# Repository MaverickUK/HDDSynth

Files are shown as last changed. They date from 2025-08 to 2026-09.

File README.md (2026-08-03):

# HDD Synth
<div style="background: white; display: inline-block; padding: 8px;">
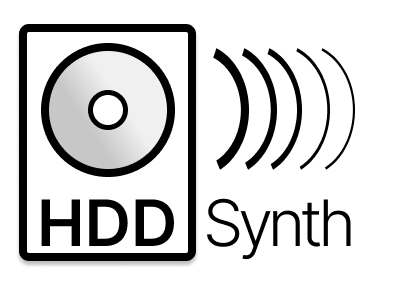
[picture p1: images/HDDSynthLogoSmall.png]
  
</div>

### Recreates the sound of mechanical spinning HDDs on retro PCs that use a solid state drive.

Inspired by seeing the HDD Clicker project and wanting to more faithfully recreate the sound of old mechanical hard drives spinning up and accessing data. Because the hard drive sounds come from samples, it's possible to replace them with any hard drive recording you'd like or something completely different!

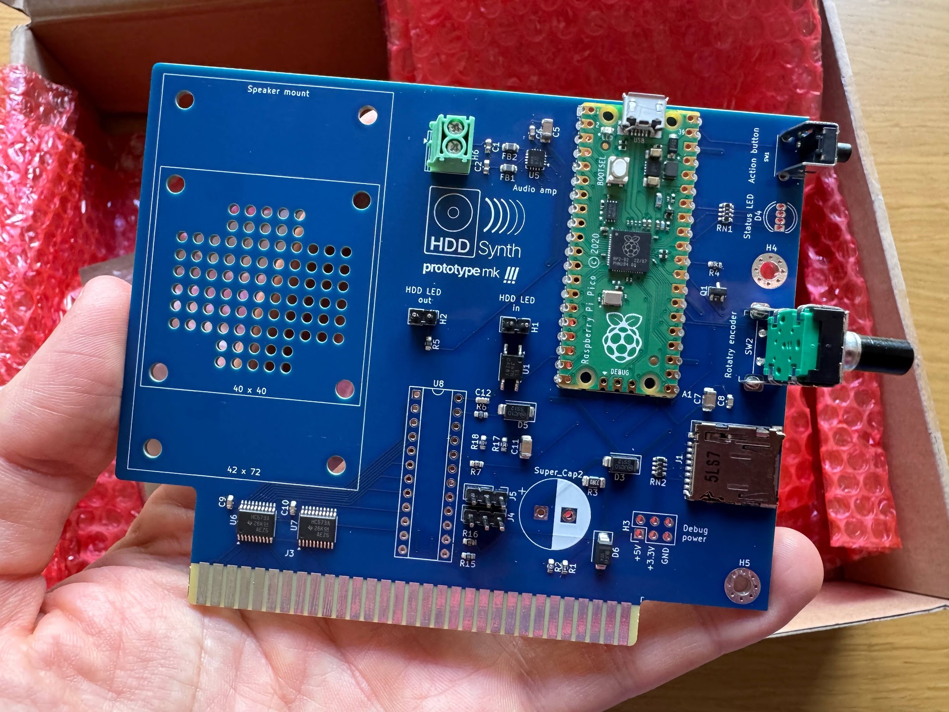
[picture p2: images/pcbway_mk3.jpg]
Photo of the HDD Synth MKIII prototype PCB
  

## Features

- **Sample based recreation** of mechanical hard disk drives operating sounds
 - **Spin up** when PC is turned on
 - **Idle hum** whilst standing by
 - **Access** clicks and crackcles
 - **Spin down** when PC is turned off
- **SD card** to hold multiple HDD sample packs, to recreate the sound of different mechanical hard disk drives
- **Volume control** to make it very loud or silent
- **Balance** to alter the amount of idle to access sounds
- **CompactFlash adapte**r to act as full HDD replacement
- **HDD detection** via HDD LED

## Progress
### ✅ [Phase 1: Breadboard prototype](1_breadboard/README.md) 
### 🔄 Phase 2: PCB prototypes
#### [MKI prototype](2_prototype_mk1/)
Initial ISA PCB test

#### [MKII prototype](2_prototype_mk2/) 
Adds volume control, ability to change sample pack, spin down

#### [MKIII prototype](2_prototype_mk3/) 
Adds ISA based HDD detection, metal back bracket, external status LED, 3.5" drive bay adapter kit, balance (between access and idle sound)

#### [MKIV prototype](2_prototype_mk4/) 
Smaller and more cost effective than the MKIII. Adds a CompactFlash adapter so can act as full HDD replacement. Headless by default, optional controls and OLED screen can be added

### 🌱 Phase 3: PCB final 
*Awaiting completion of prototyping stages*

## Media
[View gallery](media.md)

<!--
## Usage

## License
-->

## Contact
Peter Bridger at [maverickuk@gmail.com](maverickuk@gmail.com)

Project website at [www.strifestreams.com/hddsynth](https://www.strifestreams.com/hddsynth)

## Resources
- [ISA System Architecture by Tom Shanley](https://archive.org/details/ISA_System_Architecture)
- [Intel ISA Bus Specification](https://archive.org/details/bitsavers_intelbusSpep89_3342148)
- [ISA bus technical summary](http://wearcam.org/ece385/lecture6/isa.htm)

## Acknowledgments
- Inspired by the [HDD Clicker project](https://www.serdashop.com/HDDClicker)
- A big thanks to [Ian Scott of PicoGUS fame](https://picog.us/) for sharing his resource sources and knowledge of using the Pi Pico with the ISA bus which gave me the confidence to take this project to the next level
- [Marten Electric](https://www.martenelectric.cz/) for the excellent ISA prototyping boards which made it very easy to wire up the Pico to my computer

### PCBWay
Thanks to [PCBWay](https://www.pcbway.com) for their PCB manufacturing and assembly services. This is my first PCB based project and they've been a great way to get quality PCB prototypes created along with component assembly at competitive prices. Recommended if you're thinking about creating a simular project yourself.

## License
This project is dual-licensed:

- **Software/firmware** is licensed under the [GNU GPL v3.0](LICENSE-CODE).
- **Hardware designs** (schematics, PCB files, BOM) are licensed under
  [CC BY-NC-SA 4.0](LICENSE-HARDWARE) — free for personal, non-commercial
  use and modification, but commercial use requires my permission.

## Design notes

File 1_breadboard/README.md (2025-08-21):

## HDD Synth
### Phase 1: Breadboard based prototypes

Initial work to prove the concept is possible using breadboards and other prototyping hardware along with a series of software based PoCs.

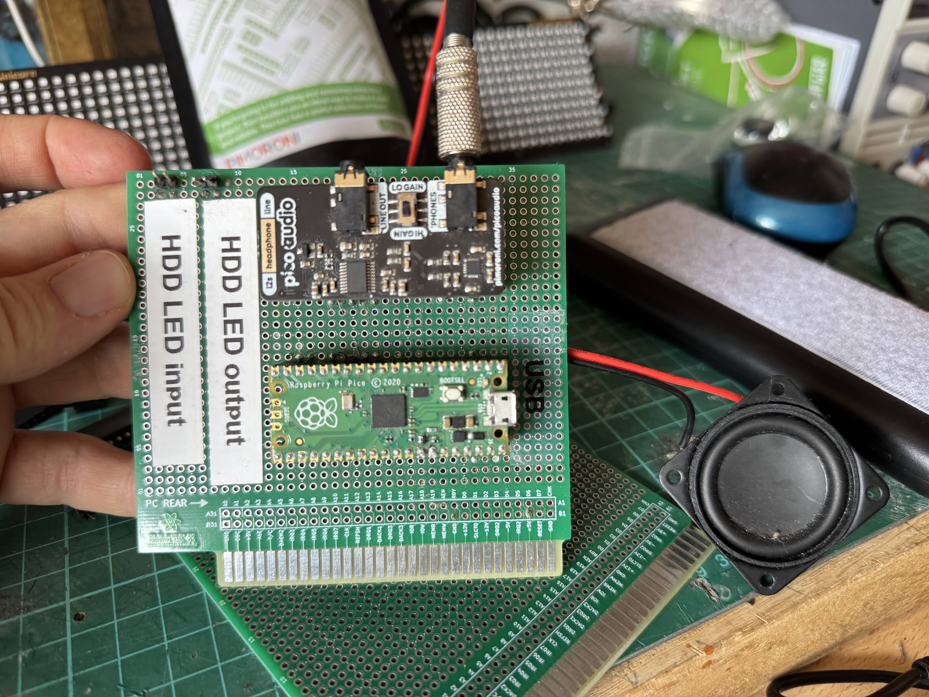
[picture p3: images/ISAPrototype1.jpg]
Prototype ISA board


## Hardware Requirements

### Core Components
- **Raspberry Pi Pico** (RP2040)
- **Pico Audio Pack** for audio output
- **SD Card Module** (SPI interface)
- **ISA Prototyping Board** (e.g., Marten Electric ISA prototyping board)

### Pin Connections

#### ISA Bus Monitoring
| Signal | Pico GPIO | Description |
|---|---|---|
| A0 | GPIO 0 | ISA Address Bus A0 |
| A1 | GPIO 1 | ISA Address Bus A1 |
| A2 | GPIO 2 | ISA Address Bus A2 |
| A3 | GPIO 3 | ISA Address Bus A3 |
| A4 | GPIO 4 | ISA Address Bus A4 |
| A5 | GPIO 5 | ISA Address Bus A5 |
| A6 | GPIO 6 | ISA Address Bus A6 |
| A7 | GPIO 7 | ISA Address Bus A7 |
| A8 | GPIO 8 | ISA Address Bus A8 |
| A9 | GPIO 9 | ISA Address Bus A9 |
| IOR | GPIO 10 | ISA I/O Read signal |
| IOW | GPIO 11 | ISA I/O Write signal |

#### SD Card (SPI)
| Signal | Pico GPIO | Description |
|---|---|---|
| SCK | GPIO 14 | SPI Clock |
| MOSI | GPIO 15 | SPI MOSI |
| MISO | GPIO 12 | SPI MISO |
| CS | GPIO 13 | SPI Chip Select |

#### Audio Output (Pico Audio Pack)
| Signal | Pico GPIO | Description |
|---|---|---|
| BCK | GPIO 26 | Bit Clock (SCK) |
| WS | GPIO 27 | Word Select (WS) |
| SD | GPIO 28 | Serial Data (SD) |
| MUTE | GPIO 22 | Mute control (active low) |

## Audio Sample Files

The following WAV files must be placed on the SD card:

| Filename | Description | Usage |
|---|---|---|
| `hdd_spinup.wav` | HDD spinup sound | Played once when system starts |
| `hdd_idle.wav` | HDD idle sound | Looped continuously when no HDD activity |
| `hdd_access.wav` | HDD access sound | Played during HDD read/write operations |

**Audio Format Requirements:**
- **Sample Rate**: 16 kHz
- **Bit Depth**: 16-bit
- **Channels**: Stereo (2 channels)
- **Format**: WAV (PCM)

## Installation & Setup

### 1. Firmware
- Install MicroPython firmware on your Raspberry Pi Pico
- Download from: https://micropython.org/download/rp2-pico/

### 2. Dependencies
- Copy `sdcard.py` to your Pico's `lib/` directory
- Download from: https://github.com/micropython/micropython/tree/master/drivers/sdcard

### 3. Audio Files
- Format an SD card as FAT32
- Copy the required WAV files to the root directory
- Insert the SD card into the SD card module

### 4. Hardware Assembly
- Connect the Pico to the ISA prototyping board according to the pin mapping above
- Connect the Pico Audio Pack to the Pico
- Connect the SD card module to the Pico
- Mount the ISA board in your PC's ISA slot

### 5. Software
- Copy `main.py` and `config.py` to your Pico
- The system will auto-execute `main.py` on boot

## Configuration

Edit `config.py` to customize:
- Pin assignments for different hardware setups
- Audio settings (sample rate, bit depth, channels)
- HDD activity detection parameters
- Audio file names

## Usage

1. **Power On**: The system will automatically start monitoring the ISA bus
2. **Spinup**: HDD spinup sound plays once during initialization
3. **Idle**: HDD idle sound loops continuously when no activity is detected
4. **Access**: HDD access sound plays during read/write operations
5. **Real-time Response**: Audio changes immediately based on detected HDD activity

## How It Works

### ISA Bus Monitoring
The system uses PIO (Programmable I/O) state machines to monitor the ISA bus at high speed:
- **State Machine 0**: Monitors IOR (I/O Read) signals
- **State Machine 1**: Monitors IOW (I/O Write) signals
- **Address Capture**: Captures A0-A9 address lines when control signals are active
- **HDD Detection**: Identifies HDD activity by monitoring ports 0x1F0 (data) and 0x1F7 (status)

### Audio Management
- **Spinup**: Played once at startup to simulate HDD initialization
- **Idle**: Looped continuously when no HDD activity is detected
- **Access**: Interrupts idle sound and plays during HDD operations
- **Seamless Transitions**: Audio switches instantly between states

### SD Card Integration
- **File Loading**: Audio files loaded directly from SD card
- **Real-time Playback**: No buffering delays for immediate response
- **Easy Customization**: Replace WAV files to change sounds

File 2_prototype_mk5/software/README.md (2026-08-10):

# HDD Synth: Prototype MKIII
Written in CircuitPython for Pi Pico

## Startup Behavior

The SDCARD_REQUIRED setting (configured in settings.py, default False) controls startup behavior:

- **SDCARD_REQUIRED = True (strict mode):** Device requires SD card to start. If no SD card is detected, it will play a NO_SD_CARD beep and not run.
- **SDCARD_REQUIRED = False (relaxed mode):** Device can start without SD card if a sample pack is already installed internally. If no sample pack is installed, it will play a PACK_NOT_FOUND beep. When running without an SD card, the action button is disabled (sample pack switching and factory reset are unavailable).

## settings.json
If this file exists on the SD card install in the HDD Synth it will be read at startup and will override the default HDD Synth settings.

This can be used to configure the HDD Synth to operate in headless mode without any physical controls.

### Settings
- **SIMULATION_MODE:** Boolean. True will simulate HDD activity for testing without actual HDD, False will use real HDD activity signal. Default False
- **PLAY_SPINUP:** Boolean. True will play spinup sound at power on, False will not. Default True
- **PLAY_SPINDOWN:** Boolean. True will play spindown sound at power off, False will not. Default True
- **PLAY_IDLE:** Boolean. True will play idle sound continously, False will not. Default True
- **ACCESS_HOLD_TIME_MS:** Integer. How long to play the access sound for after detect activity stops in milliseconds. Default 500
- **VOLUME_DEFAULT:** Number between 0 and 1. 0 is silence, 1 is full volume. Default 0.5
- **BALANCE_DEFAULT:** Number between 0 and 1. 0 = idle only, 1 = access only, 0.5 balanced idle and access. Default 0.5
- **SAMPLE_PACK:** Name of the sample pack directory on the SD card to use. E.g. If /samples/ibm is desired, this should be set to ibm
- **SDCARD_CACHE_SAMPLES:** Boolean. True will copy the sample pack from the SD card to the Pico's internal flash before playback — the SD card can then be removed after boot. False will stream samples directly from the SD card, which is faster to start but requires the SD card to remain inserted. Default False
- **ACTIVITY_LED_ENABLED:** Boolean. True lights the RGB status LED while the HDD is being accessed, False disables the activity indication entirely. Default True
- **ACTIVITY_LED_COLOUR:** The colour shown on the RGB status LED during HDD activity. Either a hex string such as `"#00FF00"` or an array of three 0-255 values such as `[0, 255, 0]`. Default green
- **RGB_LED_BRIGHTNESS:** Number between 0 and 1. Master brightness applied to every colour the RGB status LED shows — activity, error and operation flashes, and the busy indicator. 0 turns the LED off entirely, 1 is full brightness. Default 0.5

### Example settings.json
```
{
    "SIMULATION_MODE": false,
    "PLAY_SPINUP": false,
    "PLAY_SPINDOWN": true,
    "PLAY_IDLE": true,
    "ACCESS_HOLD_TIME_MS": 150,
    "VOLUME_DEFAULT": 0.7,
    "BALANCE_DEFAULT": 0.5,
    "SAMPLE_PACK": "my_pack_name",
    "SDCARD_CACHE_SAMPLES": false,
    "ACTIVITY_LED_ENABLED": true,
    "ACTIVITY_LED_COLOUR": "#00FF00",
    "RGB_LED_BRIGHTNESS": 0.5
}
```

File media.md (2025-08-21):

# HDD Synth media

## Phase 2: PCB prototype

KiCad 3D render of MK1 prototype board

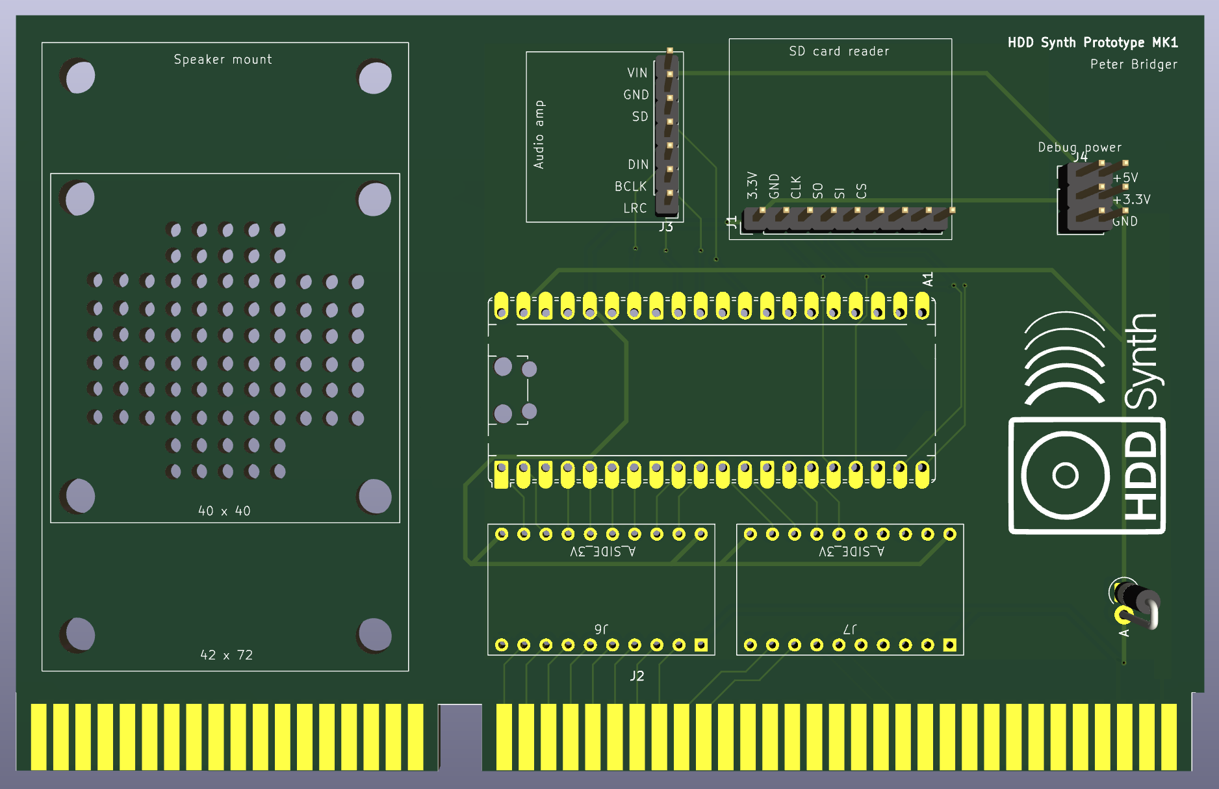
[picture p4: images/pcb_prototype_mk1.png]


KiCad PCB layout of MK1 prototype board

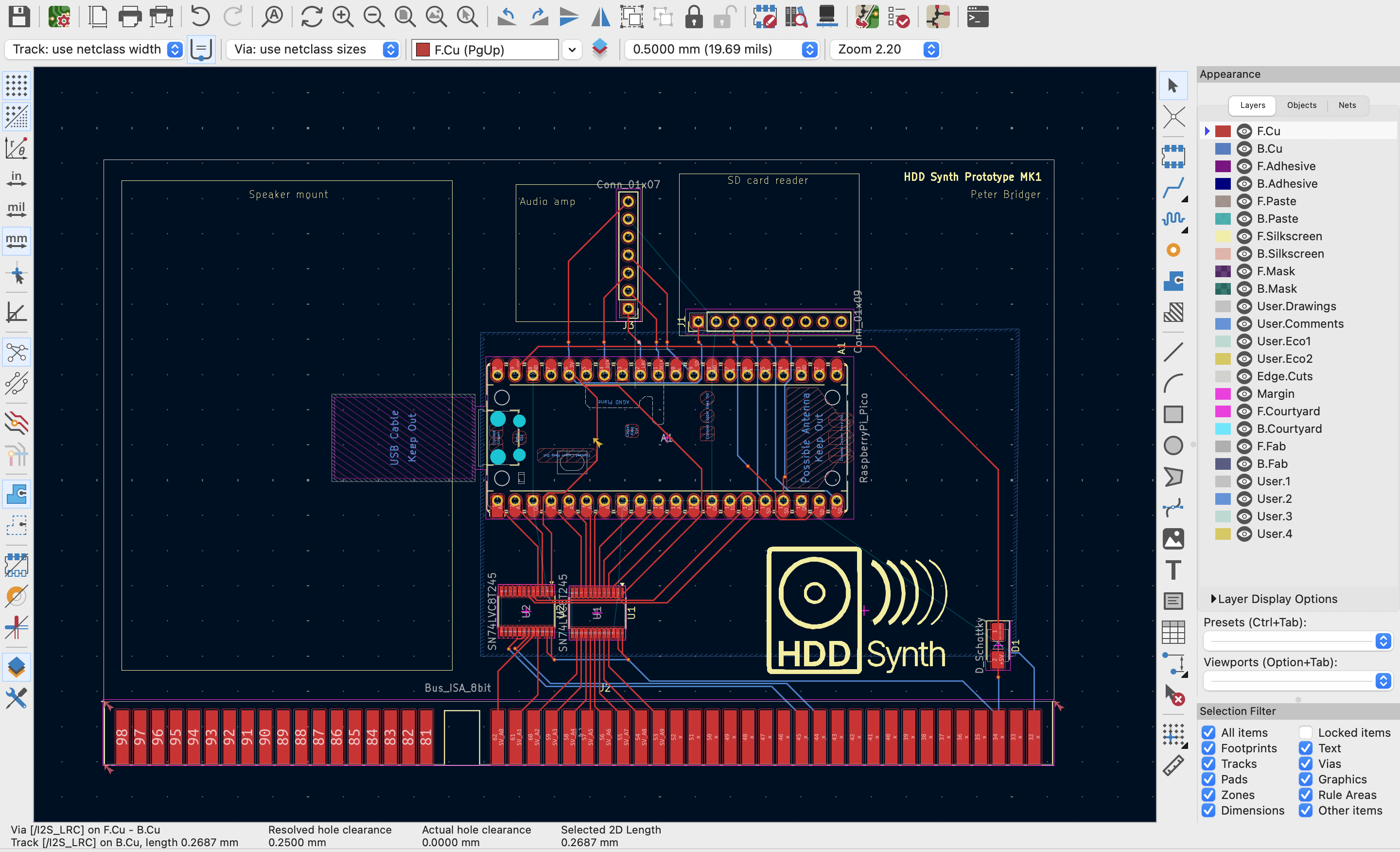
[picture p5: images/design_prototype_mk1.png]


## Phase 1: Breadboard prototype

### Powered ISA board
Initial prototype of an ISA board that can be mounted within the PC to draw power from the ISA +5v rail

Prototype ISA board

### HDD LED detection prototype board
Using detection of the PC HDD controller activity LED voltage to detect activity and drive the HDD Synth

Proof of concept video (https://youtu.be/yZhKAbbrKRM)

### Audio samples proof of concept
Not connected to a PC, but purely to validate if the Pi Pico could produce a convincing sounding HDD subsitution. I'd say it does!

Proof of concept video (https://youtu.be/V0S9wBl7J3U)

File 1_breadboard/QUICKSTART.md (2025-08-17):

# HDD Synth - Quick Start Guide

## What You Need

### Hardware
- [ ] Raspberry Pi Pico
- [ ] Pico Audio Pack
- [ ] SD Card Module (SPI)
- [ ] ISA Prototyping Board
- [ ] MicroSD Card (FAT32 formatted)
- [ ] Audio samples (WAV files)
- [ ] 2 x TXS0108E level shifter (Convert 5v ISA signals to 3.3v Pico)
- [ ] Prototyping ISA board

### Software
- [ ] MicroPython firmware on Pico
- [ ] `sdcard.py` library
- [ ] HDD Synth files

## Setup

### Step 0: Aquire prototype ISA PCB
Contains the TXS level shifters connected to the ISA address bus, IOR and IOW lines

### Step 1: Prepare Your Pico
1. Download MicroPython firmware: https://micropython.org/download/rp2-pico/
2. Hold BOOTSEL button and plug in Pico
3. Copy firmware to Pico (it will appear as USB drive)
4. Pico will restart with MicroPython

### Step 2: Install Dependencies
1. Download `sdcard.py` from: https://github.com/micropython/micropython/tree/master/drivers/sdcard
2. Copy to Pico's `lib/` folder (create if it doesn't exist)

### Step 3: Prepare Audio Files
1. Format SD card as FAT32
2. Copy these WAV files to root directory:
   - `hdd_spinup.wav`
   - `hdd_idle.wav`
   - `hdd_access.wav`
3. Insert SD card into module

### Step 4: Wire Up Hardware
Connect according to this pin map:

| Component | Pico GPIO | Signal |
|---|---|---|
| ISA A0-A9 | GPIO 0-9  | Address bus |
| ISA IOR | GPIO 10 | I/O Read |
| ISA IOW | GPIO 11 | I/O Write |
| SD SCK | GPIO 14 | SPI Clock |
| SD MOSI | GPIO 15 | SPI MOSI |
| SD MISO | GPIO 12 | SPI MISO |
| SD CS | GPIO 13 | SPI CS |
| Audio BCK | GPIO 26 | Bit Clock |
| Audio WS  | GPIO 27 | Word Select |
| Audio SD  | GPIO 28 | Serial Data |
| Audio MUTE| GPIO 22 | Mute control |

### Step 5: Upload Code
1. Copy `main.py` to Pico
2. Copy `config.py` to Pico
3. The system will auto-start with `main.py`

### Step 6: Test
1. Power on your Pico
2. You should hear the HDD spinup sound
3. Then idle sound will loop continuously
4. When you access files on your PC, you should hear access sounds

## Troubleshooting

### No Audio Output
- Check Pico Audio Pack connections
- Verify MUTE pin is connected to GPIO 22
- Ensure audio files are 16kHz, 16-bit, stereo WAV

### SD Card Not Found
- Check SPI connections (SCK, MOSI, MISO, CS)
- Verify SD card is FAT32 formatted
- Ensure audio files are in root directory

### ISA Bus Not Detected
- Verify all address pins (A0-A9) are connected
- Check IOR and IOW connections
- Ensure ISA board is properly seated

### Audio Cuts Out
- Check power supply (Pico needs stable 5V)
- Verify SD card is high-speed (Class 10+)
- Reduce audio buffer size in config if needed

## Customization

### Change Audio Files
1. Replace WAV files on SD card
2. Update filenames in `config.py`
3. Ensure new files match format requirements

### Adjust Pin Assignments
1. Edit `config.py`
2. Modify pin numbers as needed
3. Restart Pico

### Tune Detection Sensitivity
1. Adjust `ACTIVITY_THRESHOLD` in config
2. Modify `ACTIVITY_TIMEOUT_MS` for response speed
3. Test with your specific hardware

## Need Help?

- Check the main README.md for detailed information
- Review pin connections carefully
- Test with `test.py` first
- Ensure all hardware is properly connected

## Success!

Once working, your HDD Synth will:
- ✅ Play spinup sound on power-up
- ✅ Loop idle sound when no activity
- ✅ Play access sounds during HDD operations
- ✅ Respond in real-time to ISA bus activity
- ✅ Work as a plug-and-play ISA card

Enjoy your authentic mechanical HDD sounds! 🎵

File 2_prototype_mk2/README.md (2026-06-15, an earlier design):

## HDD Synth
### Prototype MKII

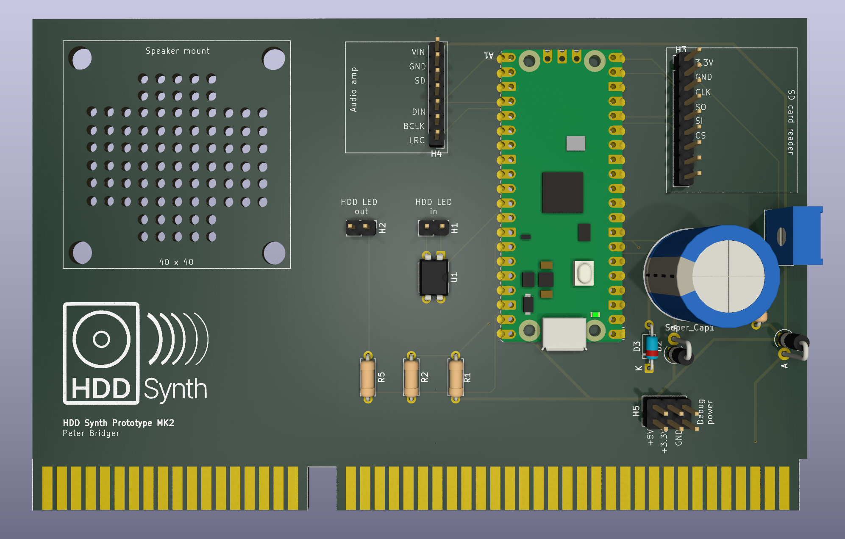
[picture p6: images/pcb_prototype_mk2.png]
KiCad PCB 3D render


#### Hardware
Designed in KiCad and manufacufered by PCBWay

Uses through hole components and breakout boards for the SD card reader and audio amp

#### Software
Runs CircuitPython for ease of development

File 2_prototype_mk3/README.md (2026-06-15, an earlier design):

## HDD Synth
### Prototype MKIII

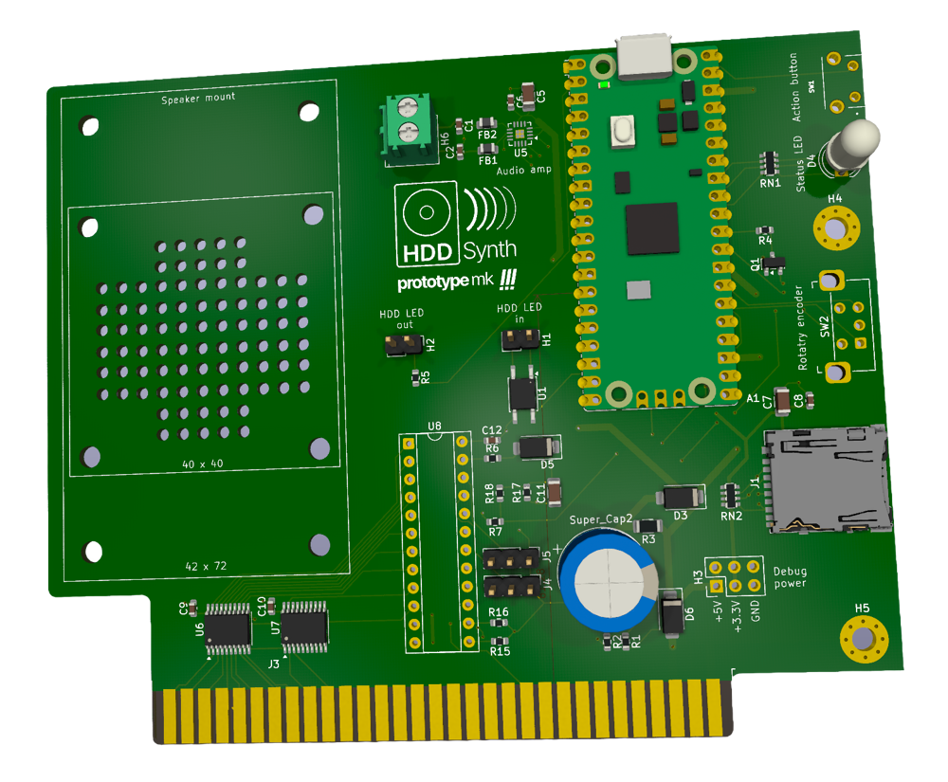
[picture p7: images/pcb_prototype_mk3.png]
KiCad PCB 3D render


#### Hardware
Designed in KiCad and manufacufered by PCBWay with factory assembly of components

Uses mostly surface mounted components for ease of automated assembly and reduction in size and cost

#### Software
Runs CircuitPython for ease of development

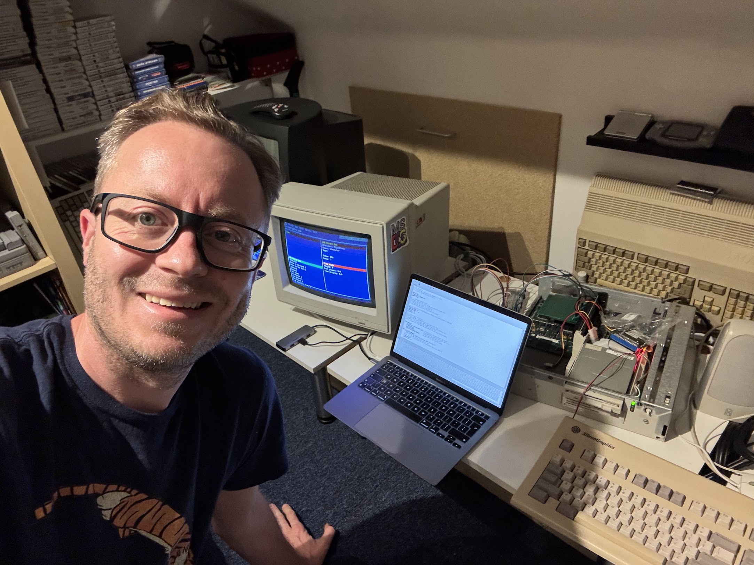
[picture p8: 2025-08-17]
images/HDDSynth first.jpg

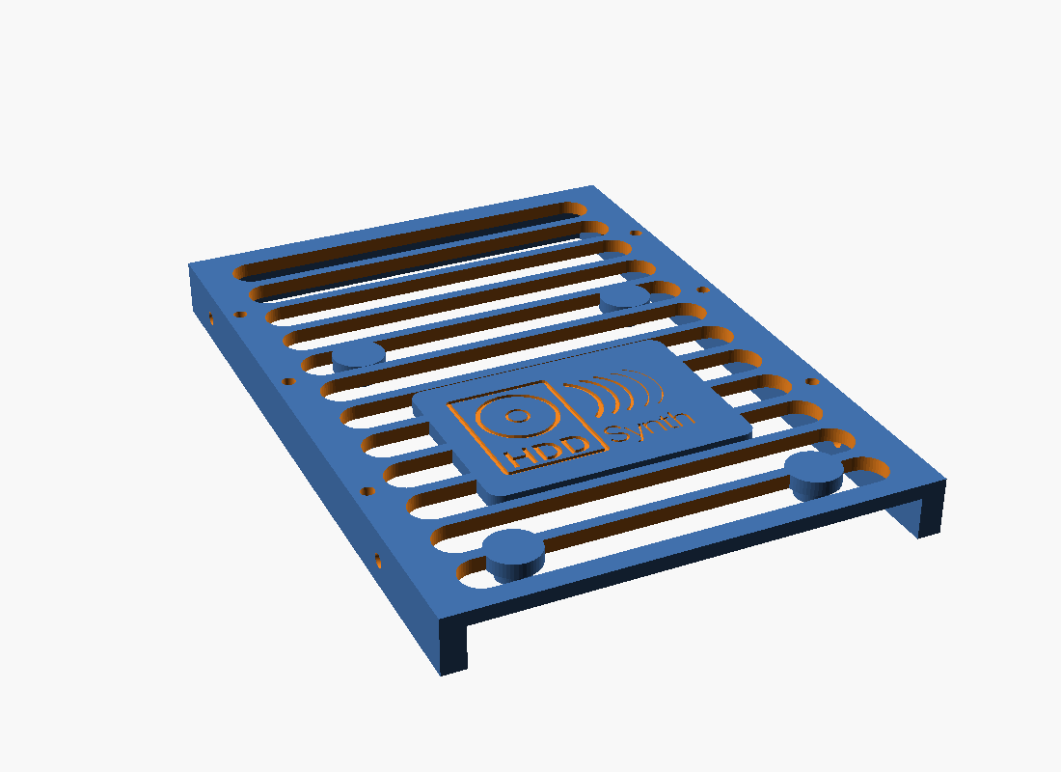
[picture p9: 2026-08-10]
2_prototype_mk5/3d_models/drive_bay/tray_iso.png

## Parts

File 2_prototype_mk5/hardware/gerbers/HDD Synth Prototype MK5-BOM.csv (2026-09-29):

Reference | Qty | Value | DNP | Exclude from BOM | Exclude from Board | LCSC Part Number | Footprint | Datasheet | Description
C1,C6,C26 | 3 | 0.1uF |  |  |  | C14663 | Capacitor_SMD:C_0603_1608Metric |  | Unpolarized capacitor
C2,C5 | 2 | 10uF |  |  |  | C13585 | Capacitor_SMD:C_1206_3216Metric |  | Unpolarized capacitor
C3,C4 | 2 | 1nF |  |  |  | C1588 | Capacitor_SMD:C_0603_1608Metric |  | Unpolarized capacitor, small symbol
C7,C8 | 2 | 15p |  |  |  | C1548 | Capacitor_SMD:C_0402_1005Metric
C10,C14,C17,C18,C19,C20,C21,C22,C23,C24,C27,C33 | 12 | 100nF |  |  |  | C1525 | Capacitor_SMD:C_0402_1005Metric
C12,C13 | 2 | 4.7uF |  |  |  | C23733 | RP2350:C_0402_1005Metric_small_pads
C15,C16 | 2 | 4.7uF |  |  |  | C23733 | Capacitor_SMD:C_0402_1005Metric
C25,C28,C30,C36,C37 | 5 | 10uF |  |  |  | C15850 | Capacitor_SMD:C_0805_2012Metric
C29,C31,C32,C39 | 4 | 22uF |  |  |  | C45783 | Capacitor_SMD:C_0805_2012Metric
C34 | 1 | 4.7nF |  |  |  |  | Capacitor_SMD:C_0402_1005Metric
C35 | 1 | 1uF |  |  |  |  | Capacitor_SMD:C_0402_1005Metric
C38 | 1 | 100uF |  |  |  | C134801 | Capacitor_SMD:CP_Elec_6.3x7.7 |  | Polarized capacitor
Card1 | 1 | TF-015 |  |  |  | C113206 | easyeda2kicad:TF-SMD_TF-015 | https://lcsc.com/product-detail/Card-Sockets_TF-015_C113206.html
D1 | 1 | SMAJ5.0A |  |  |  |  | Diode_SMD:D_SMA |  | Zener diode
D3 | 1 | 1N4148W |  |  |  | C81598 | Diode_SMD:D_SOD-123 | https://www.vishay.com/docs/85748/1n4148w.pdf | 75V 0.15A Fast Switching Diode, SOD-123
FB1,FB2 | 2 | FerriteBead_Small |  |  |  | C85840 | Inductor_SMD:L_0805_2012Metric |  | Ferrite bead, small symbol
H1,H2,H3,H13,H14 | 5 | Conn_01x02 |  |  |  | C124375 | Connector_PinHeader_2.54mm:PinHeader_1x02_P2.54mm_Vertical |  | Generic connector, single row, 01x02, script generated (kicad-library-utils/schlib/autogen/connector/)
J2 | 1 | Conn_01x03 |  |  |  | C49257 | Connector_PinHeader_2.54mm:PinHeader_1x03_P2.54mm_Vertical |  | Generic connector, single row, 01x03, script generated (kicad-library-utils/schlib/autogen/connector/)
J4 | 1 | USB_C_Receptacle_USB2.0_16P |  |  |  | C165948 | Connector_USB:USB_C_Receptacle_HRO_TYPE-C-31-M-12 |  | USB 2.0-only 16P Type-C Receptacle connector
J6 | 1 | Conn_01x04_Pin |  |  |  | C124378 | Connector_PinHeader_2.54mm:PinHeader_1x04_P2.54mm_Vertical |  | Generic connector, single row, 01x04, script generated
J7 | 1 | Conn_01x05 |  |  |  | C124379 | Connector_PinHeader_2.54mm:PinHeader_1x05_P2.54mm_Vertical |  | Generic connector, single row, 01x05, script generated (kicad-library-utils/schlib/autogen/connector/)
L1 | 1 | 3.3u |  |  |  | C42411119 | RP2350:L_pol_2016
L2 | 1 | 2.2 µH |  |  |  | C167804 | easyeda2kicad:IND-SMD_L4.0-W4.0_FNR40XXS |  | Inductor
L3 | 1 | FNR4018S1R5MT |  |  |  | C167802 | easyeda2kicad:IND-SMD_L4.0-W4.0_FNR40XXS | https://lcsc.com/product-detail/Power-Inductors_1-5uH-20_C167802.html
LED1 | 1 | XL-3528RGBW-HM |  |  |  | C2843813 | Custom:LED-SMD_4P-L3.2-W2.8-LS3.5-XL-3528RGBW-HM5 | https://www.lcsc.com/datasheet/C2843813.pdf
Q1 | 1 | 2N7002 |  |  |  | C8545 | Package_TO_SOT_SMD:SOT-23 | https://www.onsemi.com/pub/Collateral/NDS7002A-D.PDF | 0.115A Id, 60V Vds, N-Channel MOSFET, SOT-23
R1,R2 | 2 | 330R |  |  |  | C23138 | Resistor_SMD:R_0603_1608Metric |  | Resistor
R7 | 1 | 0 |  |  |  | C17168 | Resistor_SMD:R_0402_1005Metric
R8,R11 | 2 | 5.1K |  |  |  | C25905 | Resistor_SMD:R_0402_1005Metric |  | Resistor
R10,R12,R14,R26 | 4 | 1K |  |  |  | C11702 | Resistor_SMD:R_0402_1005Metric |  | Resistor
R13,R18,R20 | 3 | 33R |  |  |  | C25105 | Resistor_SMD:R_0402_1005Metric |  | Resistor
R15,R16 | 2 | 27R |  |  |  | C25100 | Resistor_SMD:R_0402_1005Metric
R17,R30,R40,R41 | 4 | 100K |  |  |  | C25741 | Resistor_SMD:R_0402_1005Metric |  | Resistor
R19 | 1 | 200R |  |  |  | C25087 | Resistor_SMD:R_0402_1005Metric |  | Resistor
R22 | 1 | 22K |  |  |  | C25768 | Resistor_SMD:R_0402_1005Metric |  | Resistor
R23,R35 | 2 | 10K |  |  |  | C25744 | Resistor_SMD:R_0402_1005Metric |  | Resistor
R24,R25 | 2 | 22K |  |  |  | C31850 | Resistor_SMD:R_0603_1608Metric |  | Resistor
R27,R28,R29,R33 | 4 | 47K |  |  |  | C25792 | Resistor_SMD:R_0402_1005Metric |  | Resistor
R31 | 1 | 24K |  |  |  | C25769 | Resistor_SMD:R_0402_1005Metric |  | Resistor
R32 | 1 | 330K |  |  |  | C25778 | Resistor_SMD:R_0402_1005Metric |  | Resistor
R34 | 1 | 120K |  |  |  | C25750 | Resistor_SMD:R_0402_1005Metric |  | Resistor
R36 | 1 | 110K |  |  |  | C2909311 | Resistor_SMD:R_0402_1005Metric |  | Resistor
R37,R38,R39 | 3 | 75K |  |  |  | C25798 | Resistor_SMD:R_0402_1005Metric |  | Resistor
S1,S2 | 2 | TS-1187A-B-A-B |  |  |  | C318884 | Custom:SW_TS-1187A-B-A-B |  | Tactile Switch SPST 160gf 1.5mm 5.1mm x 5.1mm Surface Mount
U1 | 1 | Optocoupler_DC_PhotoNPN_AKEC |  |  |  | C42381015 | Package_SO:SO-4_4.4x3.6mm_P2.54mm |  | Generic DC optocoupler with NPN phototransistor output, pins order: anode/cathode/emitter/collector
U2 | 1 | MAX98357A |  |  |  | C910544 | Package_DFN_QFN:TQFN-16-1EP_3x3mm_P0.5mm_EP1.23x1.23mm | https://www.analog.com/media/en/technical-documentation/data-sheets/MAX98357A-MAX98357B.pdf | Mono DAC with amplifier, I2S, PCM, TDM, 32-bit, 96khz, 3.2W, TQFP-16
U5 | 1 | RP2350_60QFN |  |  |  | C41378174 | RP2350:RP2350-QFN-60-1EP_7x7_P0.4mm_EP3.4x3.4mm_ThermalVias
U6 | 1 | TPS63020DSJR |  |  |  | C15483 | easyeda2kicad:VSON-14_L4.0-W3.0-P0.50-BL-EP_TI_DSJ | https://lcsc.com/product-detail/DC-DC-Converters_TI_TPS63020DSJR_TPS63020DSJR_C15483.html
U7 | 1 | KF350-3.5-2P |  |  |  | C474892 | easyeda2kicad:CONN-TH_P3.50_KF350-3.5-2P | https://lcsc.com/product-detail/New-Quadratic-Unclassified-Data_Cixi-Kefa-Elec-KF350-3-5-2P_C474892.html
U8 | 1 | TPS25921ADR |  |  |  | C189199 | easyeda2kicad:SOIC-8_L5.0-W4.0-P1.27-LS6.0-BL | https://lcsc.com/product-detail/PMIC-Supervisors_TI_TPS25921ADR_TPS25921ADR_C189199.html
U9 | 1 | TPS61094DSSR |  |  |  | C3034939 | easyeda2kicad:WSON-12_L3.0-W2.0-P0.5-BL-EP | https://www.lcsc.com/datasheet/C3034939.pdf
Y1 | 1 | ABM8-272-T3 |  |  |  | C20617575 | Crystal:Crystal_SMD_3225-4Pin_3.2x2.5mm

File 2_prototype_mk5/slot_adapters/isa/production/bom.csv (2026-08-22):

Designator | Footprint | Quantity | Value | LCSC Part #
J1, J4 | PinSocket_1x02_P2.54mm_Vertical | 2 | Conn_01x02_Socket
J2 | PinSocket_1x05_P2.54mm_Vertical | 1 | Conn_01x05_Socket
SW1 | PTS645VL582LFS | 1 | SW_Push
SW2 | RotaryEncoder_Bourns_Horizontal_PEC12R-2x17F-Sxxxx | 1 | PEC12R-2120F-S0012

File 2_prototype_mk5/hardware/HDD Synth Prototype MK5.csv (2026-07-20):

Reference | Qty | Value | DNP | Exclude from BOM | Exclude from Board | LCSC | Footprint | Datasheet | Description
C1,C6,C26,C27 | 4 | 0.1uF |  |  |  | C14663 | Capacitor_SMD:C_0603_1608Metric |  | Unpolarized capacitor
C2,C5 | 2 | 10uF |  |  |  | C13585 | Capacitor_SMD:C_1206_3216Metric |  | Unpolarized capacitor
C3,C4 | 2 | 1nF |  |  |  | C1588 | Capacitor_SMD:C_0603_1608Metric |  | Unpolarized capacitor, small symbol
C7,C8 | 2 | 15p |  |  |  | C1548 | Capacitor_SMD:C_0402_1005Metric
C9,C11,C25 | 3 | 10uF |  |  |  | C15850 | Capacitor_SMD:C_0805_2012Metric
C10,C14,C17,C18,C19,C20,C21,C22,C23,C24 | 10 | 100nF |  |  |  | C1525 | Capacitor_SMD:C_0402_1005Metric
C12,C13 | 2 | 4.7uF |  |  |  | C23733 | RP2350:C_0402_1005Metric_small_pads
C15,C16 | 2 | 4.7uF |  |  |  | C23733 | Capacitor_SMD:C_0402_1005Metric
D1 | 1 | SS14 |  |  |  | C2480 | Diode_SMD:D_SMA |  | 1A, 40V Schottky diode
D2 | 1 | SS12 |  |  |  | C2479 | Diode_SMD:D_SMA |  | Schottky diode
D3 | 1 | 1N4148W |  |  |  | C81598 | Diode_SMD:D_SOD-123 | https://www.vishay.com/docs/85748/1n4148w.pdf | 75V 0.15A Fast Switching Diode, SOD-123
D4 | 1 | WS2812B |  |  |  | C2761795 | LED_SMD:LED_WS2812B_PLCC4_5.0x5.0mm_P3.2mm | https://cdn-shop.adafruit.com/datasheets/WS2812B.pdf | RGB LED with integrated controller
FB1,FB2 | 2 | FerriteBead_Small |  |  |  | C85840 | Inductor_SMD:L_0805_2012Metric |  | Ferrite bead, small symbol
H1,H2,H3,H13 | 4 | Conn_01x02 |  |  |  | C124375 | Connector_PinHeader_2.54mm:PinHeader_1x02_P2.54mm_Vertical |  | Generic connector, single row, 01x02, script generated (kicad-library-utils/schlib/autogen/connector/)
H12 | 1 | Conn_01x02 |  |  |  | C3819527 | TerminalBlock_Phoenix:TerminalBlock_Phoenix_PT-1,5-2-3.5-H_1x02_P3.50mm_Horizontal |  | Generic connector, single row, 01x02, script generated (kicad-library-utils/schlib/autogen/connector/)
J1 | 1 | Micro_SD_Card |  |  |  | C719027 | Connector_Card:microSD_HC_Hirose_DM3D-SF |  | Micro SD Card Socket - Hirose DM3D-SF
J2 | 1 | Conn_01x03 |  |  |  | C49257 | Connector_PinHeader_2.54mm:PinHeader_1x03_P2.54mm_Vertical |  | Generic connector, single row, 01x03, script generated (kicad-library-utils/schlib/autogen/connector/)
J4 | 1 | USB_C_Receptacle_USB2.0_16P |  |  |  | C165948 | Connector_USB:USB_C_Receptacle_HRO_TYPE-C-31-M-12 |  | USB 2.0-only 16P Type-C Receptacle connector
J6 | 1 | Conn_01x04_Pin |  |  |  | C124378 | Connector_PinHeader_2.54mm:PinHeader_1x04_P2.54mm_Vertical |  | Generic connector, single row, 01x04, script generated
J7 | 1 | Conn_01x05 |  |  |  | C124379 | Connector_PinHeader_2.54mm:PinHeader_1x05_P2.54mm_Vertical |  | Generic connector, single row, 01x05, script generated (kicad-library-utils/schlib/autogen/connector/)
L1 | 1 | 3.3u |  |  |  | C42411119 | RP2350:L_pol_2016
Q1 | 1 | 2N7002 |  |  |  | C332103 | Package_TO_SOT_SMD:SOT-23 | https://www.onsemi.com/pub/Collateral/NDS7002A-D.PDF | 0.115A Id, 60V Vds, N-Channel MOSFET, SOT-23
R1,R2 | 2 | 330R |  |  |  | C23138 | Resistor_SMD:R_0603_1608Metric |  | Resistor
R3 | 1 | 1K |  |  |  | C21190 | Resistor_SMD:R_0603_1608Metric |  | Resistor
R4 | 1 | 2K |  |  |  | C4184 | Resistor_SMD:R_0603_1608Metric |  | Resistor
R5 | 1 | 47R |  |  |  | C3013388 | Resistor_SMD:R_2512_6332Metric |  | Yageo, 47Ω, ±1%, 2W, anti-surge, 2512
R6,R9 | 2 | DNF |  |  |  | C25105 | Resistor_SMD:R_0402_1005Metric
R7 | 1 | 0 |  |  |  | C17168 | Resistor_SMD:R_0402_1005Metric
R8,R11 | 2 | 5.1K |  |  |  | C25905 | Resistor_SMD:R_0402_1005Metric |  | Resistor
R10,R12,R14 | 3 | 1k |  |  |  | C11702 | Resistor_SMD:R_0402_1005Metric
R13 | 1 | 33R |  |  |  | C25105 | Resistor_SMD:R_0402_1005Metric
R15,R16 | 2 | 27R |  |  |  | C138021 | Resistor_SMD:R_0402_1005Metric
R17 | 1 | 100K |  |  |  | C60491 | Resistor_SMD:R_0402_1005Metric |  | Resistor
RN1 | 1 | 47K |  |  |  | C779384 | Resistor_SMD:R_Array_Convex_4x0603 |  | 4 resistor network, parallel topology
S1,S2 | 2 | TS-1187A-B-A-B |  |  |  | C318884 | Custom:SW_TS-1187A-B-A-B |  | Tactile Switch SPST 160gf 1.5mm 5.1mm x 5.1mm Surface Mount
Super_Cap1 | 1 | 1F |  |  |  |  | Capacitor_THT:CP_Radial_D14.0mm_P5.00mm | https://resources.kitronik.co.uk/pdf/super_capacitor.pdf | polarized radial super capacitor, 1F 5.5V
U1 | 1 | Optocoupler_DC_PhotoNPN_AKEC |  |  |  | C2916312 | Package_SO:SO-4_4.4x3.6mm_P2.54mm |  | Generic DC optocoupler with NPN phototransistor output, pins order: anode/cathode/emitter/collector
U2 | 1 | MAX98357A |  |  |  | C910544 | Package_DFN_QFN:TQFN-16-1EP_3x3mm_P0.5mm_EP1.23x1.23mm | https://www.analog.com/media/en/technical-documentation/data-sheets/MAX98357A-MAX98357B.pdf | Mono DAC with amplifier, I2S, PCM, TDM, 32-bit, 96khz, 3.2W, TQFP-16
U3 | 1 | W25Q128JVS |  |  |  | C83140 | RP2350:SOIC-8_5.23x5.23mm_P1.27mm | http://www.winbond.com/resource-files/w25q128jv_dtr%20revc%2003272018%20plus.pdf
U4 | 1 | NCP1117-3.3_SOT223 |  |  |  | C26537 | Package_TO_SOT_SMD:SOT-223-3_TabPin2 | http://www.onsemi.com/pub_link/Collateral/NCP1117-D.PDF
U5 | 1 | RP2350_60QFN |  |  |  | C42411118 | RP2350:RP2350-QFN-60-1EP_7x7_P0.4mm_EP3.4x3.4mm_ThermalVias
Y1 | 1 | ABM8-272-T3 |  |  |  | C20625731 | Crystal:Crystal_SMD_3225-4Pin_3.2x2.5mm

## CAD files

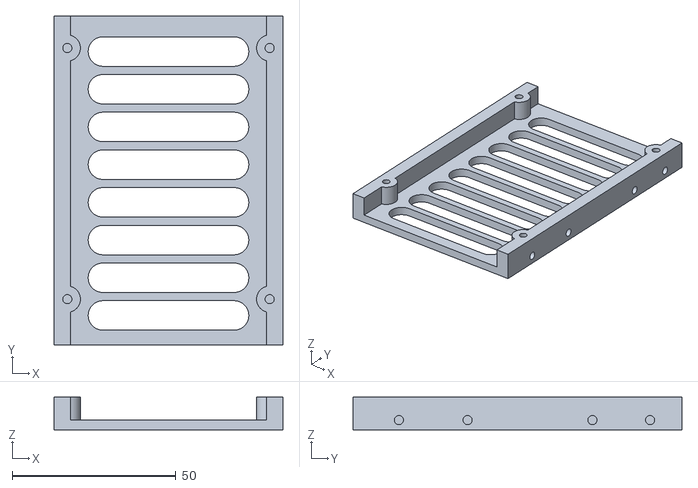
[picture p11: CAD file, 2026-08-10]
2_prototype_mk5/3d_models/drive_bay/hddsynth_25_sidemount.stl
69.8 x 100.3 x 10.0

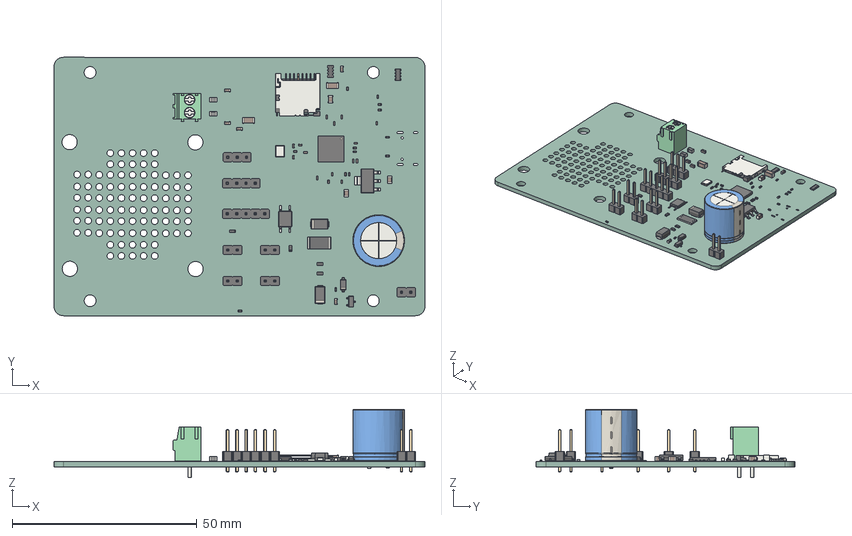
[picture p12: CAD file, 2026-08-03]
2_prototype_mk5/hardware/MKV.step
100.3 x 69.9 x 18.5 mm
R_0402_1005Metric x 12
microSD_HC_Hirose_DM3D-SF
R_Array_Convex_4x0603 x 2
SOT-23
C_0402_1005Metric x 16
D_SMA x 2
C_0603_1608Metric x 5
PinHeader_1x05_P254mm_Vertical
C_1206_3216Metric x 2
C_0805_2012Metric x 3
D_SOD-123
R_2512_6332Metric
R_0603_1608Metric x 4
PinHeader_1x02_P254mm_Vertical x 5
QFN-56-1EP_7x7mm_Pitch0.4mm
L_0805_2012Metric x 2
Crystal_SMD_3225-4Pin_3.2x2.5mm
TerminalBlock_Phoenix_PT-1,5-2-3.5-H_1x02_P3.50mm_Horizontal
SO-4_4.4x3.6mm_P2.54mm
CP_Radial_D140mm_P500mm
SOT-223
PinHeader_1x04_P254mm_Vertical
PinHeader_1x03_P254mm_Vertical
HDD Synth Prototype MK5_PCB

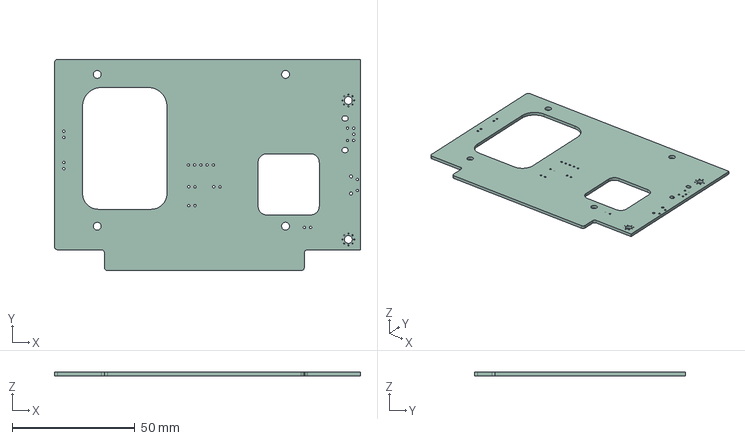
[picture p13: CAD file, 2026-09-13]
2_prototype_mk5/slot_adapters/isa/ISA_adapter.step
124.5 x 85.9 x 1.51 mm

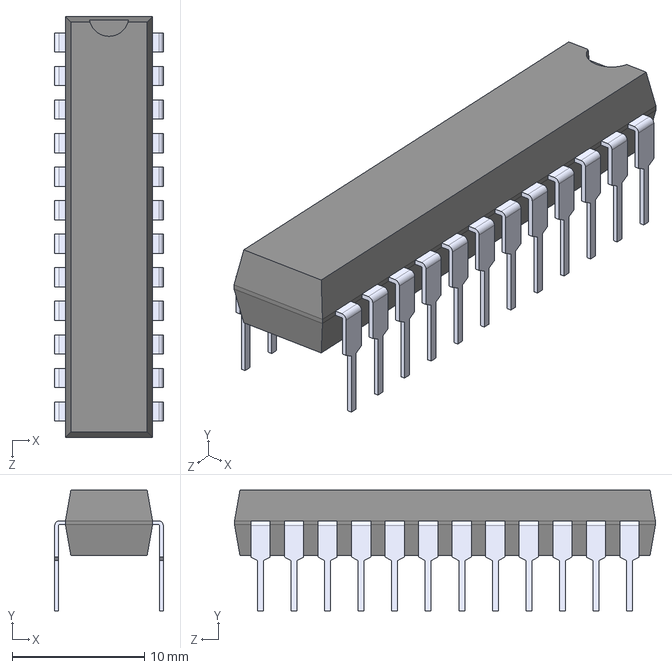
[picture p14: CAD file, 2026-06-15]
2_prototype_mk5/slot_adapters/isa/symbols/ATF22V10C-10PU.step
8.22 x 9.14 x 31.9 mm

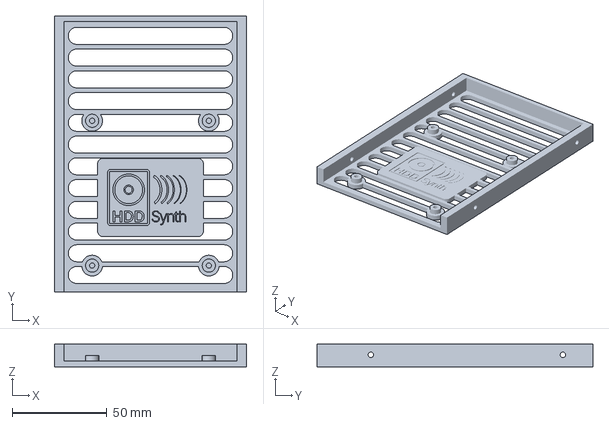
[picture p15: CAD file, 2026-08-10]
2_prototype_mk5/3d_models/drive_bay/hddsynth_35_tray.3mf
101.6 x 146.0 x 12.0 mm

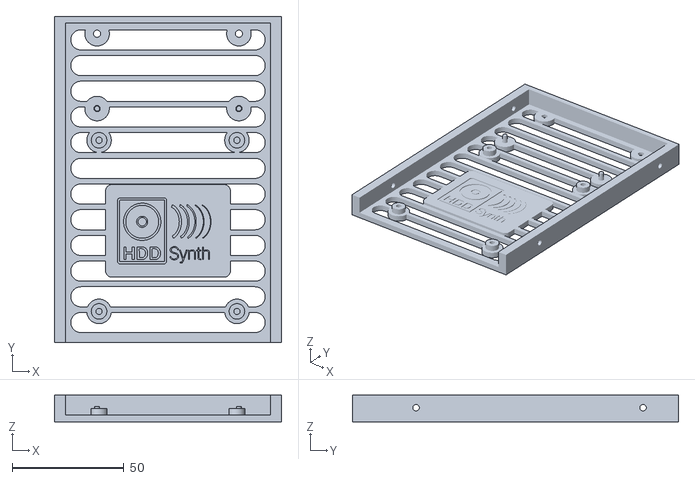
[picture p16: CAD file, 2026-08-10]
2_prototype_mk5/3d_models/drive_bay/hddsynth_35_tray_speaker.stl
101.6 x 146.0 x 12.0

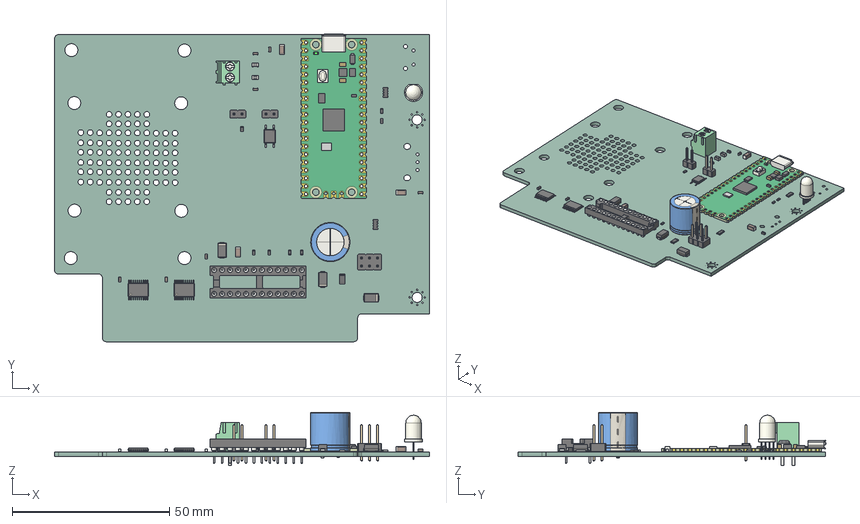
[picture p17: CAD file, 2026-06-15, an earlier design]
2_prototype_mk3/hardware/HDD Synth prototype MK3.step
119.4 x 97.9 x 17.0 mm
C_0603_1608Metric x 7
D_SMA x 3
L_0805_2012Metric x 2
C_1206_3216Metric x 3
LED_D5.0mm-4_RGB
R_0603_1608Metric x 7
TSSOP-20_4.4x6.5mm_P0.65mm x 2
DIP-24_W7.62mm_Socket
PinHeader_1x02_P2.54mm_Vertical x 2
R_1206_3216Metric
TerminalBlock_Phoenix_PT-1,5-2-3.5-H_1x02_P3.50mm_Horizontal
SO-4_4.4x3.6mm_P2.54mm
R_Array_Convex_4x0603 x 2
CP_Radial_D12.5mm_P5.00mm
PinHeader_2x03_P2.54mm_Vertical
RaspberryPi_Pico_Module_KiCad
HDD Synth prototype MK3_PCB

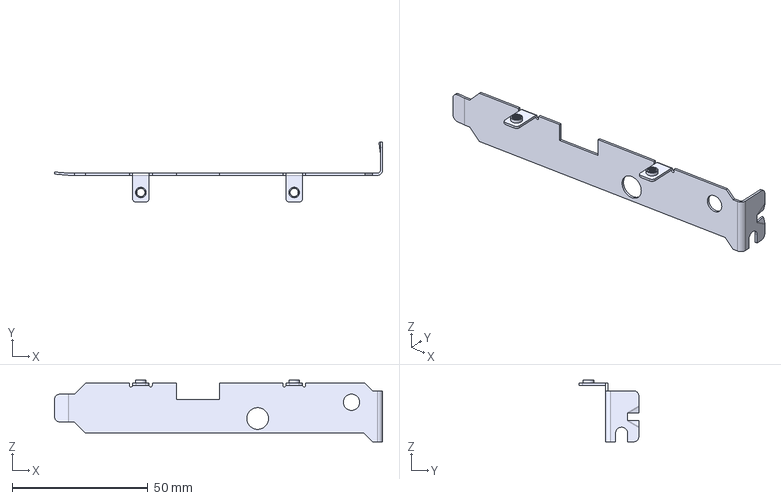
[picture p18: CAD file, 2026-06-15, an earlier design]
2_prototype_mk3/hardware/HDD Synth MKIII ISA bracket - Keystone.step
120.9 x 22.2 x 22.7 mm

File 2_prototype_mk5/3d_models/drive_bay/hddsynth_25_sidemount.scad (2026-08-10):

// ============================================================
//  HDD Synth MKV  ->  2.5" side-mount base plate
//  Bolts under the board and presents the SFF-8201 side
//  mounting holes, so the assembly mounts like a 2.5" drive.
//
//  Orientation: y=0 REAR (USB-C / connector datum),
//               z=0 is the bottom datum plane.
//  Print flat, no supports.
//
//  NOTE ON HEIGHT: SFF-8201 puts the side holes 3.00mm above
//  the bottom datum, at y = 14.00 / 90.60 - the *same* long-
//  itudinal positions as the board's own mounting holes. The
//  rail is therefore 10mm tall so the M3 pilot coming down
//  from the top stops ~1mm clear of the side hole below it.
//  Dropping rail_h below ~9 will make the two holes break
//  into each other. If you need a lower profile, set
//  modern_side_holes = false and use the legacy positions
//  only - those don't coincide with the board holes.
// ============================================================

$fn = 48;

show_pcb = false;

// ---- 2.5" form factor, SFF-8201 ---------------------------
ff_w   = 69.85;    // A4  width
ff_l   = 100.33;   // matches the HDD Synth outline (A6 max 100.45)
side_z =  3.00;    // A23 side hole height above the bottom datum

modern_side_holes = true;   // A52/A53: 14.00 / 90.60
legacy_side_holes = true;   // A30/A31: 34.93 / 73.03 (obsolete, still common)
side_y_modern = [14.00, 90.60];
side_y_legacy = [34.93, 73.03];

side_pilot = 2.80;   // M3 self-tap, no drilling
side_depth = 4.50;   // A38 requires >= 3.00mm penetration

// ---- HDD Synth MKV board ----------------------------------
pcb_w          = 69.85;
pcb_l          = 100.33;
pcb_t          =  1.60;
pcb_hole_dx    = 61.72;
pcb_hole_rear  = 13.97;
pcb_hole_pitch = 76.60;

// ---- Plate construction -----------------------------------
floor_t = 3.0;
rail_t  = 5.0;
rail_h  = 10.0;     // see note above
boss_d  = 8.0;

boss_pilot   = 2.80;
boss_depth   = 4.60;
use_inserts  = false;
insert_d     = 4.00;
insert_depth = 4.60;

// ---- Venting ----------------------------------------------
vent_w     =  9.0;
vent_x     = 20.0;
vent_pitch = 11.5;
vent_y0    =  9.0;
vent_y1    = 92.0;

// ---- Derived ----------------------------------------------
rail_x  = ff_w/2 - rail_t/2;
pcb_hx  = pcb_hole_dx/2;
pcb_hy  = [pcb_hole_rear, pcb_hole_rear + pcb_hole_pitch];
fix_d   = use_inserts ? insert_d     : boss_pilot;
fix_dep = use_inserts ? insert_depth : boss_depth;

side_y  = concat(modern_side_holes ? side_y_modern : [],
                 legacy_side_holes ? side_y_legacy : []);

// ============================================================

module tslot(y) {
    hull() for (x = [-vent_x, vent_x])
        translate([x, y, -0.5]) cylinder(d = vent_w, h = floor_t + 1);
}

module floor_plate() {
    translate([-ff_w/2, 0, 0]) cube([ff_w, ff_l, floor_t]);
}

module rails() {
    for (s = [-1, 1])
        translate([s*rail_x - rail_t/2, 0, 0]) cube([rail_t, ff_l, rail_h]);
}

module fix_bosses() {
    for (x = [-pcb_hx, pcb_hx], y = pcb_hy)
        translate([x, y, 0]) cylinder(d = boss_d, h = rail_h);
}

module side_holes() {
    for (s = [-1, 1], y = side_y)
        translate([s*(ff_w/2 + 0.1), y, side_z])
            rotate([0, -s*90, 0]) cylinder(d = side_pilot, h = side_depth);
}

module pcb_fixings() {
    for (x = [-pcb_hx, pcb_hx], y = pcb_hy)
        translate([x, y, rail_h - fix_dep]) cylinder(d = fix_d, h = fix_dep + 0.1);
}

module vent_keepouts() {
    for (x = [-pcb_hx, pcb_hx], y = pcb_hy)
        translate([x, y, -1]) cylinder(d = boss_d + 4, h = floor_t + 2);
}

module vents() {
    difference() {
        union() { for (y = [vent_y0 : vent_pitch : vent_y1]) tslot(y); }
        vent_keepouts();
    }
}

module plate() {
    difference() {
        union() { floor_plate(); rails(); fix_bosses(); }
        side_holes();
        pcb_fixings();
        vents();
    }
}

plate();
if (show_pcb)
    %translate([-pcb_w/2, 0, rail_h]) cube([pcb_w, pcb_l, pcb_t]);

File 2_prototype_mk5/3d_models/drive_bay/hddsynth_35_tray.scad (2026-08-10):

// ============================================================
//  HDD Synth MKV  ->  3.5" drive bay adapter tray   [rev B]
//  Target: SFF-8301 (3.5") / SFF-8201 (2.5" hole pattern)
//
//  Rev B changes:
//   - M3 pilots opened to 2.8mm (self-tap in plastic, no drilling)
//   - Slot venting extended across the whole base plate
//   - Recessed pocket for the HDD Synth logo label
//   - Optional Pimoroni 4ohm 3W speaker mount (COM1602)
//
//  Orientation: y=0 REAR (USB-C end, left open), y=bay_l FRONT.
//               z=0 is the bottom datum plane.
//  Print flat, no supports.
// ============================================================

use <hddsynth_logo.scad>

$fn = 48;

show_pcb = false;      // ghost the board in F5 preview

// ---- 3.5" bay envelope, SFF-8301 --------------------------
bay_w     = 101.60;    // A3
bay_l     = 146.00;    // A2 (147.00 max)
bay_h_max =  26.10;    // A1 - reference only

bot_span  =  95.25;    // A4
bot_y     = [41.28, 85.73, 117.48];   // A7, A7+A6, A7+A13
side_z    =   6.35;    // A10
side_y    = [28.50, 130.10];          // A8, A8+A9

bay_pilot =   2.90;    // 6-32 self-tap -> 3.40 for tool-less pins
bay_depth =   5.00;

// ---- HDD Synth MKV board ----------------------------------
pcb_w          =  69.85;
pcb_l          = 100.33;
pcb_t          =   1.60;
pcb_hole_dx    =  61.72;
pcb_hole_rear  =  13.97;
pcb_hole_pitch =  76.60;
pcb_y_offset   =   0.00;   // >0 pushes the board forward

// ---- Tray construction ------------------------------------
base_t  =  3.0;
rail_t  =  5.0;
rail_h  = 12.0;
front_t =  3.0;        // trimmed from 4.0 to make room for the speaker
boss_h  =  3.0;
boss_d  =  7.0;

// PCB fixings - M3
use_inserts  = false;
boss_pilot   = 2.80;   // self-tapping M3 in PETG/PLA - no drilling needed
boss_depth   = 5.00;
insert_d     = 4.00;
insert_depth = 5.50;

// ---- Venting ----------------------------------------------
vent_w     =  9.0;     // slot width
vent_x     = 39.0;     // transverse slot end-centres (+-)
vent_pitch = 11.5;     // ~2.5mm ribs between slots
vent_y0    =  9.0;
vent_y1    = 139.0;
out_seg    = [];       // outboard slots no longer needed - rows now span the full width
out_x      = 36.0;

// ---- Logo ---------------------------------------------------
// Geometry is traced from HDDSynthLogoSmall.png and lives in
// hddsynth_logo.scad - keep that file beside this one.
logo_style  = "engrave";  // "engrave" (cut logo) | "panel" (plain pocket) | "none"
logo_face   = "both";     // "bottom" | "top" | "both"
logo_w      = 50.0;       // artwork is 1.407:1
logo_h      = 35.5;       // = logo_w / 1.407
logo_depth  =  0.6;       // per face; 2x0.6 in a 3mm plate leaves a 1.8mm web
logo_x      =  0.0;
logo_y      = 50.0;
logo_margin =  3.0;       // solid border kept clear of venting

// ---- Optional speaker: Pimoroni COM1602, 41x71x23mm -------
spk_enable   = false;
spk_len      = 71.0;   // long axis, runs across the tray (x)
spk_wid      = 41.0;   // short axis, runs along the tray (y)
spk_hole_x   = 63.5;   // centres along the long axis
spk_hole_y   = 33.5;   // centres along the short axis
spk_y0       = 101.0;  // rear edge of the speaker frame
spk_screw_d  =  3.20;  // front pair: M3 clearance, countersunk underneath
spk_cs_d     =  6.20;
spk_cs_depth =  1.60;
spk_peg_d    =  2.85;  // rear pair: locating pegs
spk_peg_h    =  4.00;

// ---- Derived ----------------------------------------------
rail_x  = bay_w/2 - rail_t/2;
pcb_hx  = pcb_hole_dx/2;
pcb_hy  = [pcb_hole_rear + pcb_y_offset,
           pcb_hole_rear + pcb_hole_pitch + pcb_y_offset];
fix_d   = use_inserts ? insert_d      : boss_pilot;
fix_dep = use_inserts ? insert_depth  : boss_depth;

spk_hx      = spk_hole_x/2;
spk_y_rear  = spk_y0 + (spk_wid - spk_hole_y)/2;
spk_y_front = spk_y_rear + spk_hole_y;

// ============================================================
//  Helpers
// ============================================================

module rrect(w, h, t, r = 3) {
    hull() for (dx = [-1, 1], dy = [-1, 1])
        translate([dx*(w/2 - r), dy*(h/2 - r), 0])
            cylinder(r = r, h = t);
}

module tslot(y) {
    hull() for (x = [-vent_x, vent_x])
        translate([x, y, -0.5]) cylinder(d = vent_w, h = base_t + 1);
}

module lslot(x, y0, y1) {
    hull() for (y = [y0, y1])
        translate([x, y, -0.5]) cylinder(d = vent_w, h = base_t + 1);
}

// ============================================================
//  Solids
// ============================================================

module base_plate() {
    translate([-bay_w/2, 0, 0]) cube([bay_w, bay_l, base_t]);
}

module rails() {
    for (s = [-1, 1])
        translate([s*rail_x - rail_t/2, 0, 0]) cube([rail_t, bay_l, rail_h]);
}

module front_wall() {
    translate([-bay_w/2, bay_l - front_t, 0]) cube([bay_w, front_t, rail_h]);
}

module pcb_bosses() {
    for (x = [-pcb_hx, pcb_hx], y = pcb_hy)
        translate([x, y, 0]) cylinder(d = boss_d, h = base_t + boss_h);
}

module speaker_pegs() {
    if (spk_enable)
        for (x = [-spk_hx, spk_hx])
            translate([x, spk_y_rear, base_t])
                cylinder(d1 = spk_peg_d, d2 = spk_peg_d - 0.6, h = spk_peg_h);
}

// ============================================================
//  Cutting tools
// ============================================================

module bay_bottom_holes() {
    for (x = [-bot_span/2, bot_span/2], y = bot_y)
        translate([x, y, -0.1]) cylinder(d = bay_pilot, h = bay_depth + 0.1);
}

module bay_side_holes() {
    for (s = [-1, 1], y = side_y)
        translate([s*(bay_w/2 + 1), y, side_z])
            rotate([0, -s*90, 0]) cylinder(d = bay_pilot, h = rail_t + 2);
}

module pcb_fixings() {
    for (x = [-pcb_hx, pcb_hx], y = pcb_hy)
        translate([x, y, base_t + boss_h - fix_dep])
            cylinder(d = fix_d, h = fix_dep + 0.1);
}

module speaker_holes() {
    if (spk_enable)
        for (x = [-spk_hx, spk_hx]) {
            translate([x, spk_y_front, -0.1])
                cylinder(d = spk_screw_d, h = base_t + 0.2);
            translate([x, spk_y_front, -0.01])   // countersink on the underside
                cylinder(d1 = spk_cs_d, d2 = spk_screw_d, h = spk_cs_depth);
        }
}

// 2D logo artwork scaled to logo_w
module logo_2d() { scale(logo_w/100) hddsynth_logo(); }

module logo_cut() {
    do_bottom = (logo_face == "bottom" || logo_face == "both");
    do_top    = (logo_face == "top"    || logo_face == "both");

    if (logo_style == "engrave") {
        // Underside: mirrored in x so it reads the right way round
        // when you are looking up at the bottom of the drive.
        if (do_bottom)
            translate([logo_x, logo_y, -0.01])
                linear_extrude(logo_depth + 0.01) mirror([1, 0, 0]) logo_2d();
        if (do_top)
            translate([logo_x, logo_y, base_t - logo_depth])
                linear_extrude(logo_depth + 0.01) logo_2d();
    } else if (logo_style == "panel") {
        if (do_bottom)
            translate([logo_x, logo_y, -0.01])
                rrect(logo_w, logo_h, logo_depth + 0.01);
        if (do_top)
            translate([logo_x, logo_y, base_t - logo_depth])
                rrect(logo_w, logo_h, logo_depth + 0.01);
    }
}

// Areas the venting must not eat into
module vent_keepouts() {
    for (x = [-pcb_hx, pcb_hx], y = pcb_hy)
        translate([x, y, -1]) cylinder(d = boss_d + 4, h = base_t + 2);
    if (logo_style != "none")
        translate([logo_x, logo_y, -1])
            rrect(logo_w + 2*logo_margin, logo_h + 2*logo_margin, base_t + 2);
    if (spk_enable)
        for (x = [-spk_hx, spk_hx], y = [spk_y_rear, spk_y_front])
            translate([x, y, -1]) cylinder(d = 11, h = base_t + 2);
}

module vents() {
    difference() {
        union() {
            for (y = [vent_y0 : vent_pitch : vent_y1]) tslot(y);
            for (s = [-1, 1], seg = out_seg) lslot(s*out_x, seg[0], seg[1]);
        }
        vent_keepouts();
    }
}

// ============================================================
//  Assembly
// ============================================================

module tray() {
    difference() {
        union() {
            base_plate();
            rails();
            front_wall();
            pcb_bosses();
            speaker_pegs();
        }
        bay_bottom_holes();
        bay_side_holes();
        pcb_fixings();
        vents();
        logo_cut();
        speaker_holes();
    }
}

module ghost_pcb() {
    %translate([-pcb_w/2, pcb_y_offset, base_t + boss_h])
        cube([pcb_w, pcb_l, pcb_t]);
}

module ghost_speaker() {
    if (spk_enable)
        %translate([-spk_len/2, spk_y0, base_t]) cube([spk_len, spk_wid, 23]);
}

tray();
if (show_pcb) { ghost_pcb(); ghost_speaker(); }

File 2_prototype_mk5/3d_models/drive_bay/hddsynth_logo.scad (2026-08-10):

// ============================================================
//  HDD Synth logo - traced from HDDSynthLogoSmall.png
//  Auto-generated, do not hand-edit.
//  hddsynth_logo() returns a 2D shape 100 units wide,
//  71.072 units tall, centred on the origin.
// ============================================================

logo_aspect = 1.4070;

module hddsynth_logo() {
  union() {
    polygon([[16.397,-17.082],[14.090,-23.691],[13.716,-24.377],[13.529,-24.252],[11.284,-17.581],[10.973,-17.082],[10.100,-17.145],[13.155,-25.623],[13.030,-26.496],[12.406,-27.681],[11.970,-28.055],[10.723,-28.055],[10.536,-28.554],[10.599,-28.928],[12.157,-28.928],[12.656,-28.678],[13.529,-27.681],[17.269,-17.519],[17.332,-17.145]]);
    polygon([[18.142,-17.145],[18.142,-25.686],[19.015,-25.748],[19.140,-25.561],[19.077,-20.012],[19.264,-19.202],[19.638,-18.641],[20.449,-18.017],[21.820,-17.830],[22.506,-18.017],[23.005,-18.329],[23.566,-19.140],[23.753,-19.888],[23.691,-25.561],[23.815,-25.748],[24.626,-25.748],[24.751,-25.561],[24.688,-19.576],[24.501,-18.766],[24.002,-17.893],[23.317,-17.332],[22.756,-17.082],[21.197,-17.020],[20.200,-17.332],[19.140,-18.329],[19.015,-18.204],[19.015,-17.145]]);
    polygon([[26.870,-15.025],[26.683,-15.150],[26.683,-16.958],[26.559,-17.082],[25.561,-17.082],[25.374,-17.207],[25.374,-17.706],[25.499,-17.893],[26.496,-17.955],[26.683,-18.142],[26.683,-24.002],[26.808,-24.626],[27.244,-25.249],[27.993,-25.748],[29.302,-25.873],[29.738,-25.686],[29.613,-25.062],[29.489,-24.938],[28.990,-25.000],[28.180,-24.751],[27.681,-24.002],[27.681,-18.080],[27.805,-17.955],[29.364,-17.955],[29.489,-17.830],[29.489,-17.145],[27.805,-17.082],[27.618,-16.833],[27.681,-15.150],[27.494,-15.025]]);
    polygon([[30.860,-14.214],[30.736,-14.401],[30.736,-25.623],[30.860,-25.748],[31.733,-25.686],[31.733,-19.576],[31.983,-19.015],[32.357,-18.516],[33.042,-18.017],[34.476,-17.830],[35.162,-18.017],[35.536,-18.267],[36.284,-19.264],[36.347,-25.623],[36.471,-25.748],[37.344,-25.686],[37.344,-19.888],[37.157,-18.766],[36.908,-18.267],[36.409,-17.643],[35.536,-17.145],[33.915,-17.020],[33.354,-17.082],[32.731,-17.394],[32.170,-17.893],[32.045,-18.204],[31.796,-18.329],[31.671,-18.080],[31.733,-14.401],[31.608,-14.214]]);
    polygon([[6.671,-14.090],[4.738,-14.090],[3.865,-14.339],[2.494,-15.399],[2.120,-16.022],[1.933,-16.708],[1.933,-17.643],[2.120,-18.267],[2.868,-19.202],[4.364,-20.012],[6.546,-20.574],[7.544,-21.010],[8.354,-21.696],[8.603,-22.257],[8.603,-23.254],[8.229,-23.940],[7.544,-24.564],[6.110,-25.062],[5.175,-25.062],[4.115,-24.813],[3.117,-24.065],[2.805,-23.628],[2.618,-22.943],[1.746,-22.880],[1.621,-23.192],[2.120,-24.439],[3.242,-25.436],[4.738,-25.935],[6.359,-25.935],[7.918,-25.499],[8.915,-24.688],[9.539,-23.441],[9.601,-22.569],[9.476,-21.758],[8.853,-20.823],[7.855,-20.075],[4.052,-18.828],[3.304,-18.204],[2.930,-17.519],[2.930,-16.708],[3.304,-15.898],[3.928,-15.337],[5.050,-14.963],[6.234,-14.963],[7.294,-15.274],[8.105,-16.022],[8.541,-17.020],[9.352,-17.020],[9.289,-16.147],[8.603,-15.087],[7.980,-14.589]]);
    polygon([[30.362,23.441],[30.237,23.130],[30.299,22.880],[31.920,21.883],[33.978,19.888],[35.037,18.516],[36.035,16.833],[37.032,14.464],[37.531,12.656],[38.030,9.040],[38.030,7.357],[37.781,4.863],[37.282,2.681],[36.534,0.561],[35.536,-1.434],[34.289,-3.242],[32.855,-4.800],[31.920,-5.611],[31.110,-6.110],[31.047,-6.297],[31.421,-6.671],[33.167,-5.299],[34.165,-4.239],[35.599,-2.307],[36.721,-0.249],[37.469,1.621],[38.155,4.302],[38.466,6.858],[38.466,9.601],[38.217,11.596],[37.718,13.840],[37.219,15.025],[37.219,15.337],[36.222,17.519],[34.975,19.514],[33.728,21.010],[31.608,22.818]]);
    polygon([[24.127,23.441],[24.002,22.756],[25.374,21.883],[27.120,20.324],[28.055,19.264],[29.551,16.958],[30.299,15.337],[31.047,13.030],[31.546,10.287],[31.608,8.978],[31.546,5.985],[31.297,4.364],[30.299,0.935],[29.302,-1.122],[28.055,-2.993],[26.372,-4.800],[24.813,-5.985],[24.813,-6.297],[25.187,-6.671],[26.933,-5.299],[27.930,-4.239],[29.364,-2.307],[30.486,-0.249],[31.234,1.621],[31.983,4.613],[32.232,6.733],[32.232,9.663],[31.983,11.658],[31.484,13.840],[30.736,15.960],[29.738,17.955],[28.741,19.514],[26.933,21.571],[25.374,22.818]]);
    polygon([[17.145,23.441],[16.771,22.132],[18.267,21.135],[20.075,19.451],[21.571,17.456],[22.569,15.586],[23.566,12.656],[24.065,9.476],[24.002,6.234],[23.254,2.494],[22.569,0.748],[21.072,-1.933],[20.075,-3.180],[18.953,-4.302],[17.581,-5.362],[17.830,-6.297],[18.204,-6.671],[19.950,-5.299],[20.948,-4.239],[22.382,-2.307],[23.504,-0.249],[24.252,1.621],[25.000,4.613],[25.249,6.733],[25.249,9.663],[25.000,11.658],[24.501,13.840],[23.753,15.960],[22.756,17.955],[21.758,19.514],[19.950,21.571],[18.392,22.818]]);
    polygon([[10.910,23.441],[10.411,21.696],[11.534,21.072],[13.591,19.202],[15.087,17.207],[16.085,15.337],[17.082,12.282],[17.519,9.352],[17.519,6.920],[17.082,3.928],[16.521,2.057],[15.835,0.374],[14.589,-1.683],[12.594,-3.928],[11.222,-4.925],[11.596,-6.297],[11.970,-6.671],[13.716,-5.299],[14.713,-4.239],[16.147,-2.307],[17.269,-0.249],[18.017,1.621],[18.766,4.613],[19.015,6.733],[19.015,9.663],[18.766,11.658],[18.267,13.840],[17.519,15.960],[16.521,17.955],[15.524,19.514],[13.716,21.571],[12.157,22.818]]);
    polygon([[3.928,23.441],[3.180,21.259],[4.738,20.200],[6.172,18.890],[7.107,17.768],[8.105,16.209],[8.853,14.651],[9.601,12.344],[10.100,8.853],[10.037,6.671],[9.788,4.800],[9.289,2.805],[8.354,0.499],[7.107,-1.496],[6.110,-2.681],[3.990,-4.489],[4.613,-6.297],[4.988,-6.671],[6.733,-5.299],[7.731,-4.239],[9.165,-2.307],[10.287,-0.249],[11.035,1.621],[11.783,4.613],[12.032,6.733],[12.032,9.663],[11.783,11.658],[11.284,13.840],[10.536,15.960],[9.539,17.955],[8.541,19.514],[6.733,21.571],[5.175,22.818]]);
    union() {
      difference() {
        polygon([[-44.327,29.052],[-45.012,28.242],[-45.262,27.556],[-45.262,-27.556],[-44.763,-28.616],[-44.140,-29.177],[-43.516,-29.489],[-3.491,-29.551],[-2.930,-29.489],[-2.057,-28.990],[-1.434,-28.242],[-1.185,-27.556],[-1.185,27.556],[-1.683,28.616],[-2.494,29.302],[-3.304,29.551],[-43.267,29.551]]);
        polygon([[-43.080,27.556],[-3.491,27.618],[-3.180,27.369],[-3.117,-27.182],[-3.367,-27.494],[-42.955,-27.556],[-43.267,-27.307],[-43.329,27.244]]);
      }
      union() {
        difference() {
          polygon([[-16.022,-14.214],[-16.147,-14.339],[-16.147,-25.686],[-11.409,-25.748],[-10.162,-25.499],[-8.728,-24.751],[-7.731,-23.753],[-7.170,-22.818],[-6.671,-20.698],[-6.671,-19.202],[-6.920,-17.830],[-7.731,-16.209],[-8.541,-15.337],[-9.165,-14.900],[-10.599,-14.339],[-11.471,-14.214]]);
          polygon([[-13.965,-15.960],[-11.908,-15.960],[-10.474,-16.272],[-9.414,-17.207],[-8.853,-18.329],[-8.666,-19.576],[-8.853,-21.571],[-9.414,-22.756],[-10.287,-23.566],[-11.845,-24.002],[-13.903,-24.065],[-14.152,-23.878],[-14.152,-16.147]]);
        }
      }
      union() {
        difference() {
          polygon([[-27.618,-14.214],[-27.743,-14.339],[-27.743,-25.686],[-23.005,-25.748],[-21.820,-25.499],[-20.574,-24.938],[-19.389,-23.878],[-18.641,-22.569],[-18.392,-21.758],[-18.204,-20.200],[-18.267,-19.077],[-18.454,-17.955],[-19.140,-16.397],[-19.825,-15.586],[-20.449,-15.087],[-21.883,-14.401],[-23.067,-14.214]]);
          polygon([[-25.499,-15.960],[-23.504,-15.960],[-22.070,-16.272],[-21.072,-17.082],[-20.574,-17.893],[-20.324,-18.766],[-20.262,-19.701],[-20.324,-21.135],[-20.574,-22.070],[-21.259,-23.067],[-22.444,-23.815],[-23.317,-24.002],[-25.561,-24.002],[-25.686,-23.878],[-25.748,-16.272]]);
        }
      }
      polygon([[-39.464,-14.214],[-39.589,-14.339],[-39.589,-25.686],[-37.594,-25.686],[-37.594,-20.948],[-37.282,-20.761],[-32.294,-20.823],[-32.107,-21.010],[-32.170,-25.561],[-32.045,-25.748],[-30.175,-25.748],[-30.175,-14.214],[-31.983,-14.214],[-32.107,-14.339],[-32.107,-18.890],[-32.294,-19.077],[-37.469,-19.077],[-37.594,-18.953],[-37.656,-14.214]]);
      union() {
        difference() {
          polygon([[-24.314,24.813],[-27.556,24.252],[-30.673,23.067],[-33.354,21.322],[-35.786,19.015],[-36.721,17.830],[-37.781,16.147],[-39.027,13.217],[-39.464,11.596],[-39.713,9.913],[-39.776,6.920],[-39.214,3.678],[-38.030,0.561],[-36.284,-2.120],[-33.978,-4.551],[-32.793,-5.486],[-31.110,-6.546],[-28.180,-7.793],[-26.559,-8.229],[-24.875,-8.479],[-21.883,-8.541],[-18.641,-7.980],[-15.524,-6.796],[-12.843,-5.050],[-10.411,-2.743],[-9.476,-1.559],[-8.416,0.125],[-7.170,3.055],[-6.733,4.676],[-6.484,6.359],[-6.421,9.352],[-6.983,12.594],[-8.167,15.711],[-9.913,18.392],[-12.219,20.823],[-13.404,21.758],[-15.087,22.818],[-18.017,24.065],[-19.638,24.501],[-21.322,24.751]]);
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

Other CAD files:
2_prototype_mk5/3d_models/drive_bay/hddsynth_35_tray.stl

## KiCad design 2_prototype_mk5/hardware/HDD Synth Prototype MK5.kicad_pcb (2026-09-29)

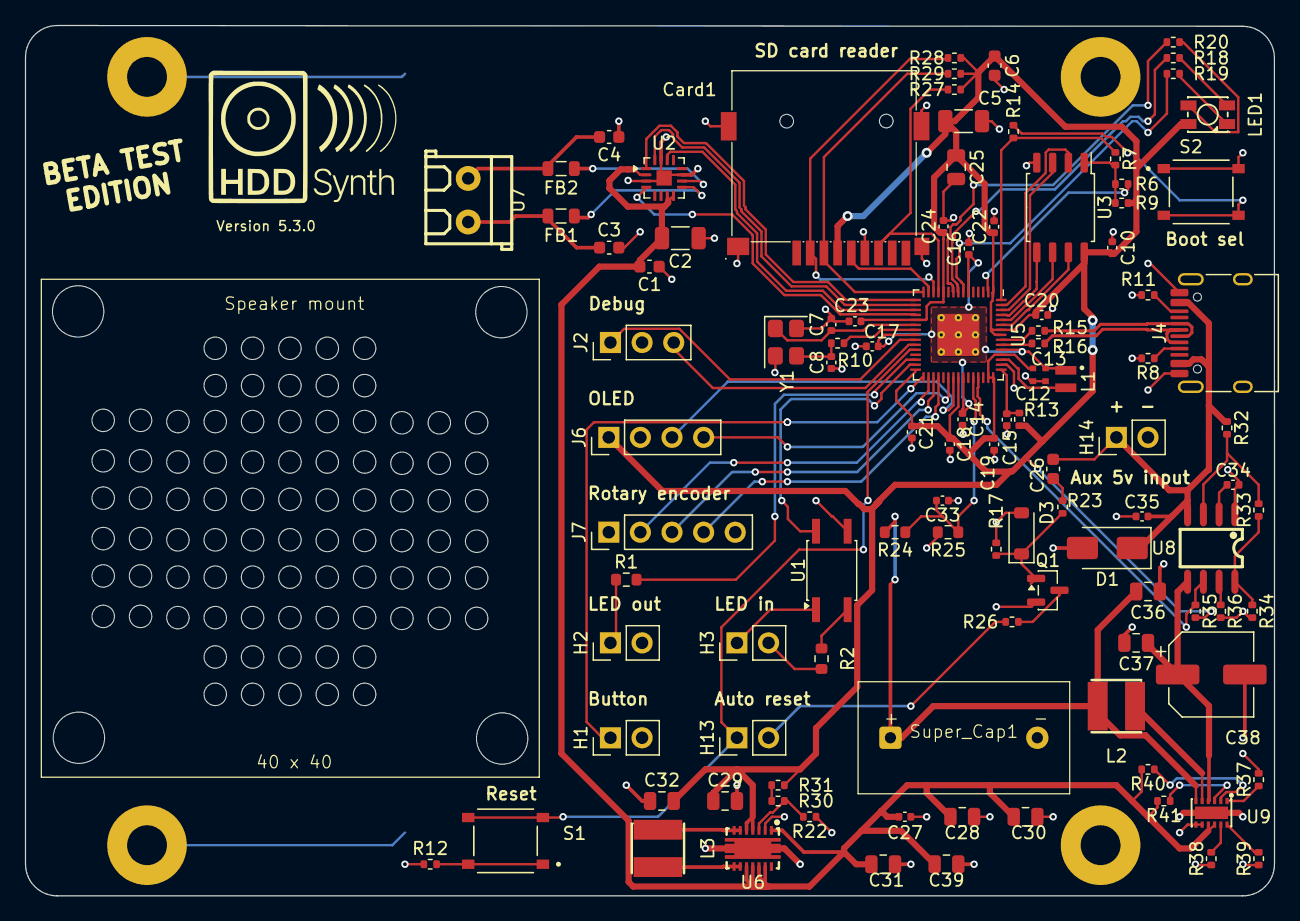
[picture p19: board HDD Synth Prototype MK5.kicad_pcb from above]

Board: 2 copper layers, 100.3 x 69.9 mm, 110 parts (1 on the bottom side), 81 nets.

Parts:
 : LOGO; MHDDLA_Sound_40mm
C1, C6, C26: 0.1uF; C_0603_1608Metric
C2, C5: 10uF; C_1206_3216Metric
C3, C4: 1nF; C_0603_1608Metric
C7, C8: 15p; C_0402_1005Metric
C10, C14, C17, C18, C19, C20, C21, C22, C23, C24, C27, C33: 100nF; C_0402_1005Metric
C12, C13: 4.7uF; C_0402_1005Metric_small_pads
C15, C16: 4.7uF; C_0402_1005Metric
C25, C28, C30, C36, C37: 10uF; C_0805_2012Metric
C29, C31, C32, C39: 22uF; C_0805_2012Metric
C34: 4.7nF; C_0402_1005Metric
C35: 1uF; C_0402_1005Metric
C38: 100uF; CP_Elec_6.3x7.7
Card1: TF-015; TF-SMD_TF-015
D1: SMAJ5.0A; D_SMA
D3: 1N4148W; D_SOD-123
FB1, FB2: FerriteBead_Small; L_0805_2012Metric
H1, H2, H3, H13, H14: Conn_01x02; PinHeader_1x02_P2.54mm_Vertical
H8, H9, H10, H11: MountingHole_Pad; MountingHole_3.2mm_M3_Pad
J2: Conn_01x03; PinHeader_1x03_P2.54mm_Vertical
J4: USB_C_Receptacle_USB2.0_16P; USB_C_Receptacle_HRO_TYPE-C-31-M-12
J6: Conn_01x04_Pin; PinHeader_1x04_P2.54mm_Vertical
J7: Conn_01x05; PinHeader_1x05_P2.54mm_Vertical
L1: 3.3u; L_pol_2016
L2: 2.2 µH; IND-SMD_L4.0-W4.0_FNR40XXS
L3: FNR4018S1R5MT; IND-SMD_L4.0-W4.0_FNR40XXS
LED1: XL-3528RGBW-HM; LED-SMD_4P-L3.2-W2.8-LS3.5-XL-3528RGBW-HM5
Q1: 2N7002; SOT-23
R1, R2: 330R; R_0603_1608Metric
R6, R9: DNF; R_0402_1005Metric
R7: 0; R_0402_1005Metric
R8, R11: 5.1K; R_0402_1005Metric
R10, R12, R14, R26: 1K; R_0402_1005Metric
R13, R18, R20: 33R; R_0402_1005Metric
R15, R16: 27R; R_0402_1005Metric
R17, R30, R40, R41: 100K; R_0402_1005Metric
R19: 200R; R_0402_1005Metric
R22: 22K; R_0402_1005Metric
R23, R35: 10K; R_0402_1005Metric
R24, R25: 22K; R_0603_1608Metric
R27, R28, R29, R33: 47K; R_0402_1005Metric
R31: 24K; R_0402_1005Metric
R32: 330K; R_0402_1005Metric
R34: 120K; R_0402_1005Metric
R36: 110K; R_0402_1005Metric
R37, R38, R39: 75K; R_0402_1005Metric
S1, S2: TS-1187A-B-A-B; SW_TS-1187A-B-A-B
Super_Cap1: 1.5F; SuperCap_Eaton_PHV_9.0x17.3mm_P11.80mm
U1: Optocoupler_DC_PhotoNPN_AKEC; SO-4_4.4x3.6mm_P2.54mm
U2: MAX98357A; TQFN-16-1EP_3x3mm_P0.5mm_EP1.23x1.23mm
U3: W25Q32JVSSIQ; SOIC-8_5.23x5.23mm_P1.27mm
U5: RP2350_60QFN; RP2350-QFN-60-1EP_7x7_P0.4mm_EP3.4x3.4mm_ThermalVias
U6: TPS63020DSJR; VSON-14_L4.0-W3.0-P0.50-BL-EP_TI_DSJ
U7: KF350-3.5-2P; CONN-TH_P3.50_KF350-3.5-2P
U8: TPS25921ADR; SOIC-8_L5.0-W4.0-P1.27-LS6.0-BL
U9: TPS61094DSSR; WSON-12_L3.0-W2.0-P0.5-BL-EP
Y1: ABM8-272-T3; Crystal_SMD_3225-4Pin_3.2x2.5mm

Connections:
+1V1: C13.1, C14.1, C16.1, C17.1, L1.1, U5.6 (DVDD), U5.23 (DVDD), U5.39 (DVDD), U5.50 (VREG_FB)
+3V3: C5.1, C6.1, C10.1, C12.1, C18.1, C19.1, C20.1, C21.1, C22.1, C23.1, C24.1, C25.1, C29.1, C32.2, Card1.4 (VDD), J6.1, LED1.2 (+), R9.1, R13.1, R27.1, R28.1, R29.1, R31.1, R35.2, U3.8 (VCC), U5.1 (IOVDD), U5.11 (IOVDD), U5.20 (IOVDD), U5.30 (IOVDD), U5.38 (IOVDD), U5.44 (ADC_AVDD), U5.45 (IOVDD), U5.49 (VREG_VIN), U5.53 (USB_OTP_VDD), U5.54 (QSPI_IOVDD), U6.4 (VOUT), U6.5 (VOUT)
+5V: C26.2, C35.2, D1.1 (K), H14.1, J4.A4 (VBUS), J4.A9 (VBUS), J4.B4 (VBUS), J4.B9 (VBUS), R32.1, U8.4 (IN)
/ACTION_BTN: H1.1, U5.31 (GPIO19)
/HDD_LED_IN: U1.4, U5.29 (GPIO18)
/HDD_LED_OUT: R1.2, U5.28 (GPIO17)
/Power/VIN_PROT: C37.1, C38.1, U8.5 (OUT), U9.4 (VIN)
/Power/VSUP_SENSE: C33.2, R24.1, R25.1, U5.41 (GPIO27_ADC1)
/RP2350/AMP_BCLK: U2.16 (BCLK), U5.17 (GPIO13)
/RP2350/AMP_DIN: U2.1 (DIN), U5.16 (GPIO12)
/RP2350/AMP_LRCL: U2.14 (LRCLK), U5.18 (GPIO14)
/RP2350/AMP_SDMODE: U2.4 (~SD_MODE), U5.19 (GPIO15)
/RP2350/ENC_A: J7.2, U5.32 (GPIO20)
/RP2350/ENC_B: J7.3, U5.33 (GPIO21)
/RP2350/ENC_BTN: J7.4, U5.34 (GPIO22)
/RP2350/FLASH_SS: R6.2, R7.2, R9.2, U3.1 (~CS)
/RP2350/GPIO0: R6.1, U5.2 (GPIO0)
/RP2350/OLED_SCL: J6.3, U5.37 (GPIO25)
/RP2350/OLED_SDA: J6.4, U5.36 (GPIO24)
/RP2350/PWR_FAULT_N: R35.1, U5.42 (GPIO28_ADC2), U8.6 (#FLT)
/RP2350/QSPI_SCLK: U3.6 (CLK), U5.56 (QSPI_SCLK)
/RP2350/QSPI_SD0: U3.5 (DI(IO0)), U5.57 (QSPI_SD0)
/RP2350/QSPI_SD1: U3.2 (DO(IO1)), U5.59 (QSPI_SD1)
/RP2350/QSPI_SD2: U3.3 (IO2), U5.58 (QSPI_SD2)
/RP2350/QSPI_SD3: U3.7 (IO3), U5.55 (QSPI_SD3)
/RP2350/QSPI_SS: R7.1, R14.1, U5.60 (QSPI_SS)
/RP2350/RBG_LED_BLUE: R20.1, U5.9 (GPIO6)
/RP2350/RGB_LED_GREEN: R18.1, U5.8 (GPIO5)
/RP2350/RGB_LED_RED: R19.1, U5.7 (GPIO4)
/RP2350/RUN: H13.1, S1.C, S1.D, U5.26 (RUN)
/RP2350/SD_CS: Card1.2 (CDDAT3(CS)), R28.2, U5.13 (GPIO9)
/RP2350/SD_MISO: Card1.7 (DAT0(D0)), R27.2, U5.12 (GPIO8)
/RP2350/SD_MOSI: Card1.3 (CMD(DI)), R29.2, U5.15 (GPIO11)
/RP2350/SD_SCK: Card1.5 (CLK(SCLK)), U5.14 (GPIO10)
/RP2350/SWCLK: J2.1, U5.24 (SWCLK)
/RP2350/SWD: J2.3, U5.25 (SWD)
/RP2350/USB_D+: J4.A6 (D+), J4.B6 (D+), R15.1
/RP2350/USB_D-: J4.A7 (D-), J4.B7 (D-), R16.1
/RP2350/VREG_AVDD: C15.1, R13.2, U5.46 (VREG_AVDD)
/RP2350/VREG_LX: L1.2, U5.48 (VREG_LX)
/RP2350/XIN: C7.1, U5.21 (XIN), Y1.1
/RP2350/XOUT: R10.1, U5.22 (XOUT)
/RP2350/~USB_BOOT: R14.2, S2.C, S2.D
GND: C1.1, C2.1, C3.2, C4.1, C5.2, C6.2, C7.2, C8.2, C10.2, C12.2, C13.2, C14.2, C15.2, C16.2, C17.2, C18.2, C19.2, C20.2, C21.2, C22.2, C23.2, C24.2, C25.2, C27.2, C28.2, C29.2, C30.2, C31.2, C32.1, C33.1, C34.2, C35.1, C36.1, C37.2, C38.2, C39.2, Card1.6 (VSS), Card1.10 (GND), Card1.11 (GND), Card1.12 (GND), Card1.13 (GND), D1.2 (A), D3.2 (A), H1.2, H2.2, H8.1 (1_1), H9.1 (1_1), H10.1 (1_1), H11.1 (1_1), H14.2, J2.2, J4.A1 (GND), J4.A12 (GND), J4.B1 (GND), J4.B12 (GND), J4.SH (SHIELD), J6.2, J7.1, J7.5, Q1.2 (S), R8.2, R11.2, R12.2, R17.2, R22.1, R25.2, R34.2, R36.2, R37.2, R38.1, R39.1, S2.A, S2.B, Super_Cap1.2, U1.3, U2.3 (GND), U2.11 (GND), U2.15 (GND), U2.17 (PAD), U3.4 (GND), U5.47 (VREG_PGND), U5.61 (GND), U6.2 (GND), U6.15 (PGND), U8.1 (GND), U9.7 (PGND), U9.8 (AGND), U9.13 (EP), Y1.2, Y1.4
unnamed: C3.1, FB1.2, U7.2
unnamed: C4.2, FB2.2, U7.1
unnamed: C8.1, R10.2, Y1.3
unnamed: C26.1, R23.1
unnamed: D3.1 (K), Q1.1 (G), R17.1, R23.2
unnamed: H2.1, R1.1
unnamed: H3.1, U1.1
unnamed: H3.2, R2.2
unnamed: H13.2, R26.2
unnamed: J4.A5 (CC1), R8.1
unnamed: J4.B5 (CC2), R11.1
unnamed: L3.1, U6.6 (L2), U6.7 (L2)
unnamed: L3.2, U6.8 (L1), U6.9 (L1)
unnamed: LED1.4 (B-), R20.2
unnamed: LED1.3 (G-), R18.2
unnamed: LED1.1 (R-), R19.2
unnamed: Q1.3 (D), R26.1
unnamed: R2.1, U1.2
unnamed: R12.1, S1.A, S1.B
unnamed: R30.1, R31.2
unnamed: FB2.1, U2.10 (OUTN)
unnamed: FB1.1, U2.9 (OUTP)
unnamed: R16.2, U5.51 (USB_DM)
unnamed: R15.2, U5.52 (USB_DP)
unnamed: R22.2, R30.2, U6.3 (FB)
unnamed: R32.2, R33.2, U8.3 (ENUV)
unnamed: R36.1, U8.7 (ILIM)
unnamed: R33.1, R34.1, U8.8 (OVP)
unnamed: C34.1, U8.2 (SS)
unnamed: R41.1, U9.3 (EN)
unnamed: R38.2, U9.11 (ICHG)
unnamed: R40.1, U9.2 (MODE)
unnamed: R37.1, U9.1 (OSEL)
unnamed: C36.2, L2.2, R24.2, Super_Cap1.1, U9.6 (SUP)
unnamed: L2.1, U9.5 (SW)
unnamed: R39.2, U9.12 (VCHG)
VSYS: C1.2, C2.2, C27.1, C28.1, C30.1, C31.1, C39.1, R40.2, R41.2, U2.2 (GAIN_SLOT), U2.7 (VDD), U2.8 (VDD), U6.1 (VINA), U6.10 (VIN), U6.11 (VIN), U6.12 (EN), U6.13 (PS/SYNC), U9.9 (VOUT), U9.10 (VOUT)

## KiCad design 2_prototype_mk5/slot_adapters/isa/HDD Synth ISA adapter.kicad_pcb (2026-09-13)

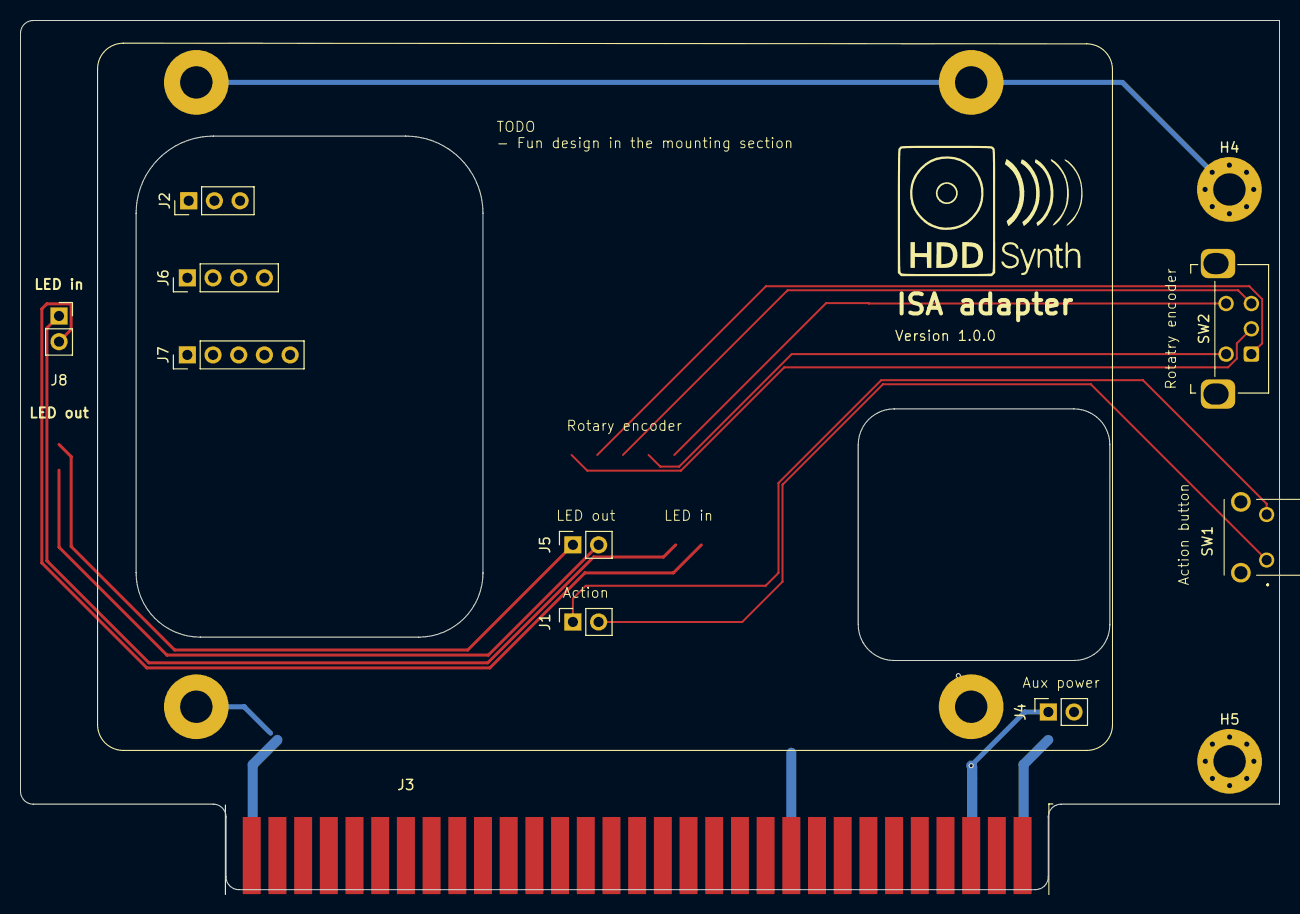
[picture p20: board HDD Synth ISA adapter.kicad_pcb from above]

Board: 2 copper layers, 124.5 x 85.9 mm, 16 parts (0 on the bottom side), 4 nets.

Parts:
H4, H5: MountingHole_Pad; MountingHole_3.2mm_M3_Pad_Via
H8, H9, H10, H11: MountingHole_Pad; MountingHole_3.2mm_M3_Pad
J1, J4, J5, J8: Conn_01x02_Socket; PinSocket_1x02_P2.54mm_Vertical
J2: Conn_01x03; PinSocket_1x03_P2.54mm_Vertical
J3: Bus_ISA_8bit; BUS_AT_8bit
J6: Conn_01x04_Pin; PinSocket_1x04_P2.54mm_Vertical
J7: Conn_01x05; PinSocket_1x05_P2.54mm_Vertical
SW1: SW_Push; PTS645VL582LFS
SW2: PEC12R-2120F-S0012; RotaryEncoder_Bourns_Horizontal_PEC12R-2x17F-Sxxxx

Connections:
GND: H4.1 (1_1), H5.1 (1_1), H8.1 (1_1), H9.1 (1_1), H10.1 (1_1), H11.1 (1_1), J2.2, J3.1 (GND), J4.2, J6.2, J7.1, J7.5
unnamed: J1.1, SW1.2
unnamed: J1.2, SW1.1
unnamed: J3.3 (VCC), J4.1

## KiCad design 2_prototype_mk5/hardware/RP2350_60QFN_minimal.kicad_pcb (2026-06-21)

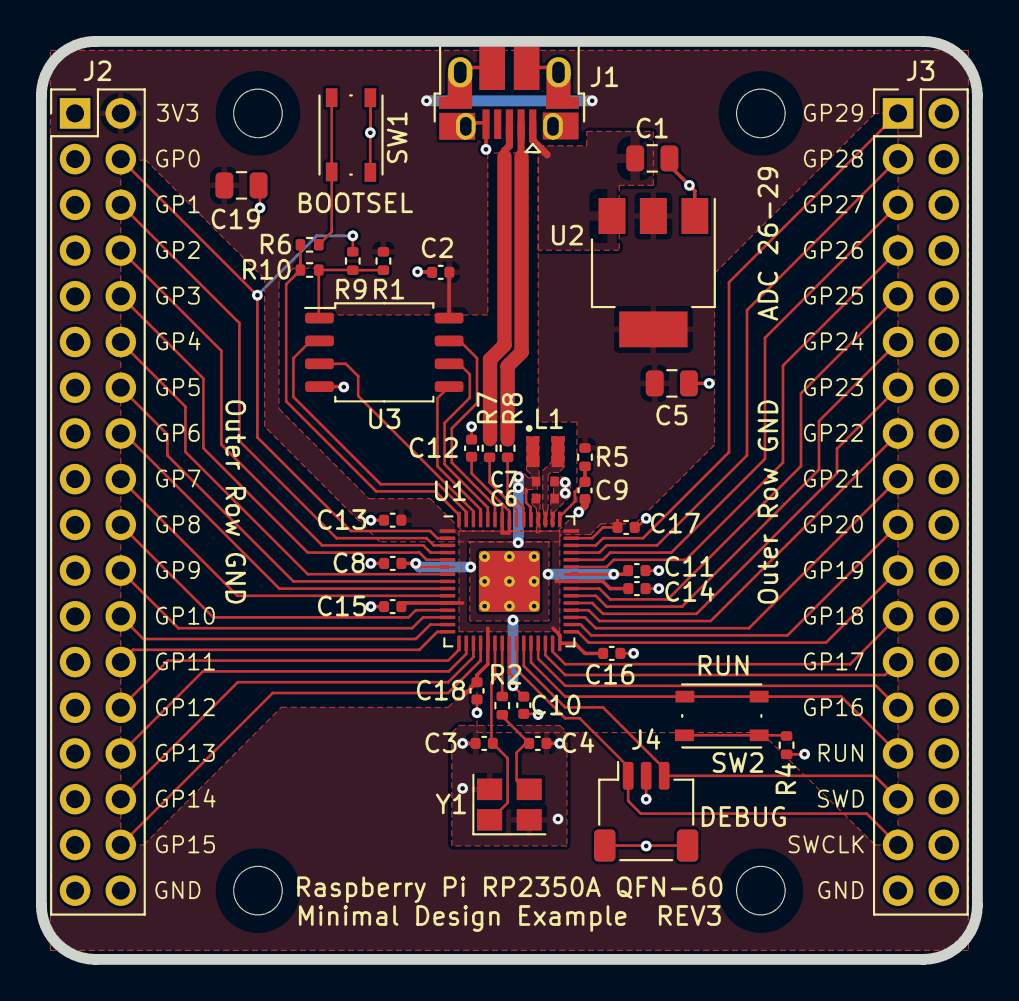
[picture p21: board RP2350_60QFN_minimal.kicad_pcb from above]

Board: 2 copper layers, 52.0 x 51.0 mm, 43 parts (0 on the bottom side), 55 nets.

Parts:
C1, C5, C19: 10u; C_0805_2012Metric
C2, C8, C11, C12, C13, C14, C15, C16, C17, C18: 100n; C_0402_1005Metric
C3, C4: 15p; C_0402_1005Metric
C6, C7: 4.7u; C_0402_1005Metric_small_pads
C9, C10: 4.7u; C_0402_1005Metric
H1, H2, H3, H4: MountingHole; MountingHole_2.7mm_M2.5
J1: USB_B_Micro; USB_Micro-B_Amphenol_10103594-0001LF_Horizontal
J2, J3: Conn_02x18_Odd_Even; PinHeader_2x18_P2.54mm_Vertical
J4: SM03B-SRSS-TB; JST_SH_SM03B-SRSS-TB_1x03-1MP_P1.00mm_Horizontal
L1: 3.3u; L_pol_2016
R1, R9: DNF; R_0402_1005Metric
R2, R4, R6: 1k; R_0402_1005Metric
R5: 33; R_0402_1005Metric
R7, R8: 27; R_0402_1005Metric
R10: 0; R_0402_1005Metric
SW1, SW2: SW_Push; SW_Push_1P1T_NO_Vertical_Wuerth_434133025816
U1: RP2350_60QFN; RP2350-QFN-60-1EP_7x7_P0.4mm_EP3.4x3.4mm_ThermalVias
U2: NCP1117-3.3_SOT223; SOT-223-3_TabPin2
U3: W25Q128JVS; SOIC-8_5.23x5.23mm_P1.27mm
Y1: ABM8-272-T3; Crystal_SMD_3225-4Pin_3.2x2.5mm

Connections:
+1V1: C7.1, C8.1, C10.1, C11.1, L1.1, U1.6 (DVDD), U1.23 (DVDD), U1.39 (DVDD), U1.50 (VREG_FB)
+3V3: C2.1, C5.1, C6.1, C12.1, C13.1, C14.1, C15.1, C16.1, C17.1, C18.1, C19.1, J2.2, R1.1, R5.1, U1.1 (IOVDD), U1.11 (IOVDD), U1.20 (IOVDD), U1.30 (IOVDD), U1.38 (IOVDD), U1.44 (ADC_AVDD), U1.45 (IOVDD), U1.49 (VREG_VIN), U1.53 (USB_OTP_VDD), U1.54 (QSPI_IOVDD), U2.2 (VO), U3.8 (VCC)
/FLASH_SS: R1.2, R9.2, R10.2, U3.1 (~CS)
/GPIO0: J2.4, R9.1, U1.2 (GPIO0)
/GPIO1: J2.6, U1.3 (GPIO1)
/GPIO2: J2.8, U1.4 (GPIO2)
/GPIO3: J2.10, U1.5 (GPIO3)
/GPIO4: J2.12, U1.7 (GPIO4)
/GPIO5: J2.14, U1.8 (GPIO5)
/GPIO6: J2.16, U1.9 (GPIO6)
/GPIO7: J2.18, U1.10 (GPIO7)
/GPIO8: J2.20, U1.12 (GPIO8)
/GPIO9: J2.22, U1.13 (GPIO9)
/GPIO10: J2.24, U1.14 (GPIO10)
/GPIO11: J2.26, U1.15 (GPIO11)
/GPIO12: J2.28, U1.16 (GPIO12)
/GPIO13: J2.30, U1.17 (GPIO13)
/GPIO14: J2.32, U1.18 (GPIO14)
/GPIO15: J2.34, U1.19 (GPIO15)
/GPIO16: J3.27, U1.27 (GPIO16)
/GPIO17: J3.25, U1.28 (GPIO17)
/GPIO18: J3.23, U1.29 (GPIO18)
/GPIO19: J3.21, U1.31 (GPIO19)
/GPIO20: J3.19, U1.32 (GPIO20)
/GPIO21: J3.17, U1.33 (GPIO21)
/GPIO22: J3.15, U1.34 (GPIO22)
/GPIO23: J3.13, U1.35 (GPIO23)
/GPIO24: J3.11, U1.36 (GPIO24)
/GPIO25: J3.9, U1.37 (GPIO25)
/GPIO26_ADC0: J3.7, U1.40 (GPIO26_ADC0)
/GPIO27_ADC1: J3.5, U1.41 (GPIO27_ADC1)
/GPIO28_ADC2: J3.3, U1.42 (GPIO28_ADC2)
/GPIO29_ADC3: J3.1, U1.43 (GPIO29_ADC3)
/QSPI_SCLK: U1.56 (QSPI_SCLK), U3.6 (CLK)
/QSPI_SD0: U1.57 (QSPI_SD0), U3.5 (DI(IO0))
/QSPI_SD1: U1.59 (QSPI_SD1), U3.2 (DO(IO1))
/QSPI_SD2: U1.58 (QSPI_SD2), U3.3 (IO2)
/QSPI_SD3: U1.55 (QSPI_SD3), U3.7 (IO3)
/QSPI_SS: R6.1, R10.1, U1.60 (QSPI_SS)
/RUN: J3.29, SW2.2, U1.26 (RUN)
/SWCLK: J3.33, J4.1, U1.24 (SWCLK)
/SWD: J3.31, J4.3, U1.25 (SWD)
/USB_D+: J1.3 (D+), R7.1
/USB_D-: J1.2 (D-), R8.1
/VREG_AVDD: C9.1, R5.2, U1.46 (VREG_AVDD)
/VREG_LX: L1.2, U1.48 (VREG_LX)
/XIN: C3.1, U1.21 (XIN), Y1.1
/XOUT: R2.1, U1.22 (XOUT)
/~USB_BOOT: R6.2, SW1.2
GND: C1.2, C2.2, C3.2, C4.2, C5.2, C6.2, C7.2, C8.2, C9.2, C10.2, C11.2, C12.2, C13.2, C14.2, C15.2, C16.2, C17.2, C18.2, C19.2, J1.5 (GND), J1.6 (Shield), J2.1, J2.3, J2.5, J2.7, J2.9, J2.11, J2.13, J2.15, J2.17, J2.19, J2.21, J2.23, J2.25, J2.27, J2.29, J2.31, J2.33, J2.35, J2.36, J3.2, J3.4, J3.6, J3.8, J3.10, J3.12, J3.14, J3.16, J3.18, J3.20, J3.22, J3.24, J3.26, J3.28, J3.30, J3.32, J3.34, J3.35, J3.36, J4.2, J4.MP (MountPin), R4.2, SW1.1, U1.47 (VREG_PGND), U1.61 (GND), U2.1 (GND), U3.4 (GND), Y1.2, Y1.4
unnamed: C4.1, R2.2, Y1.3
unnamed: R4.1, SW2.1
unnamed: R8.2, U1.51 (USB_DM)
unnamed: R7.2, U1.52 (USB_DP)
VBUS: C1.1, J1.1 (VBUS), U2.3 (VI)

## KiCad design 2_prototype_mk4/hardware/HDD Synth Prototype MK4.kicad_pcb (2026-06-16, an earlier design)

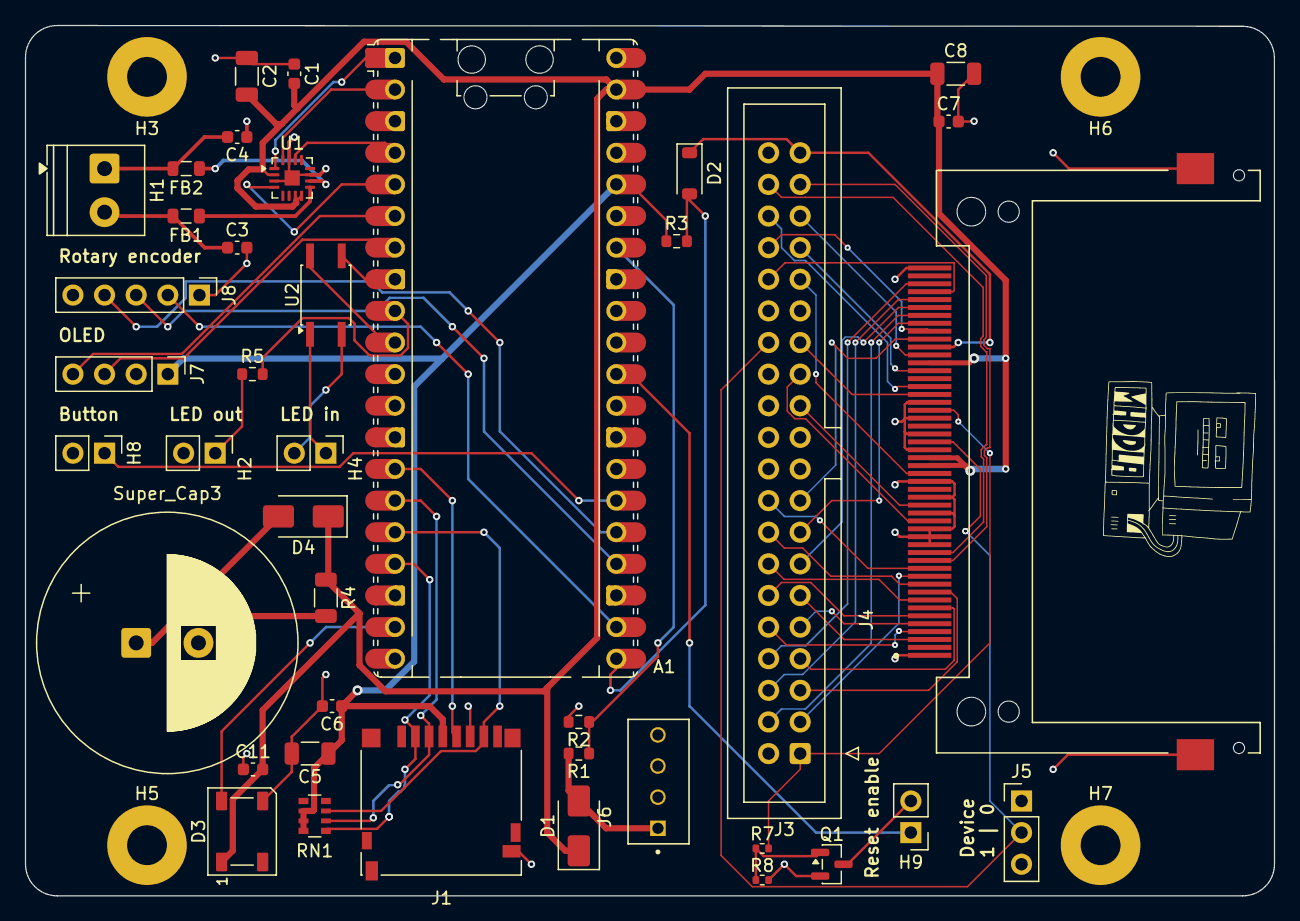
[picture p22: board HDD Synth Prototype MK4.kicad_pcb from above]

Board: 2 copper layers, 100.3 x 69.9 mm, 44 parts (0 on the bottom side), 64 nets.

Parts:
A1: RaspberryPi_Pico2; RaspberryPi_Pico_Common_Unspecified
C1, C6, C7, C11: 0.1uF; C_0603_1608Metric
C2, C5, C8: 10uF; C_1206_3216Metric
C3, C4: 1nF; C_0603_1608Metric
D1: SS14; D_SMA
D2: BAT43W; D_SOD-123
D3: WS2812B; LED_WS2812B_PLCC4_5.0x5.0mm_P3.2mm
D4: SS12; D_SMA
FB1, FB2: FerriteBead_Small; L_0805_2012Metric
H1: Conn_01x02; TerminalBlock_Phoenix_PT-1,5-2-3.5-H_1x02_P3.50mm_Horizontal
H2, H4, H8, H9: Conn_01x02; PinHeader_1x02_P2.54mm_Vertical
H3, H5, H6, H7: MountingHole_Pad; MountingHole_3.2mm_M3_Pad
J1: Micro_SD_Card; microSD_HC_Hirose_DM3D-SF
J3: Conn_02x20_Odd_Even; IDC-Header_2x20_P2.54mm_Vertical
J4: 1734451-1; TE_1734451-1
J5: Conn_01x03_Pin; PinHeader_1x03_P2.54mm_Vertical
J6: 171825-4; TE_171825-4
J7: Conn_01x04_Pin; PinHeader_1x04_P2.54mm_Vertical
J8: Conn_01x05; PinHeader_1x05_P2.54mm_Vertical
Q1: MMBT3904; SOT-23
R1: 1K; R_0603_1608Metric
R2: 2K; R_0603_1608Metric
R3: 4.7K; R_0603_1608Metric
R4: 33R; R_1206_3216Metric
R5: 330R; R_0603_1608Metric
R7: 4.7K; R_0402_1005Metric
R8: 10K; R_0402_1005Metric
RN1: 47K; R_Array_Convex_4x0603
Super_Cap3: 1F; CP_Radial_D14.0mm_P5.00mm
U1: MAX98357A; TQFN-16-1EP_3x3mm_P0.5mm_EP1.23x1.23mm
U2: Optocoupler_DC_PhotoNPN_AKEC; SO-4_4.4x3.6mm_P2.54mm

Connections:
+3.3V: A1.36 (3V3), C5.1, C6.1, J1.4 (VDD), J7.1, R3.1, RN1.6 (R3.2), RN1.7 (R2.2), RN1.8 (R1.2)
+5V: D1.2 (A), J6.1, R1.2
/ACTION_BTN: A1.26 (GPIO20), H8.1
/Amplifer/BCLK: A1.2 (GPIO1), U1.16 (BCLK)
/Amplifer/DIN: A1.1 (GPIO0), U1.1 (DIN)
/Amplifer/LRCLK: A1.4 (GPIO2), U1.14 (LRCLK)
/Amplifer/SD_MODE: A1.5 (GPIO3), U1.4 (~SD_MODE)
/HDD_LED_IN: A1.10 (GPIO7), U2.4
/HDD_LED_OUT: A1.9 (GPIO6), R5.2
/IDE/CF_CABLE_SELECT: J3.28, J4.39, J5.2
/IDE/D00: J3.17, J4.21
/IDE/D01: J3.15, J4.22
/IDE/D02: J3.13, J4.23
/IDE/D03: J3.11, J4.2
/IDE/D04: J3.9, J4.3
/IDE/D05: J3.7, J4.4
/IDE/D06: J3.5, J4.5
/IDE/D07: J3.3, J4.6
/IDE/D08: J3.4, J4.47
/IDE/D09: J3.6, J4.48
/IDE/D10: J3.8, J4.49
/IDE/D11: J3.10, J4.27
/IDE/D12: J3.12, J4.28
/IDE/D13: J3.14, J4.29
/IDE/D14: J3.16, J4.30
/IDE/D15: J3.18, J4.31
/IDE/IDE_ACTIVITY: A1.21 (GPIO16), D2.2 (A), R3.2
/IDE/IDE_ADDRESS_0: J3.35, J4.20
/IDE/IDE_ADDRESS_1: J3.33, J4.19
/IDE/IDE_ADDRESS_2: J3.36, J4.18
/IDE/IDE_CHIPSELECT_0: J3.37, J4.7
/IDE/IDE_CHIPSELECT_1: J3.38, J4.32
/IDE/IDE_DASP: D2.1 (K), J3.39, J4.45
/IDE/IDE_IO_READ: J3.25, J4.34
/IDE/IDE_IO_READY: J3.27, J4.42
/IDE/IDE_IO_WRITE: J3.23, J4.35
/IDE/IDE_IRQ: J3.31, J4.37
/IDE/IDE_PDIAG: J3.34, J4.46
/IDE/IDE_TRANSFER_MODE: J3.32, J4.24
/IDE_RESET: J3.1, J4.41, R7.2
/OLED/OLED_SCL: A1.7 (GPIO5), J7.3
/OLED/OLED_SDA: A1.6 (GPIO4), J7.4
/RGB LED/RGB_DATA: A1.19 (GPIO14), D3.4 (DIN)
/Reset/PICO_RUN: A1.30 (RUN), H9.1
/Rotary encoder/ENC_A: A1.22 (GPIO17), J8.2
/Rotary encoder/ENC_B: A1.24 (GPIO18), J8.3
/Rotary encoder/ENC_SWITCH: A1.25 (GPIO19), J8.4
/SD card reader/SD_CLK: A1.14 (GPIO10), J1.5 (CLK)
/SD card reader/SD_CS: A1.17 (GPIO13), J1.2 (DAT3/CD), RN1.1 (R1.1)
/SD card reader/SD_MISO: A1.16 (GPIO12), J1.7 (DAT0), RN1.3 (R3.1)
/SD card reader/SD_MOSI: A1.15 (GPIO11), J1.3 (CMD), RN1.2 (R2.1)
/VCC_DETECT: A1.34 (GPIO28_ADC2), R1.1, R2.1
GND: A1.3 (GND), A1.8 (GND), A1.13 (GND), A1.18 (GND), A1.23 (GND), A1.28 (GND), A1.33 (AGND), A1.38 (GND), C1.1, C2.1, C3.2, C4.1, C5.2, C6.2, C7.2, C8.2, C11.1, D3.3 (VSS), H2.2, H3.1 (1_1), H5.1 (1_1), H6.1 (1_1), H7.1 (1_1), H8.2, J1.6 (VSS), J1.9 (SHIELD), J3.2, J3.19, J3.22, J3.24, J3.26, J3.30, J3.40, J4.1, J4.8, J4.9, J4.10, J4.11, J4.12, J4.14, J4.15, J4.16, J4.17, J4.33, J4.50, J4.S1 (S), J4.S2 (S), J5.1, J6.2, J6.3, J7.2, J8.1, J8.5, Q1.2 (E), R2.2, R8.2, Super_Cap3.2, U1.3 (GND), U1.11 (GND), U1.15 (GND), U1.17 (PAD), U2.3
unnamed: D4.2 (A), R4.2, Super_Cap3.1
unnamed: C4.2, FB2.2, H1.1
unnamed: C3.1, FB1.2, H1.2
unnamed: H2.1, R5.1
unnamed: H4.1, U2.1
unnamed: H4.2, U2.2
unnamed: H9.2, Q1.3 (C)
unnamed: Q1.1 (B), R7.1, R8.1
unnamed: FB2.1, U1.10 (OUTN)
unnamed: FB1.1, U1.9 (OUTP)
POWER_5V_SUP: A1.39 (VSYS), C1.2, C2.2, C7.1, C8.1, C11.2, D1.1 (K), D3.1 (VDD), D4.1 (K), J4.13, J4.38, J4.44, R4.1, U1.2 (GAIN_SLOT), U1.7 (VDD), U1.8 (VDD)

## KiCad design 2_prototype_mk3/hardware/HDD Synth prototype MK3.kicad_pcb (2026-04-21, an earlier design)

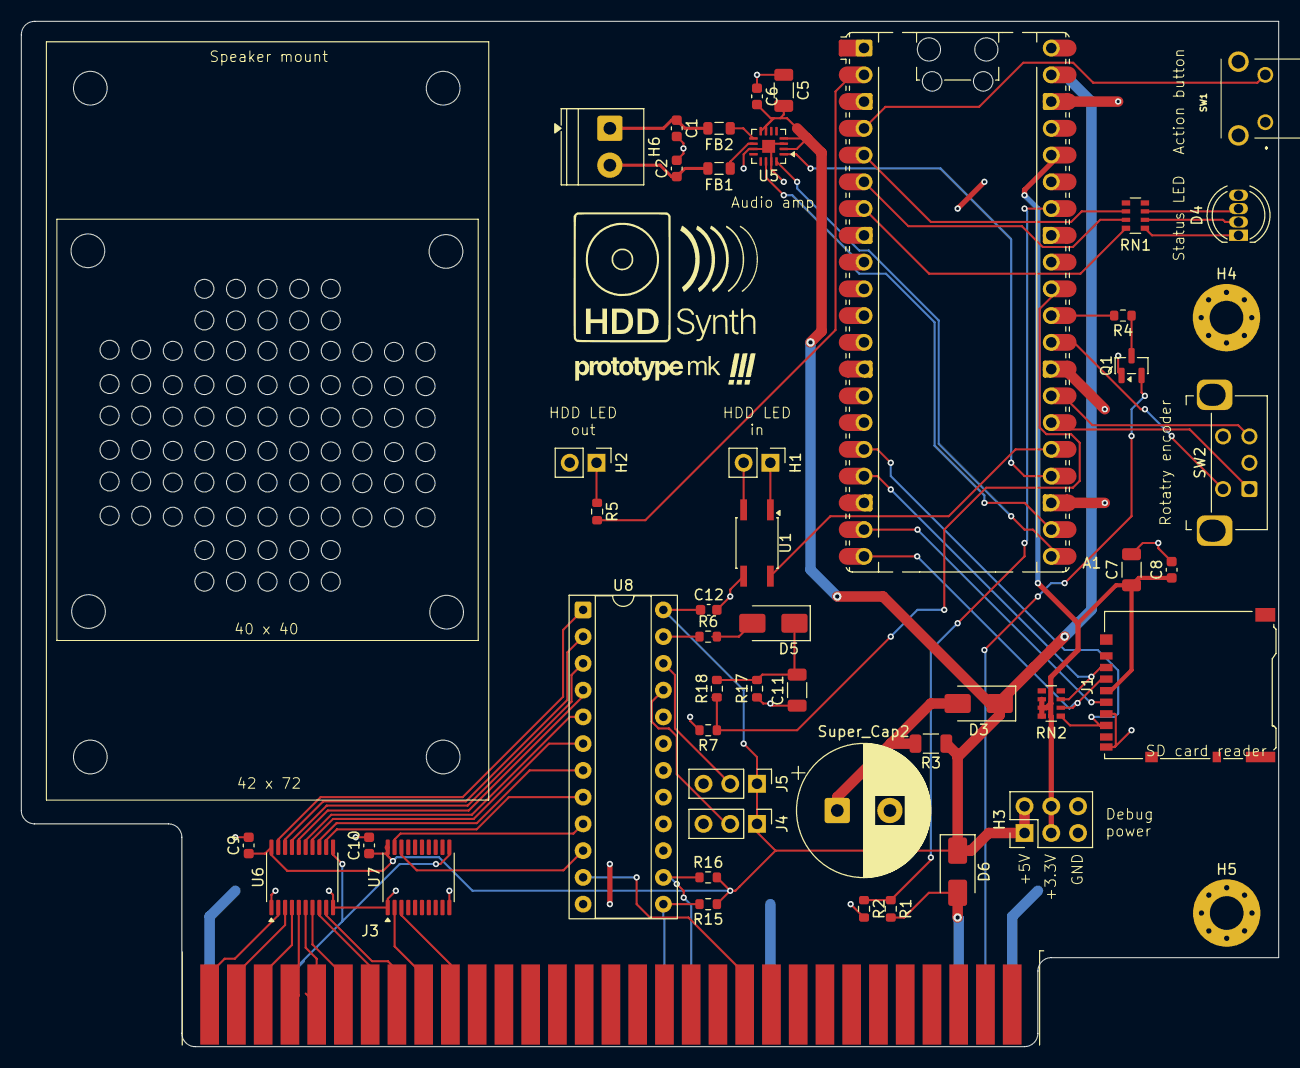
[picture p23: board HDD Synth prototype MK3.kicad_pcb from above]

Board: 2 copper layers, 119.4 x 97.4 mm, 58 parts (1 on the bottom side), 65 nets.

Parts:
 : LOGO; MHDDLA_Sound_40mm
A1: RaspberryPi_Pico2; RaspberryPi_Pico_Common_Unspecified
C1, C2: 1nF; C_0603_1608Metric
C5, C7: 10uF; C_1206_3216Metric
C6, C8, C9, C10, C12: 0.1uF; C_0603_1608Metric
C11: 2.2uF; C_1206_3216Metric
D3, D5: SS12; D_SMA
D4: LED_RGBK; LED_D5.0mm-4_RGB
D6: SS14; D_SMA
FB1, FB2: FerriteBead_Small; L_0805_2012Metric
H1, H2: Conn_01x02; PinHeader_1x02_P2.54mm_Vertical
H3: Debug_power_header; PinHeader_2x03_P2.54mm_Vertical
H4, H5: MountingHole_Pad; MountingHole_3.2mm_M3_Pad_Via
H6: Conn_01x02; TerminalBlock_Phoenix_PT-1,5-2-3.5-H_1x02_P3.50mm_Horizontal
H7, H8, H9, H10, H11, H12, H13, H14: MountingHole; MountingHole_3.2mm_M3
J1: Micro_SD_Card; microSD_HC_Hirose_DM3AT-SF-PEJM5
J3: Bus_ISA_8bit; BUS_AT_8bit
J4, J5: Conn_01x03; PinHeader_1x03_P2.54mm_Vertical
Q1: 2N3904; SOT-23
R1: 1K; R_0603_1608Metric
R2: 2K; R_0603_1608Metric
R3: 33R; R_1206_3216Metric
R4, R17: 10K; R_0603_1608Metric
R5, R6: 330R; R_0603_1608Metric
R7: 3.3K; R_0603_1608Metric
R15, R16: 10R; R_0603_1608Metric
R18: 2.2K; R_0603_1608Metric
RN1: 330R; R_Array_Convex_4x0603
RN2: 47K; R_Array_Convex_4x0603
SW1: SW_Push; PTS645VL582LFS
SW2: PEC12R-2120F-S0012; RotaryEncoder_Bourns_Horizontal_PEC12R-2x17F-Sxxxx
Super_Cap2: 0.47F; CP_Radial_D12.5mm_P5.00mm
U1: Optocoupler_DC_PhotoNPN_AKEC; SO-4_4.4x3.6mm_P2.54mm
U5: MAX98357A; TQFN-16-1EP_3x3mm_P0.5mm_EP1.23x1.23mm
U6, U7: 74LS573; TSSOP-20_4.4x6.5mm_P0.65mm
U8: ATF22V10C-10PU; DIP-24_W7.62mm_Socket

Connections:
+3.3V: A1.36 (3V3), C7.1, C8.1, H3.3, H3.4, J1.4 (VDD), RN2.6 (R3.2), RN2.7 (R2.2), RN2.8 (R1.2)
+5V: D6.2 (A), J3.3 (VCC), R1.2
/ACTION_BUTTON: A1.4 (GPIO2), SW1.2
/AMP_BCLK: A1.21 (GPIO16), U5.16 (BCLK)
/AMP_DIN: A1.24 (GPIO18), U5.1 (DIN)
/AMP_LRC: A1.22 (GPIO17), U5.14 (LRCLK)
/ENC_A: A1.26 (GPIO20), SW2.A
/ENC_B: A1.27 (GPIO21), SW2.B
/ENC_SWITCH: A1.29 (GPIO22), SW2.S1
/HDD_LED_IN: A1.25 (GPIO19), U1.4
/HDD_LED_OUT: A1.2 (GPIO1), R5.2
/IDE_ACTIVITY: A1.31 (GPIO26_ADC0), R7.1, R18.1
/ISA IDE activity detection/AEN: J3.42 (AEN), U8.11 (IN8)
/ISA IDE activity detection/ALE: J3.28 (ALE), U6.11 (Load), U7.11 (Load)
/ISA IDE activity detection/IDE_ACTIVITY_RAW: R6.1, U8.23 (IO9)
/ISA IDE activity detection/IOR: J3.14 (~IOR), R15.2, U8.13 (IN9)
/ISA IDE activity detection/IOW: J3.13 (~IOW), R16.1, U8.14 (IO0)
/ISA IDE activity detection/ISA_A0: J3.62 (BA00), U6.2 (D0)
/ISA IDE activity detection/ISA_A1: J3.61 (BA01), U6.3 (D1)
/ISA IDE activity detection/ISA_A2: J3.60 (BA02), U6.4 (D2)
/ISA IDE activity detection/ISA_A3: J3.59 (BA03), U6.5 (D3)
/ISA IDE activity detection/ISA_A4: J3.58 (BA04), U6.6 (D4)
/ISA IDE activity detection/ISA_A5: J3.57 (BA05), U6.7 (D5)
/ISA IDE activity detection/ISA_A6: J3.56 (BA06), U6.8 (D6)
/ISA IDE activity detection/ISA_A7: J3.55 (BA07), U6.9 (D7)
/ISA IDE activity detection/ISA_A8: J3.54 (BA08), U7.2 (D0)
/ISA IDE activity detection/ISA_A9: J3.53 (BA09), U7.3 (D1)
/ISA IDE activity detection/ISA_AL0: U6.19 (Q0), U8.1 (CLK)
/ISA IDE activity detection/ISA_AL1: U6.18 (Q1), U8.2 (IN0)
/ISA IDE activity detection/ISA_AL2: U6.17 (Q2), U8.3 (IN1)
/ISA IDE activity detection/ISA_AL3: U6.16 (Q3), U8.4 (PD)
/ISA IDE activity detection/ISA_AL4: U6.15 (Q4), U8.5 (IN2)
/ISA IDE activity detection/ISA_AL5: U6.14 (Q5), U8.6 (IN3)
/ISA IDE activity detection/ISA_AL6: U6.13 (Q6), U8.7 (IN4)
/ISA IDE activity detection/ISA_AL7: U6.12 (Q7), U8.8 (IN5)
/ISA IDE activity detection/ISA_AL8: U7.19 (Q0), U8.9 (IN6)
/ISA IDE activity detection/ISA_AL9: U7.18 (Q1), U8.10 (IN7)
/ISA IDE activity detection/RESET: J3.2 (RESET), Q1.2 (B)
/ISA_VCC_DETECT: A1.34 (GPIO28_ADC2), R1.1, R2.1
/SD_CLK: A1.19 (GPIO14), J1.5 (CLK)
/SD_CS: A1.17 (GPIO13), J1.2 (DAT3/CD), RN2.3 (R3.1)
/SD_SI: A1.20 (GPIO15), J1.3 (CMD), RN2.2 (R2.1)
/SD_SO: A1.16 (GPIO12), J1.7 (DAT0), RN2.1 (R1.1)
/STATUS_LED_BLUE: A1.5 (GPIO3), RN1.6 (R3.2)
/STATUS_LED_GREEN: A1.6 (GPIO4), RN1.7 (R2.2)
/STATUS_LED_RED: A1.7 (GPIO5), RN1.8 (R1.2)
GND: A1.3 (GND), A1.8 (GND), A1.13 (GND), A1.18 (GND), A1.23 (GND), A1.28 (GND), A1.38 (GND), C1.2, C2.2, C5.1, C6.1, C7.2, C8.2, C9.2, C10.2, C11.1, C12.2, D4.4 (K), H2.2, H3.5, H3.6, H4.1, H5.1, J1.6 (VSS), J1.9 (SHIELD), J3.1 (GND), J3.10 (GND), J3.31 (GND), J4.3, J5.3, Q1.1 (E), R2.2, R7.2, R17.1, SW1.1, SW2.C, SW2.S2, Super_Cap2.2, U1.3, U5.3 (GND), U5.11 (GND), U5.15 (GND), U5.17 (PAD), U6.1 (OE), U6.10 (GND), U7.1 (OE), U7.10 (GND), U8.12 (GND)
unnamed: A1.30 (RUN), R4.2
unnamed: D3.2 (A), R3.2, Super_Cap2.1
unnamed: D4.3 (BA), RN1.3 (R3.1)
unnamed: D4.2 (GA), RN1.2 (R2.1)
unnamed: D4.1 (RA), RN1.1 (R1.1)
unnamed: D5.2 (A), R6.2
unnamed: C11.2, D5.1 (K), R17.2, R18.2
unnamed: H1.1, U1.1
unnamed: H1.2, U1.2
unnamed: H2.1, R5.1
unnamed: C1.1, FB2.2, H6.1
unnamed: C2.1, FB1.2, H6.2
unnamed: J4.2, U8.21 (IO7)
unnamed: J5.2, U8.22 (IO8)
unnamed: Q1.3 (C), R4.1
unnamed: FB1.1, U5.10 (OUTN)
unnamed: FB2.1, U5.9 (OUTP)
POWER_5V_SUP: A1.39 (VSYS), C5.2, C6.2, C9.1, C10.1, C12.1, D3.1 (K), D6.1 (K), H3.1, H3.2, J4.1, J5.1, R3.1, R15.1, R16.2, U5.2 (GAIN_SLOT), U5.4 (~SD_MODE), U5.7 (VDD), U5.8 (VDD), U6.20 (VCC), U7.20 (VCC), U8.24 (VCC)

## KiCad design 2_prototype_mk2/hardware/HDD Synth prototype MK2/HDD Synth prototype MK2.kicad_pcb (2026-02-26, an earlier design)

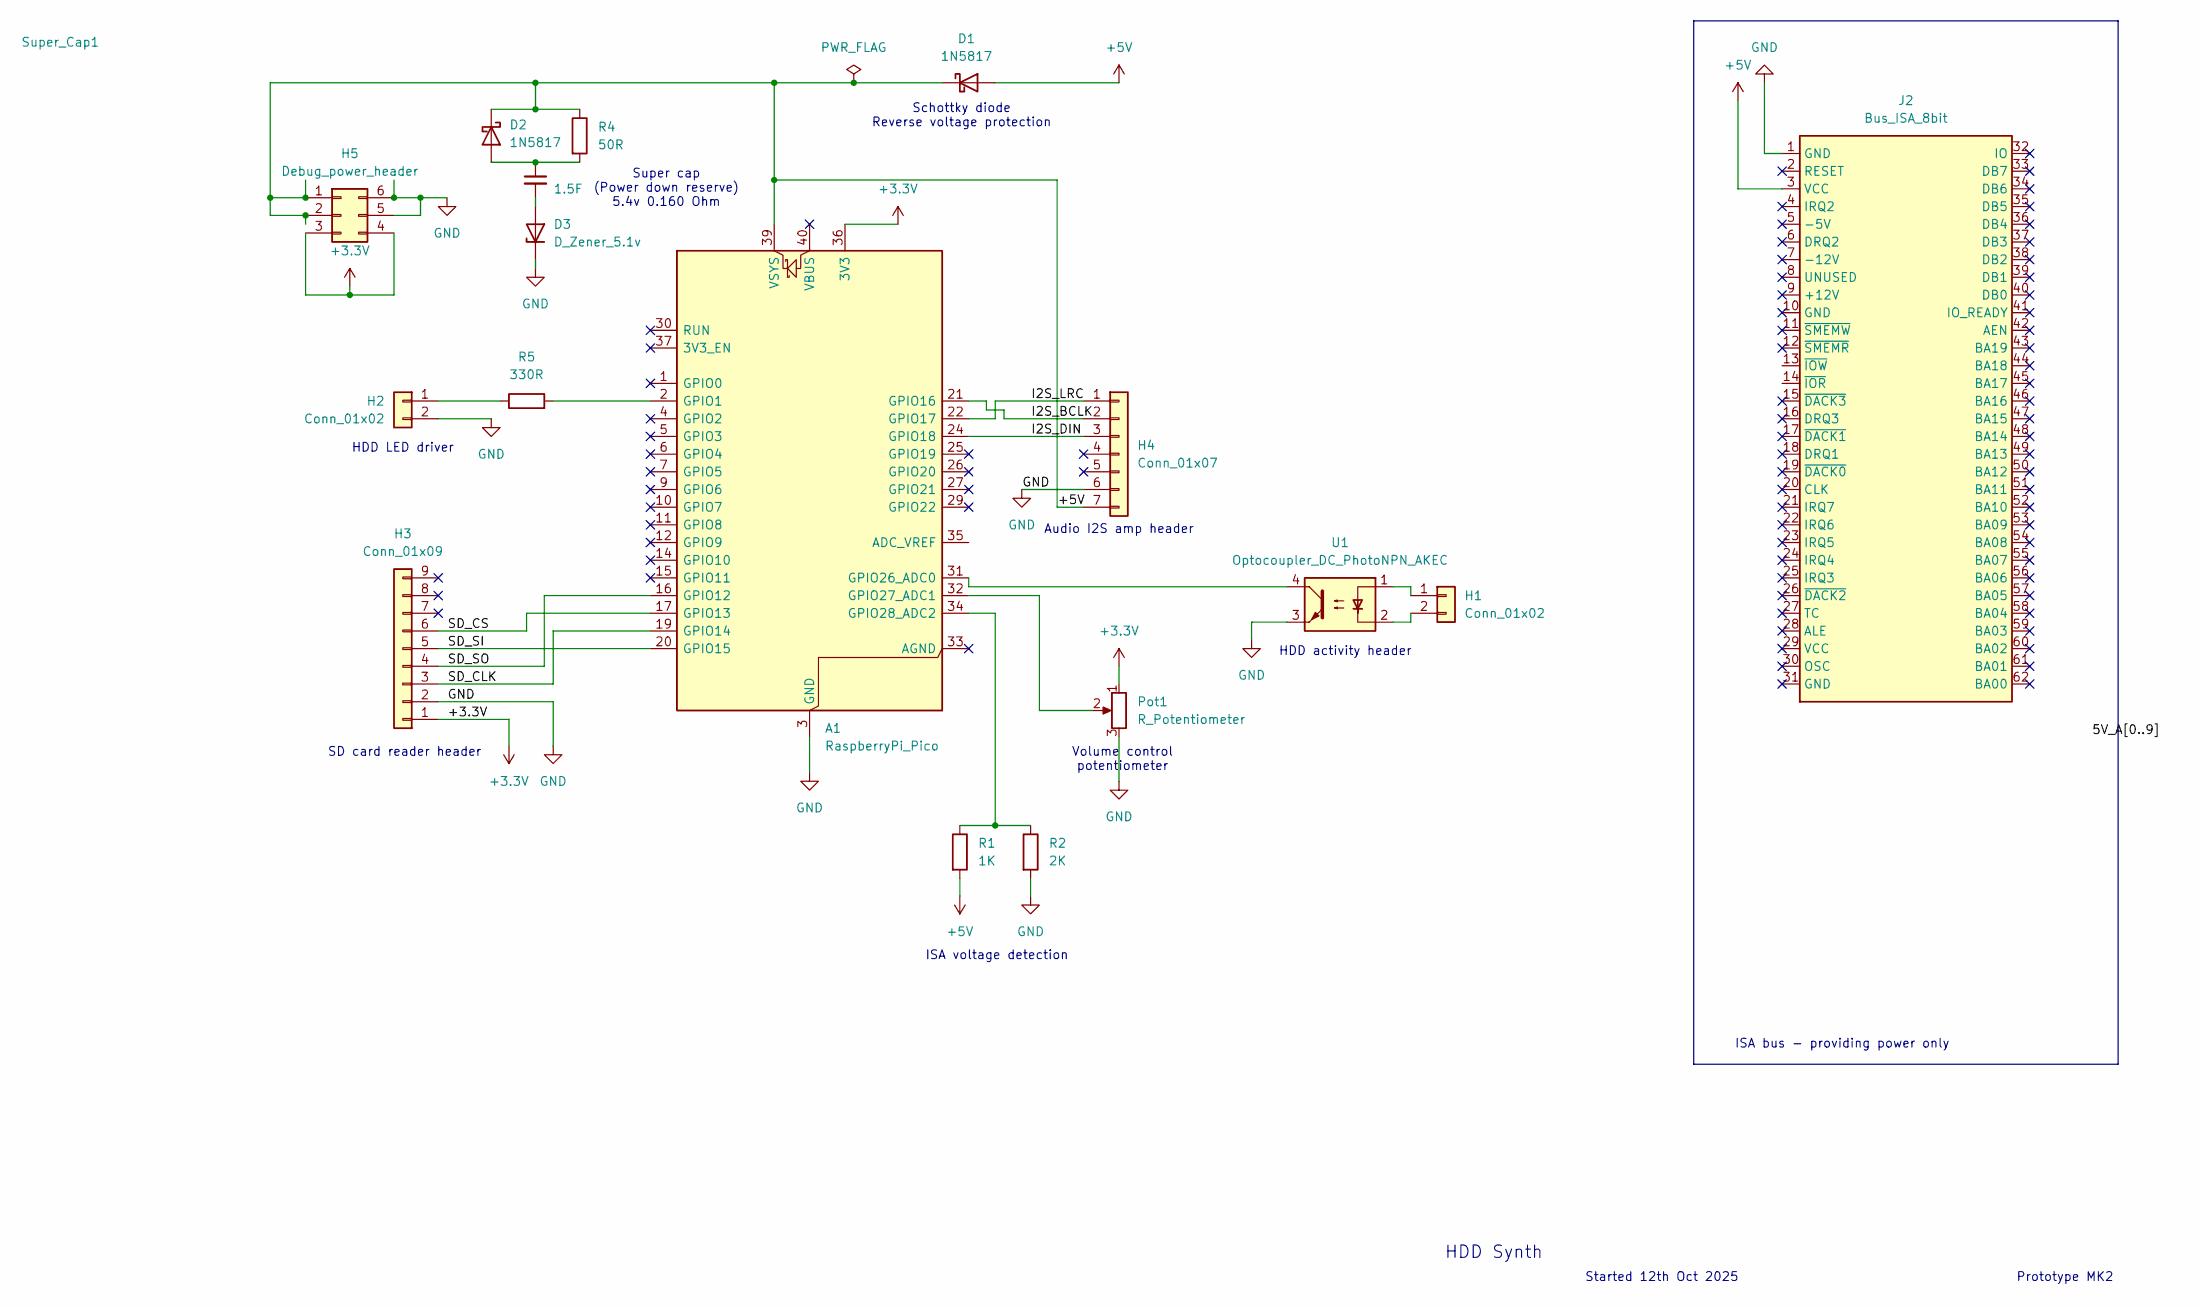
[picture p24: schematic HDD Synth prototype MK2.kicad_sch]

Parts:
A1: RaspberryPi_Pico; RaspberryPi_Pico_Common_Unspecified
D1, D2: 1N5817; D_DO-41_SOD81_P2.54mm_Vertical_AnodeUp
D3: D_Zener_5.1v; D_DO-35_SOD27_P7.62mm_Horizontal
H1, H2: Conn_01x02; PinHeader_1x02_P2.54mm_Vertical
H3: Conn_01x09; PinHeader_1x09_P2.54mm_Vertical
H4: Conn_01x07; PinHeader_1x07_P2.54mm_Vertical
H5: Debug_power_header; PinHeader_2x03_P2.54mm_Vertical
J2: Bus_ISA_8bit; BUS_AT
Pot1: R_Potentiometer; Potentiometer_Bourns_3386W_Horizontal
R1: 1K; R_Axial_DIN0207_L6.3mm_D2.5mm_P7.62mm_Horizontal
R2: 2K; R_Axial_DIN0207_L6.3mm_D2.5mm_P7.62mm_Horizontal
R4: 50R; R_Axial_DIN0207_L6.3mm_D2.5mm_P7.62mm_Horizontal
R5: 330R; R_Axial_DIN0207_L6.3mm_D2.5mm_P7.62mm_Horizontal
Super_Cap1: 1.5F; CP_Radial_D16.0mm_P7.50mm
U1: Optocoupler_DC_PhotoNPN_AKEC; DIP-4_W7.62mm

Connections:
+3.3V: A1.36 (3V3), H3.1, H5.3, H5.4, Pot1.1
+5V: A1.39 (VSYS), D1.1 (K), D1.2 (A), D2.1 (K), H4.7, H5.1, H5.2, J2.3 (VCC), R1.2, R4.1
/I2S_BCLK: A1.21 (GPIO16), H4.2
/I2S_DIN: A1.24 (GPIO18), H4.3
/I2S_LRC: A1.22 (GPIO17), H4.1
/SD_CLK: A1.19 (GPIO14), H3.3
/SD_CS: A1.17 (GPIO13), H3.6
/SD_SI: A1.20 (GPIO15), H3.5
/SD_SO: A1.16 (GPIO12), H3.4
GND: A1.3 (GND), A1.8 (GND), A1.13 (GND), A1.18 (GND), A1.23 (GND), A1.28 (GND), A1.38 (GND), D3.1 (K), H2.2, H3.2, H4.6, H5.5, H5.6, J2.1 (GND), Pot1.3, R2.2, U1.3
unnamed: A1.2 (GPIO1), R5.2
unnamed: A1.31 (GPIO26_ADC0), U1.4
unnamed: A1.32 (GPIO27_ADC1), Pot1.2
unnamed: A1.34 (GPIO28_ADC2), R1.1, R2.1
unnamed: D2.2 (A), R4.2, Super_Cap1.1
unnamed: D3.2 (A), Super_Cap1.2
unnamed: H1.1, U1.1
unnamed: H1.2, U1.2
unnamed: H2.1, R5.1

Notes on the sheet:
Super cap (Power down reserve) 5.4v 0.160 Ohm
HDD Synth
HDD activity header
Started 12th Oct 2025
Volume control potentiometer
ISA voltage detection
Prototype MK2
HDD LED driver
SD card reader header
ISA bus - providing power only
Schottky diode Reverse voltage protection
Audio I2S amp header

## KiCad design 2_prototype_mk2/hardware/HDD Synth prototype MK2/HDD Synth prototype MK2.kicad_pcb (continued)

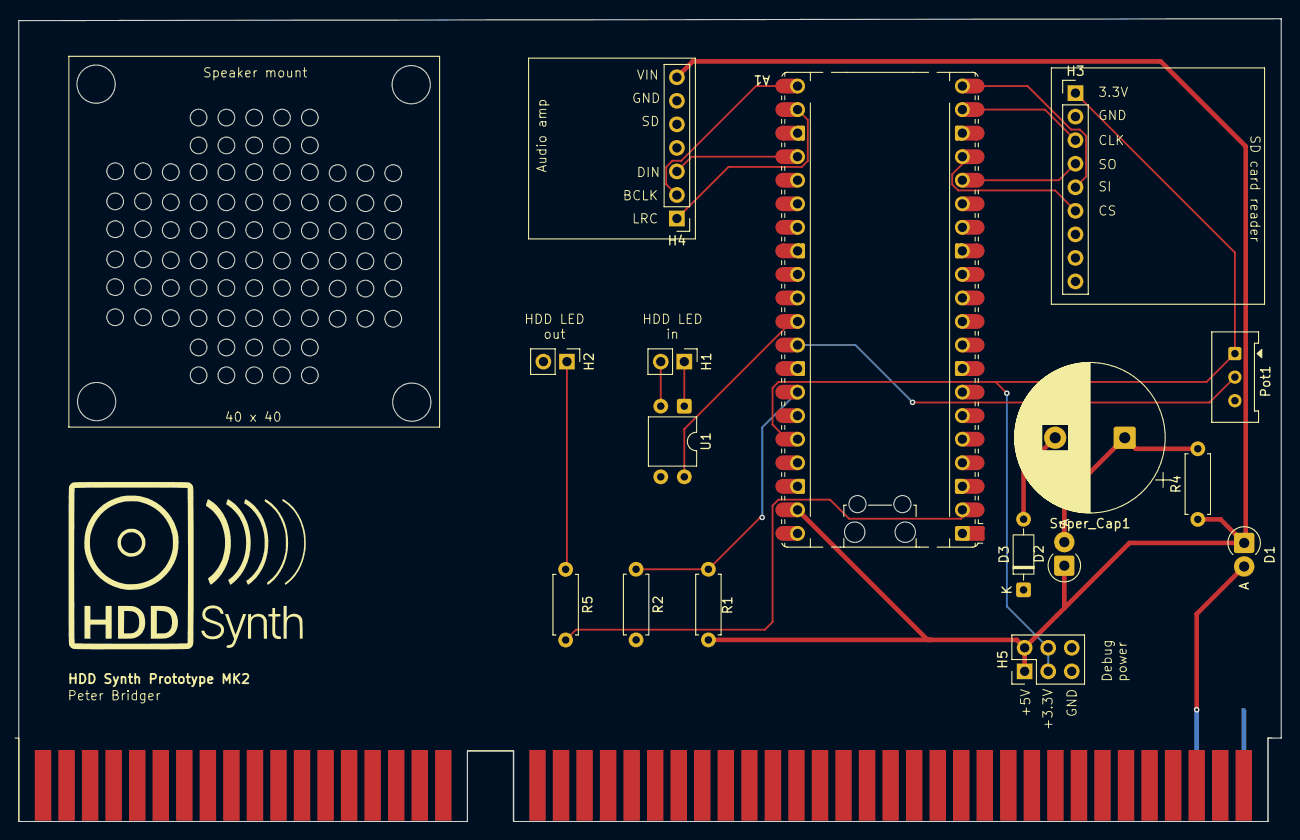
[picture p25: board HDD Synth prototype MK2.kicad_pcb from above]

Board: 2 copper layers, 136.2 x 86.6 mm, 17 parts (0 on the bottom side), 19 nets.

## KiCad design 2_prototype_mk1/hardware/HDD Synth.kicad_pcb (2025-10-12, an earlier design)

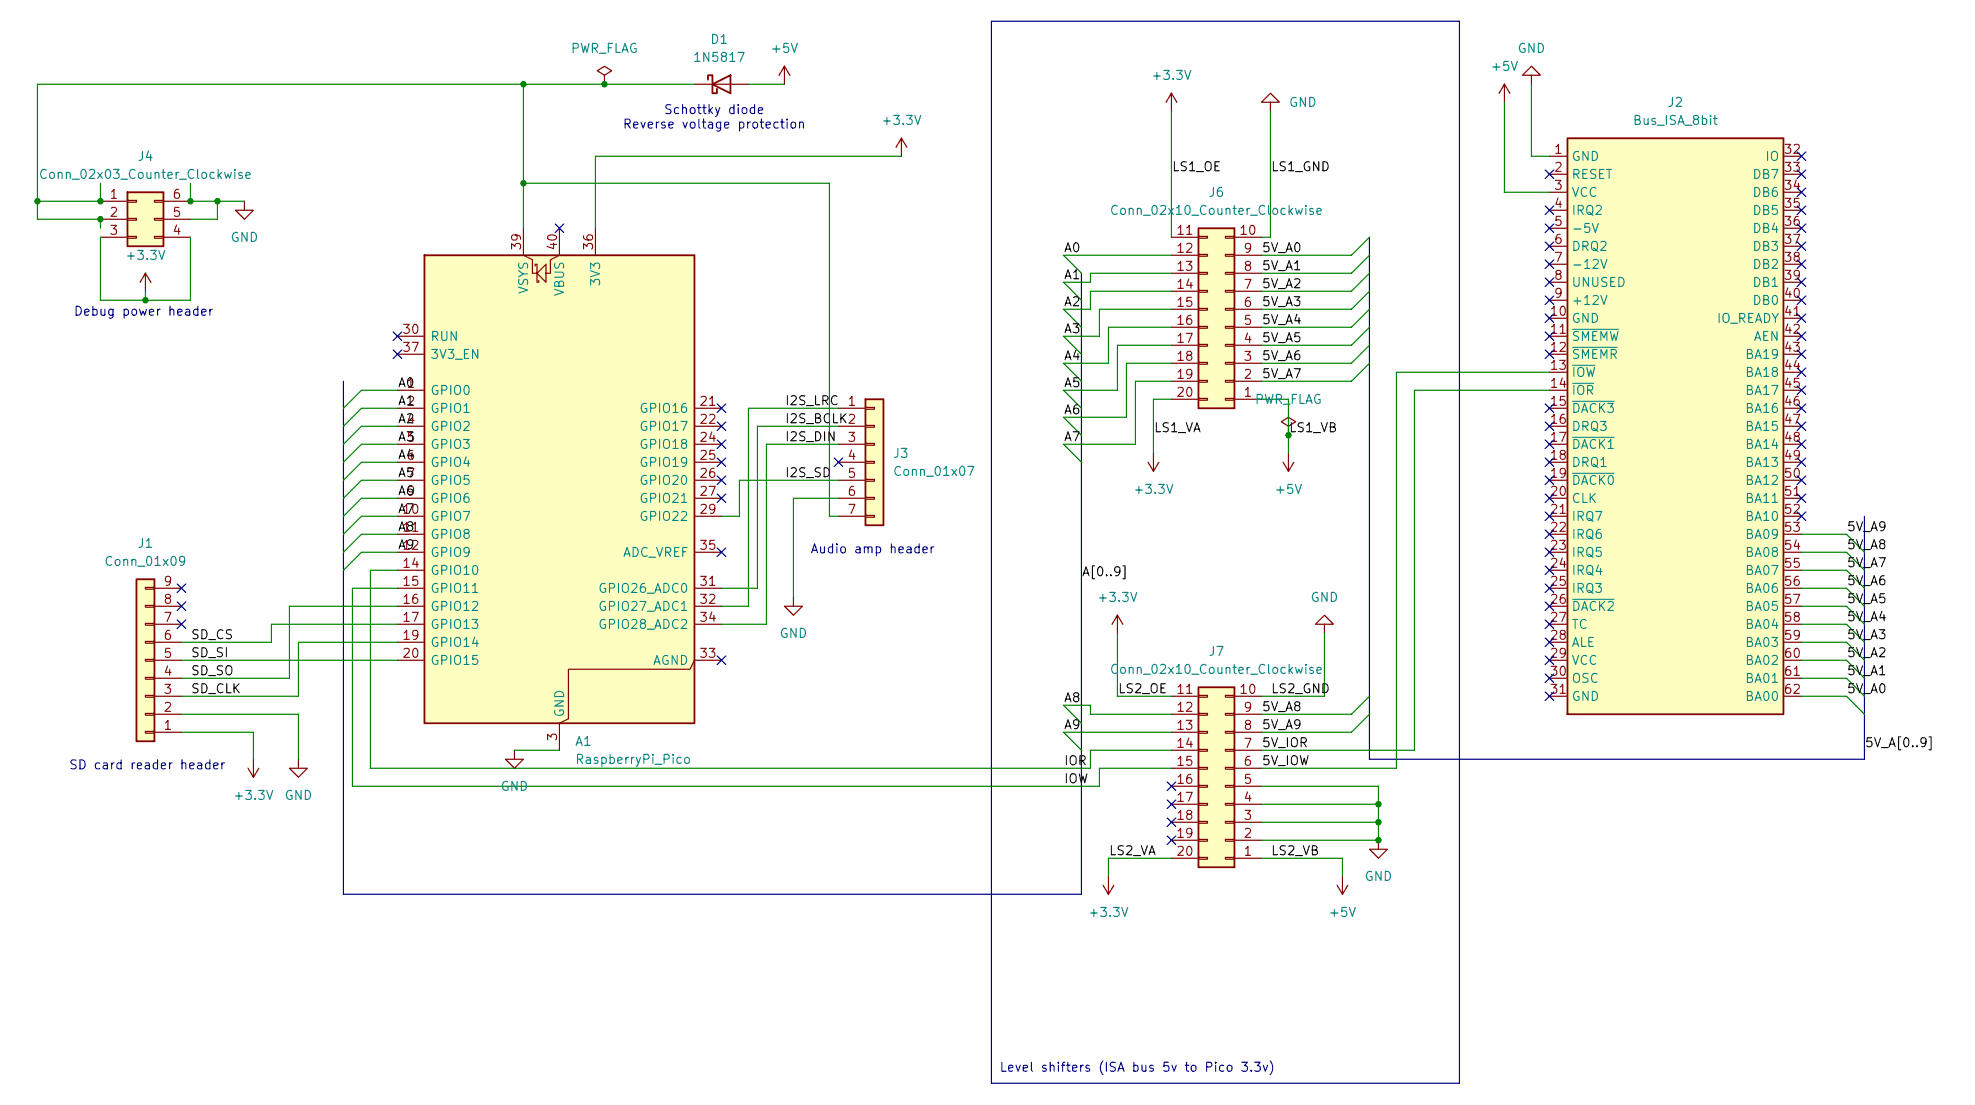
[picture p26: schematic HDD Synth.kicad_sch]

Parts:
A1: RaspberryPi_Pico; RaspberryPi_Pico_Common_Unspecified
D1: 1N5817; D_DO-41_SOD81_P2.54mm_Vertical_AnodeUp
J1: Conn_01x09; PinHeader_1x09_P2.54mm_Vertical
J2: Bus_ISA_8bit; BUS_AT
J3: Conn_01x07; PinHeader_1x07_P2.54mm_Vertical
J4: Conn_02x03_Counter_Clockwise; PinHeader_2x03_P2.54mm_Vertical
J6, J7: Conn_02x10_Counter_Clockwise; TXS0108E_2x10_Header2

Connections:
+3.3V: A1.36 (3V3), J1.1, J4.3, J4.4, J6.11, J6.20, J7.11, J7.20
+5V: D1.2 (A), J2.3 (VCC), J6.1, J7.1
/5V_A0: J2.62 (BA00), J6.9
/5V_A1: J2.61 (BA01), J6.8
/5V_A2: J2.60 (BA02), J6.7
/5V_A3: J2.59 (BA03), J6.6
/5V_A4: J2.58 (BA04), J6.5
/5V_A5: J2.57 (BA05), J6.4
/5V_A6: J2.56 (BA06), J6.3
/5V_A7: J2.55 (BA07), J6.2
/5V_A8: J2.54 (BA08), J7.9
/5V_A9: J2.53 (BA09), J7.8
/5V_IOR: J2.14 (~IOR), J7.7
/5V_IOW: J2.13 (~IOW), J7.6
/A0: A1.1 (GPIO0), J6.12
/A1: A1.2 (GPIO1), J6.13
/A2: A1.4 (GPIO2), J6.14
/A3: A1.5 (GPIO3), J6.15
/A4: A1.6 (GPIO4), J6.16
/A5: A1.7 (GPIO5), J6.17
/A6: A1.9 (GPIO6), J6.18
/A7: A1.10 (GPIO7), J6.19
/A8: A1.11 (GPIO8), J7.12
/A9: A1.12 (GPIO9), J7.13
/I2S_BCLK: A1.31 (GPIO26_ADC0), J3.2
/I2S_DIN: A1.34 (GPIO28_ADC2), J3.3
/I2S_LRC: A1.32 (GPIO27_ADC1), J3.1
/I2S_SD: A1.29 (GPIO22), J3.5
/IOR: A1.14 (GPIO10), J7.14
/IOW: A1.15 (GPIO11), J7.15
/SD_CLK: A1.19 (GPIO14), J1.3
/SD_CS: A1.17 (GPIO13), J1.6
/SD_SI: A1.20 (GPIO15), J1.5
/SD_SO: A1.16 (GPIO12), J1.4
GND: A1.3 (GND), A1.8 (GND), A1.13 (GND), A1.18 (GND), A1.23 (GND), A1.28 (GND), A1.38 (GND), J1.2, J2.1 (GND), J3.6, J4.5, J4.6, J6.10, J7.2, J7.3, J7.4, J7.5, J7.10
unnamed: A1.39 (VSYS), D1.1 (K), J3.7, J4.1, J4.2

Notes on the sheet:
Debug power header
SD card reader header
Level shifters (ISA bus 5v to Pico 3.3v)
Schottky diode Reverse voltage protection
Audio amp header

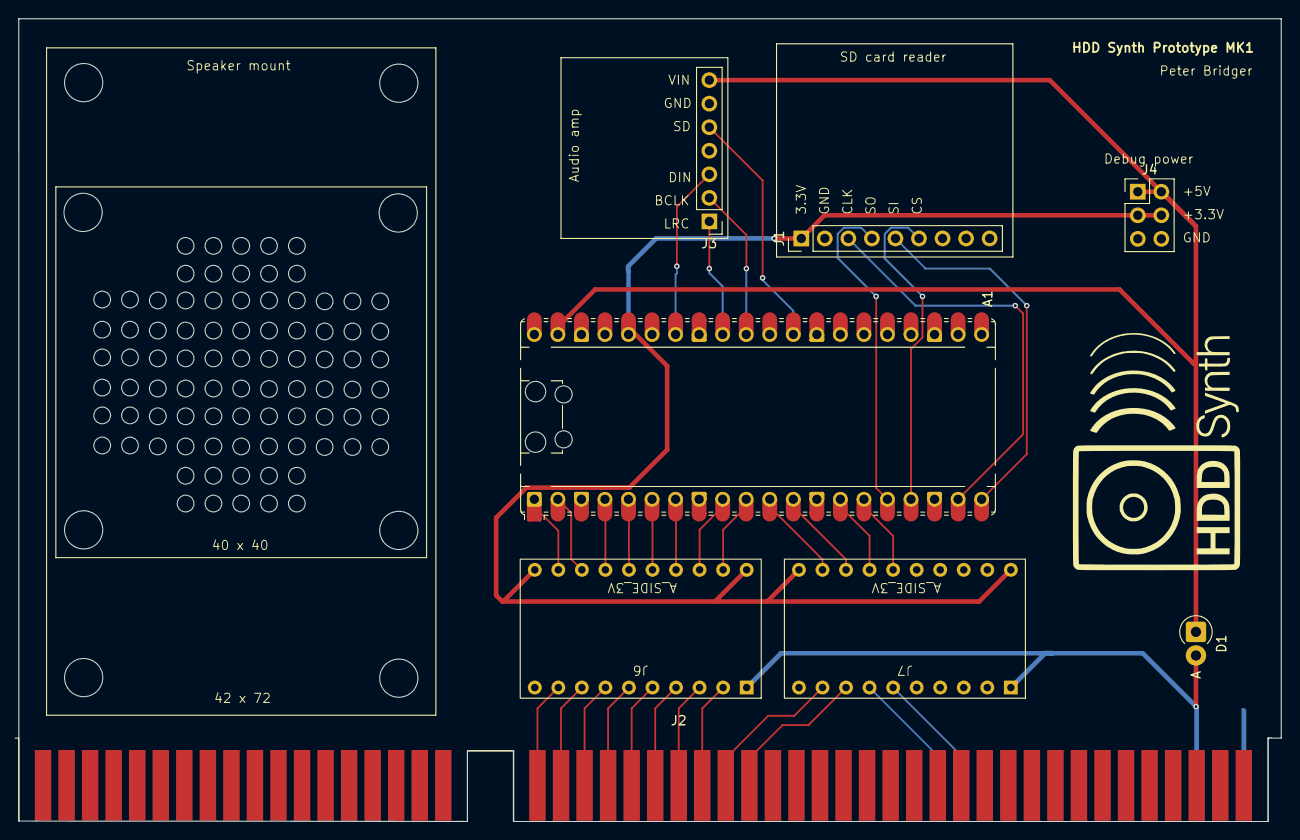
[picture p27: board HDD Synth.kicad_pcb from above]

Board: 2 copper layers, 136.2 x 86.6 mm, 8 parts (0 on the bottom side), 36 nets.

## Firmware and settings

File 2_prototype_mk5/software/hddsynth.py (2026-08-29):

"""
HDD Synth
Making HDDs loud again! (MDDDLA)
"""
import time
import audiobusio
import audiomixer
import digitalio
import board
import microcontroller

import activity
import sample_changer
from sample_container import SampleContainer
import sdcard
import settings
import audio
import action_button
import rotary_enc
import power
import hdd_led
import rgb_led
import nvm_wrapper
import sd_settings
import beep
import amp
from beep_profiles import PROFILE


def _init_audio():
    """Bring up I2S out and the mixer. Returns (audio_out, mixer)."""
    audio_out = audiobusio.I2SOut(
        bit_clock=settings.AMP_BCK_PIN,
        word_select=settings.AMP_WS_PIN,
        data=settings.AMP_SD_PIN,
    )

    # One extra voice on top of MIXER_VOICES is reserved for beeps so they don't
    # interrupt the idle/access loops.
    mixer = audiomixer.Mixer(
        voice_count=settings.MIXER_VOICES + 1,
        sample_rate=settings.DEFAULT_SAMPLE_RATE,
        channel_count=settings.DEFAULT_CHANNEL_COUNT,
        bits_per_sample=settings.DEFAULT_BITS_PER_SAMPLE,
    )

    audio_out.play(mixer)
    return audio_out, mixer


def _load_samples():
    jingle = None
    try:
        jingle = SampleContainer(settings.JINGLE_FILE)
    except OSError:
        print(f"[hddsynth] Jingle not found: {settings.JINGLE_FILE}")

    paths = sample_changer.get_sample_paths()
    return {
        "jingle":   jingle,
        "spinup":   SampleContainer(paths["spinup"]),
        "idle":     SampleContainer(paths["idle"]),
        "access":   SampleContainer(paths["access"]),
        "spindown": SampleContainer(paths["spindown"]),
    }


def _maybe_play_jingle(mixer, samples):
    """Play the jingle at full volume the first time the device boots."""
    already_played = nvm_wrapper.safe_read(settings.NVM_ADDRESS_JINGLE) == settings.NVM_JINGLE_PLAYED
    if already_played and not settings.ALWAYS_PLAY_JINGLE:
        return

    if samples["jingle"] is None:
        print("[hddsynth] Skipping jingle — file not found.")
        return

    print("Playing jingle...")
    audio.play_sample_active_pause(mixer, samples["jingle"], level=1.0)

    if not already_played:
        nvm_wrapper.write(settings.NVM_ADDRESS_JINGLE, settings.NVM_JINGLE_PLAYED)


def _start_dual_voice_loops(mixer, samples):
    """In dual-voice mode, the idle and access samples both loop continuously."""
    if settings.PLAY_IDLE:
        mixer.voice[0].play(samples["idle"].sample, loop=True)
    mixer.voice[1].play(samples["access"].sample, loop=True)
    mixer.voice[1].level = 0  # Start with access muted


_POWER_LOSS_DEBOUNCE_TICKS = 5  # consecutive "no power" reads required before treating power as lost


def _power_present(unpowered_ticks):
    """Debounced power check. Returns (still_powered, updated_unpowered_ticks)."""
    if power.external_power():
        return True, 0

    unpowered_ticks += 1
    return unpowered_ticks < _POWER_LOSS_DEBOUNCE_TICKS, unpowered_ticks


def _main_loop(mixer, samples, led):
    """Run until external power is removed."""
    access = activity.get_access()
    unpowered_ticks = 0

    if settings.MIXER_VOICES == 2:
        _start_dual_voice_loops(mixer, samples)

    powered, unpowered_ticks = _power_present(unpowered_ticks)
    while powered:
        last_access = access
        access = activity.get_access()
        led.value = access
        hdd_led.set_active(access)
        rgb_led.set_activity(access)
        action_button.handler(mixer)
        rotary_enc.handler(mixer)

        if settings.MIXER_VOICES == 1:
            audio.set_volume(mixer)

            # If access state changes, stop current sample
            if last_access != access:
                mixer.voice[0].stop()

            # Idle
            if not access and not mixer.voice[0].playing and settings.PLAY_IDLE and samples.get("idle"):
                mixer.voice[0].play(samples["idle"].sample)
                print(".", end="")

            # Access
            if access and not mixer.voice[0].playing and samples.get("access"):
                mixer.voice[0].play(samples["access"].sample)
                print(",", end="")

        elif settings.MIXER_VOICES == 2:
            audio.set_volume(mixer, access=access)

        time.sleep(0.01)
        powered, unpowered_ticks = _power_present(unpowered_ticks)


def _spindown(mixer, samples):
    rgb_led.off()
    rgb_led.invalidate_activity()
    if settings.PLAY_SPINDOWN:
        print("Playing spindown")
        audio.stop_all(mixer)
        audio.play_sample_active_pause(mixer, samples["spindown"])
    amp.power_off()


def _apply_sd_settings(sd_overrides):
    """Apply settings overrides loaded from SD card."""
    if "SIMULATION_MODE" in sd_overrides:
        settings.SIMULATION_MODE = sd_overrides["SIMULATION_MODE"]
        print(f"[SD Settings] SIMULATION_MODE = {settings.SIMULATION_MODE}")
    if "PLAY_SPINUP" in sd_overrides:
        settings.PLAY_SPINUP = sd_overrides["PLAY_SPINUP"]
        print(f"[SD Settings] PLAY_SPINUP = {settings.PLAY_SPINUP}")
    if "PLAY_SPINDOWN" in sd_overrides:
        settings.PLAY_SPINDOWN = sd_overrides["PLAY_SPINDOWN"]
        print(f"[SD Settings] PLAY_SPINDOWN = {settings.PLAY_SPINDOWN}")
    if "PLAY_IDLE" in sd_overrides:
        settings.PLAY_IDLE = sd_overrides["PLAY_IDLE"]
        print(f"[SD Settings] PLAY_IDLE = {settings.PLAY_IDLE}")
    if "ACCESS_HOLD_TIME_MS" in sd_overrides:
        settings.ACCESS_HOLD_TIME_MS = sd_overrides["ACCESS_HOLD_TIME_MS"]
        print(f"[SD Settings] ACCESS_HOLD_TIME_MS = {settings.ACCESS_HOLD_TIME_MS}")
    if "VOLUME_DEFAULT" in sd_overrides:
        settings.VOLUME_DEFAULT = sd_overrides["VOLUME_DEFAULT"]
        print(f"[SD Settings] VOLUME_DEFAULT = {settings.VOLUME_DEFAULT}")
    if "BALANCE_DEFAULT" in sd_overrides:
        settings.BALANCE_DEFAULT = sd_overrides["BALANCE_DEFAULT"]
        print(f"[SD Settings] BALANCE_DEFAULT = {settings.BALANCE_DEFAULT}")
    if "SDCARD_CACHE_SAMPLES" in sd_overrides:
        settings.SDCARD_CACHE_SAMPLES = sd_overrides["SDCARD_CACHE_SAMPLES"]
        print(f"[SD Settings] SDCARD_CACHE_SAMPLES = {settings.SDCARD_CACHE_SAMPLES}")
    if "ACTIVITY_LED_ENABLED" in sd_overrides:
        settings.ACTIVITY_LED_ENABLED = sd_overrides["ACTIVITY_LED_ENABLED"]
        print(f"[SD Settings] ACTIVITY_LED_ENABLED = {settings.ACTIVITY_LED_ENABLED}")
    if "RGB_LED_BRIGHTNESS" in sd_overrides:
        brightness = rgb_led.parse_brightness(sd_overrides["RGB_LED_BRIGHTNESS"])
        if brightness is None:
            print(f"[SD Settings] Ignoring invalid RGB_LED_BRIGHTNESS: {sd_overrides['RGB_LED_BRIGHTNESS']}")
        else:
            settings.RGB_LED_BRIGHTNESS = brightness
            rgb_led.invalidate_activity()
            print(f"[SD Settings] RGB_LED_BRIGHTNESS = {settings.RGB_LED_BRIGHTNESS}")
    if "ACTIVITY_LED_COLOUR" in sd_overrides:
        colour = rgb_led.parse_colour(sd_overrides["ACTIVITY_LED_COLOUR"])
        if colour is None:
            print(f"[SD Settings] Ignoring invalid ACTIVITY_LED_COLOUR: {sd_overrides['ACTIVITY_LED_COLOUR']}")
        else:
            settings.ACTIVITY_LED_COLOUR = colour
            print(f"[SD Settings] ACTIVITY_LED_COLOUR = {settings.ACTIVITY_LED_COLOUR}")


def _make_reload_callback(samples):
    """Returns a closure that hot-swaps the active sample pack in-place."""
    def reload(mixer):
        import gc
        print("[hddsynth] Reloading sample pack...")
        audio.stop_all(mixer)

        # Free the three playback samples before allocating new ones.
        # Spinup and jingle are not reloaded — spinup is only played once at boot
        # and jingle is only played once at first boot.
        for key in ("idle", "access", "spindown"):
            s = samples.get(key)
            if s is not None:
                try:
                    s.deinit()
                except Exception as e:
                    print(f"[hddsynth] deinit warning ({key}): {e}")
                samples[key] = None
        gc.collect()

        try:
            paths = sample_changer.get_sample_paths()
            samples["idle"]     = SampleContainer(paths["idle"])
            samples["access"]   = SampleContainer(paths["access"])
            samples["spindown"] = SampleContainer(paths["spindown"])
            print("[hddsynth] Pack reloaded: " + sample_changer.get_desired_pack())
        except Exception as e:
            print(f"[hddsynth] Pack reload failed: {e}")
        finally:
            if settings.MIXER_VOICES == 2 and samples.get("idle") and samples.get("access"):
                _start_dual_voice_loops(mixer, samples)
    return reload


def _no_op_action_button_handler(mixer):
    """No-op handler when action button is disabled."""
    pass


def _wait_for_power_and_reset():
    while not power.external_power():
        time.sleep(0.1)
    microcontroller.reset()


def _halt_on_boot_error(beep_type=None):
    """Stop here after a boot-time error (e.g. no SD card) instead of resetting.

    Unlike _wait_for_power_and_reset(), power hasn't actually changed here —
    resetting immediately would loop forever while USB-powered.

    The beep has already sounded once; from here the status LED keeps repeating
    the same flash pattern in red so the fault stays visible.
    """
    profile = PROFILE.get(beep_type) if beep_type else None

    while True:
        if profile is None:
            time.sleep(1)
            continue

        length = profile.get("length", 0.1)
        rgb_led.flash(
            settings.RGB_LED_ERROR_COLOUR,
            profile.get("count", 1),
            length,
            gap_time=(length * 0.4) + beep.RELEASE_BUFFER_S,
        )
        time.sleep(settings.RGB_LED_ERROR_REPEAT_S)


def _check_sample_pack_installed():
    """Check if a sample pack is installed (by checking if desired pack is set)."""
    return bool(sample_changer.get_desired_pack())


def run_synth():
    print("Starting HDD Synth...")

    # Pico onboard LED — mirrors access state for dev visibility
    led = digitalio.DigitalInOut(board.LED)
    led.direction = digitalio.Direction.OUTPUT

    # Power-on check that all three RGB channels light.
    rgb_led.startup_test()

    # Yellow flashing from here until spinup: the synth isn't in normal
    # operation yet, so the user knows to wait.
    rgb_led.busy_tick()

    _, mixer = _init_audio()
    rgb_led.busy_tick()

    # Try to initialize SD card
    sd_available = sdcard.initialise(mixer)
    rgb_led.busy_tick()

    # Load and apply settings from SD card if available
    if sd_available:
        sd_overrides = sd_settings.load_settings()
        _apply_sd_settings(sd_overrides)
    else:
        sd_overrides = {}
    rgb_led.busy_tick()

    # Check if sample pack is installed
    sample_pack_installed = _check_sample_pack_installed()

    # Handle SDCARD_REQUIRED logic
    if not sd_available:
        if settings.SDCARD_REQUIRED or not settings.SDCARD_CACHE_SAMPLES:
            print("[hddsynth] SD card required but not available, exiting")
            beep.play_beep_type(mixer, "NO_SD_CARD")
            _halt_on_boot_error("NO_SD_CARD")
            return

        if not sample_pack_installed:
            print("[hddsynth] No sample pack installed and SD card not available, playing error beep")
            beep.play_beep_type(mixer, "PACK_NOT_FOUND")
            _halt_on_boot_error("PACK_NOT_FOUND")
            return

        print("[hddsynth] SD card not available but sample pack is installed, disabling action button")
        action_button.handler = _no_op_action_button_handler

    print("HDD Sample Pack: " + sample_changer.get_desired_pack())

    # Handle sample pack installation from SD card (only if SD is available)
    if sd_available:
        pack_install_ok = sd_settings.install_sample_pack_if_needed(sd_overrides)
        if not pack_install_ok:
            print("[hddsynth] Sample pack from SD settings not found, playing error beep")
            beep.play_beep_type(mixer, "PACK_NOT_FOUND")

    rgb_led.busy_tick()
    samples = _load_samples()
    rgb_led.busy_tick()

    if not settings.SDCARD_CACHE_SAMPLES:
        action_button.set_reload_callback(_make_reload_callback(samples))

    # Startup work is done — stop the "please wait" indication before the jingle
    # and spinup, which are part of normal operation.
    rgb_led.busy_end()

    _maybe_play_jingle(mixer, samples)
    if samples.get("jingle") is not None:
        samples["jingle"].deinit()
        samples["jingle"] = None

    audio.set_volume(mixer)

    amp.power_on()

    if settings.PLAY_SPINUP:
        print("Playing spinup")
        audio.play_sample_active_pause(mixer, samples["spinup"])
        print("Spin up complete")
    if samples.get("spinup") is not None:
        samples["spinup"].deinit()
        samples["spinup"] = None

    _main_loop(mixer, samples, led)
    _spindown(mixer, samples)
    _wait_for_power_and_reset()


if __name__ == "__main__":
    run_synth()

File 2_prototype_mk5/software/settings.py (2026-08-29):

import board

SIMULATION_MODE = True # Simulate HDD activity
PLAY_SPINUP = True
PLAY_SPINDOWN = True
PLAY_IDLE = True
ALWAYS_PLAY_JINGLE = False

ACCESS_HOLD_TIME_MS = 100 # How long to hold the access sample after an access is detected (in ms)

POWER_DETECTION = True # If True, use the power.py logic to detect if we have external power. If False, assume we always have power

# Power Sensing (external power detection via voltage divider)
POWER_SENSE_PIN = board.GP28        # ADC pin reading the divided external voltage
POWER_RESISTOR_TO_5V = 10000        # 10k Ohm (upper resistor in divider)
POWER_RESISTOR_TO_GND = 10000       # 10k Ohm (lower resistor in divider)
POWER_ADC_REF_VOLTAGE = 3.3         # Pico's internal reference
POWER_MAX_ADC_VALUE = 65535         # CircuitPython 16-bit scaling
POWER_VOLTAGE_THRESHOLD_EXT = 4.0   # External voltage (0V-5V) that triggers "powered" state

# HDD Activity
ACTIVITY_INPUT_PIN = board.GP18    # Optocoupler output from HDD activity signal (LOW = active)
HDD_LED_PIN = board.GP17            # External HDD activity LED

# RGB status LED (XL-3528RGBW-HM, LCSC C2843813)
# Common anode: the shared pin sits at +3V3 and each colour's cathode is driven
# by a GPIO, so driving a pin LOW turns that channel ON (PWM duty is inverted).
# Per-channel series resistors (R19 270R red, R18 56R green, R20 33R blue) already
# balance the channel brightness, so equal duty cycles give a roughly neutral mix.
RGB_LED_RED_PIN = board.GP4
RGB_LED_GREEN_PIN = board.GP5
RGB_LED_BLUE_PIN = board.GP6
RGB_LED_PWM_FREQUENCY = 1000   # Hz — well above flicker, well below audio pickup concerns
RGB_LED_STARTUP_TEST_S = 1.0   # Duration of the power-on hue sweep (0 to disable)
RGB_LED_STARTUP_TEST_STEPS = 60

# HDD activity indication on the RGB status LED
ACTIVITY_LED_ENABLED = True         # False turns the activity indication off entirely
ACTIVITY_LED_COLOUR = (0, 255, 0)   # (R, G, B) 0-255 shown while the HDD is being accessed

# Status colours. Error and operation flashes are driven in time with the matching
# beep profile (see beep_profiles.py), so the LED and the buzzer tell the same story.
RGB_LED_ERROR_COLOUR = (255, 0, 0)       # Error beep profiles
RGB_LED_OPERATION_COLOUR = (0, 0, 255)   # Operational change beep profiles
RGB_LED_BUSY_COLOUR = (255, 255, 0)      # Internal activity before normal operation begins
RGB_LED_ERROR_REPEAT_S = 4.0             # Gap before a latched error pattern repeats
RGB_LED_BUSY_FLASH_S = 0.25              # Half-period of the busy flash

# Master brightness (0.0 - 1.0) scaling every colour the status LED shows.
RGB_LED_BRIGHTNESS = 0.5

# Action Button
ACTION_BUTTON_PIN = board.GP19              # GPIO pin the action button is wired to
ACTION_BUTTON_SHORT_PRESS_MAX_S = 1.0      # Max press duration to register as a short press
ACTION_BUTTON_LONG_PRESS_S = 3.0           # Seconds the button must be held to register as a long press

# Mixer
MIXER_VOICES = 2 # If 1, swap out idle for access. If 2, play idle loop with access overlaid

# Rotary Encoder (used for volume and balance)
ENCODER_A_PIN = board.GP20       # Rotary encoder channel A
ENCODER_B_PIN = board.GP21       # Rotary encoder channel B
ENCODER_BUTTON_PIN = board.GP22  # Encoder push button (toggles volume <-> balance mode)

# OLED display (I2C)
OLED_SDA_PIN = board.GP24        # I2C SDA (data)
OLED_SCL_PIN = board.GP25        # I2C SCL (clock)

# Volume
VOLUME_DEFAULT = 0.5          # Starting volume (0.0 - 1.0)
VOLUME_STEP = 0.05             # Volume change per encoder detent (0.0 - 1.0)
VOLUME_PRINT = False          # Print volume changes to console

# Balance (idle vs access mix when MIXER_VOICES == 2)
BALANCE_DEFAULT = 0.5         # Starting balance (0.0 = idle only, 1.0 = access only)
BALANCE_STEP = 0.1            # Balance change per encoder detent (0.0 - 1.0)
BALANCE_PRINT = False         # Print balance changes to console

# SD Card
SDCARD_REQUIRED = False         # If True, device won't run without SD card. If False, device can run without SD (if sample pack is installed)
SDCARD_CACHE_SAMPLES = False     # If True, sample packs are copied from SD to Pico flash before playback (faster, SD removable after boot).
                                # If False, samples stream directly from SD card (no caching step, SD must remain inserted).
SDCARD_BAUDRATE = 25_000_000    # SPI clock speed: 400_000 (init/safe), 8_000_000 (conservative), 12_500_000 (balanced), 25_000_000 (max)
SDCARD_SCK_PIN = board.GP10    # SPI Clock
SDCARD_MOSI_PIN = board.GP11   # SPI MOSI
SDCARD_MISO_PIN = board.GP8    # SPI MISO
SDCARD_CS_PIN = board.GP9      # SPI Chip Select

SDCARD_MOUNT_POINT = '/sd'  # Mount point for the SD card
SDCARD_SAMPLE_DIR = f"{SDCARD_MOUNT_POINT}/samples" # Directory on SD card where sample packs are stored
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

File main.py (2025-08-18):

"""
HDD Synth - CircuitPython Version
Monitors ISA bus for HDD activity and plays mechanical hard drive audio samples.
Based on the working CircuitPython PoC approach.
"""

import time
import board
import digitalio
import audiobusio
import audiocore
import audiomixer

# Import configuration
from config import *

class HDDSynth:
    """HDD Synth system using CircuitPython audio libraries."""
    
    def __init__(self):
        """Initialize the HDD Synth system."""
        self._log("Initializing HDD Synth...")
        
        # Initialize hardware components
        self._init_pins()
        self._init_audio_storage()
        self._init_audio_system()
        self._init_isa_monitoring()
        
        # Audio state
        self.last_hdd = False
        
        # HDD activity detection state (like main_mk3_debounce.py)
        self.hdd_activity_counter = 0
        self.hdd_poll_counter = 0
        self.last_activity_time = 0
        
        self._log("HDD Synth initialization complete")
    
    def _log(self, message, level="INFO"):
        """Log messages with timestamp and level."""
        timestamp = time.monotonic()
        print(f"[{timestamp:6.1f}s] {level}: {message}")
    
    def _create_digital_pin(self, pin_number, direction, pull=None, initial_value=None):
        """Helper method to create and configure a digital pin."""
        pin = digitalio.DigitalInOut(getattr(board, f"GP{pin_number}"))
        pin.direction = direction
        if pull:
            pin.pull = pull
        if initial_value is not None:
            pin.value = initial_value
        return pin
    
    def _init_pins(self):
        """Initialize GPIO pins for hardware connections."""
        self._log("Initializing GPIO pins...")
        
        # ISA Bus Monitoring Pins
        self.addr_pins = []
        for i in range(ADDR_PIN_COUNT):
            pin = self._create_digital_pin(ADDR_PIN_BASE + i, digitalio.Direction.INPUT, digitalio.Pull.UP)
            self.addr_pins.append(pin)
        
        # IOR and IOW pins
        self.ior_pin = self._create_digital_pin(IOR_PIN, digitalio.Direction.INPUT, digitalio.Pull.UP)
        self.iow_pin = self._create_digital_pin(IOW_PIN, digitalio.Direction.INPUT, digitalio.Pull.UP)
        
        # Mute pin for amplifier (start muted)
        self.mute_pin = self._create_digital_pin(MUTE_PIN, digitalio.Direction.OUTPUT, initial_value=True)
        
        self._log(f"Initialized {len(self.addr_pins)} address pins, IOR, IOW, and mute pins")
    
    def _init_audio_storage(self):
        """Initialize audio file storage from Pico flash memory."""
        self._log("Initializing audio storage from flash memory...")
        
        try:
            import os
            
            # Check what's available in the root filesystem
            root_contents = os.listdir('/')
            self._log(f"Root filesystem contents: {root_contents}")
            
            # Look for our required audio files in the root filesystem
            required_files = [SPINUP_FILE, IDLE_FILE, ACCESS_FILE]
            available_files = [f for f in root_contents if f.endswith('.wav')]
            self._log(f"Available WAV files: {available_files}")
            
            # Check if all required files are present
            missing_files = []
            for required_file in required_files:
                if required_file not in available_files:
                    missing_files.append(required_file)
            
            if missing_files:
                raise Exception(f"Missing required audio files in flash memory: {missing_files}")
            
            # Store the mount point as root since files are in flash memory
            self.audio_mount_point = '/'
            
            # List available audio files
            self._log("Audio storage accessible successfully with all required audio files")
            self._list_audio_files()
            
        except Exception as e:
            self._log(f"Audio storage initialization failed: {e}", "ERROR")
            raise
    
    def _list_audio_files(self):
        """List available audio files in flash memory."""
        try:
            import os
            files = os.listdir(self.audio_mount_point)
            audio_files = [f for f in files if f.endswith('.wav')]
            self._log(f"Found {len(audio_files)} WAV files: {audio_files}")
        except Exception as e:
            self._log(f"Could not list audio files: {e}", "WARNING")
    
    def _init_audio_system(self):
        """Initialize CircuitPython audio system."""
        self._log("Initializing audio system...")
        
        try:
            # Initialize I2S audio output (like the working PoC)
            self.audio_out = audiobusio.I2SOut(
                bit_clock=getattr(board, f"GP{BCK_PIN}"),
                word_select=getattr(board, f"GP{WS_PIN}"),
                data=getattr(board, f"GP{SD_PIN}")
            )
            
            # Load audio files first
            self._load_audio_files()
            
            # Debug: Check what we actually have after loading
            self._log(f"After loading - spinup: {self.spinup}")
            self._log(f"After loading - idle: {self.idle}")
            self._log(f"After loading - access: {self.access}")
            
            self._log("Audio system initialized successfully")
            
        except Exception as e:
            self._log(f"Audio system initialization failed: {e}", "ERROR")
            raise
    
    def _load_audio_files(self):
        """Load audio files from flash memory."""
        self._log("Loading audio files...")
        
        try:
            # Load all audio files
            audio_files = {
                'spinup': SPINUP_FILE,
                'idle': IDLE_FILE,
                'access': ACCESS_FILE
            }
            
            for audio_type, filename in audio_files.items():
                # Load from flash memory (root filesystem) - like the working PoC
                try:
                    self._log(f"Attempting to load {audio_type}: {filename}")
                    audio_file = open(filename, "rb")
                    self._log(f"File opened successfully, creating WaveFile object")
                    wave_file = audiocore.WaveFile(audio_file)
                    self._log(f"WaveFile object created: {type(wave_file)}")
                    setattr(self, audio_type, wave_file)
                    self._log(f"Set {audio_type} attribute to: {getattr(self, audio_type)}")
                except OSError as e:
                    raise FileNotFoundError(f"Could not load {filename} from flash memory: {e}")
                except Exception as e:
                    self._log(f"Error loading {filename}: {e}", "ERROR")
                    raise
            
        except Exception as e:
            self._log(f"Failed to load audio files: {e}", "ERROR")
            raise
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

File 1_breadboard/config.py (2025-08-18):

# config.py
# Configuration file for HDD Synth
# Modify these settings to match your hardware setup

# --- Hardware Configuration ---
# ISA Bus Monitoring Pins
ADDR_PIN_BASE = 0          # First GPIO pin for address bus (A0)
ADDR_PIN_COUNT = 10        # Number of address pins to monitor (A0-A9)
IOR_PIN = 10               # GPIO pin for ISA IOR signal
IOW_PIN = 11               # GPIO pin for ISA IOW signal

# SD Card Pins (SPI)
SCK_PIN = 14               # SPI Clock
MOSI_PIN = 15              # SPI MOSI
MISO_PIN = 12              # SPI MISO
CS_PIN = 13                # SPI Chip Select
MOUNT_POINT = '/sd'        # SD card mount point

# Audio Pins (Pico Audio Pack)
BCK_PIN = 26               # Bit Clock (SCK)
WS_PIN = 27                # Word Select (WS)
SD_PIN = 28                # Serial Data (SD)
MUTE_PIN = 22              # Mute pin for amplifier (active low)

# --- Audio Configuration ---
SAMPLE_RATE_HZ = 16000     # Audio sample rate
BITS_PER_SAMPLE = 16       # Audio bit depth
CHANNELS = 1               # 1 = Mono, 2 = Stereo

# HDD Activity Detection
HDD_DATA_PORT = 0x1F0      # HDD data port address
HDD_STATUS_PORT = 0x1F7    # HDD status port address
ACTIVITY_THRESHOLD = 20    # Threshold for sustained activity detection (like main_mk3_debounce.py)
ACTIVITY_TIMEOUT_MS = 50   # Timeout for activity detection (milliseconds) - reset counters if no activity

# --- Audio File Names ---
# These must match the exact filenames on your SD card
SPINUP_FILE = "nec_spinup.wav"      # HDD spinup sound
IDLE_FILE = "nec_idle_long.wav"     # HDD idle sound (looped) - using the longer version
ACCESS_FILE = "nec_access.wav"      # HDD access sound

# --- ISA Bus Configuration ---
ISA_BUS_FREQ = 12_500_000  # PIO state machine frequency (12.5 MHz)
ADDRESS_BITMASK = 0xFF      # Bitmask for address comparison (lower 8 bits)

# --- Debug Settings ---
SIMULATION_MODE = True      # Simulate HDD activity for testing (like CircuitPython PoC)
VERBOSE_ACTIVITY_LOGGING = False  # Enable verbose logging of individual HDD activity events
USE_FLASH_STORAGE = True    # Use audio files stored on Pico flash memory instead of SD card

# --- Simulation and Timing Configuration ---
HDD_STATE_CHANGE_DELAY_MS = 50      # Delay for HDD state changes (milliseconds)
MAIN_LOOP_DELAY_MS = 1              # Main loop delay (milliseconds)
SPINUP_PLAYBACK_DELAY_MS = 100      # Delay for spinup audio playback loop (milliseconds)
SIMULATION_ACTIVITY_PROBABILITY = 0.7  # Probability of HDD activity in simulation (0.0-1.0)
SIMULATION_INTERVAL_MS = 5000       # Simulation interval (milliseconds)

# --- Pin Objects and Constants ---
# Pin objects are created in the main program using digitalio.DigitalInOut

def validate_config():
    """Validate configuration values to catch errors early."""
    # Validate GPIO pin ranges (Pico has GPIO 0-29)
    pins_to_check = [
        ADDR_PIN_BASE, IOR_PIN, IOW_PIN, SCK_PIN, MOSI_PIN, MISO_PIN, CS_PIN,
        BCK_PIN, WS_PIN, SD_PIN, MUTE_PIN
    ]
    
    for pin in pins_to_check:
        if not (0 <= pin <= 29):
            print(f"Warning: Invalid GPIO pin number: {pin}")
    
    # Validate address pin count
    if ADDR_PIN_COUNT <= 0 or ADDR_PIN_BASE + ADDR_PIN_COUNT > 30:
        print(f"Warning: Invalid address pin configuration: base={ADDR_PIN_BASE}, count={ADDR_PIN_COUNT}")
    
    # Validate audio settings
    if SAMPLE_RATE_HZ <= 0:
        print(f"Warning: Invalid sample rate: {SAMPLE_RATE_HZ}")
    if BITS_PER_SAMPLE not in [8, 16, 24, 32]:
        print(f"Warning: Invalid bit depth: {BITS_PER_SAMPLE}")
    if CHANNELS not in [1, 2]:
        print(f"Warning: Invalid channel count: {CHANNELS}")
    
    # Validate activity detection settings
    if ACTIVITY_THRESHOLD <= 0:
        print(f"Warning: Invalid activity threshold: {ACTIVITY_THRESHOLD}")
    if ACTIVITY_TIMEOUT_MS <= 0:
        print(f"Warning: Invalid activity timeout: {ACTIVITY_TIMEOUT_MS}")
    
    # Validate debug settings
    if not isinstance(SIMULATION_MODE, bool):
        print(f"Warning: SIMULATION_MODE should be boolean, got: {type(SIMULATION_MODE)}")
    if not isinstance(VERBOSE_ACTIVITY_LOGGING, bool):
        print(f"Warning: VERBOSE_ACTIVITY_LOGGING should be boolean, got: {type(VERBOSE_ACTIVITY_LOGGING)}")
    if not isinstance(USE_FLASH_STORAGE, bool):
        print(f"Warning: USE_FLASH_STORAGE should be boolean, got: {type(USE_FLASH_STORAGE)}")
    
    print("Configuration validation passed")

# Note: Configuration validation is called from main program

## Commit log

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2025-08-17 Create circuitpython_hdd_basic.py
    A working prototype of HDD Synth using voltage detection of the HDD LED line
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2025-08-18 Replace legacy MicroPython main file with CircuitPython
    [main.py]
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2025-10-12 Add KiCad hardware files for prototype MK1
    [HDD Synth.csv, HDD Synth.kicad_pcb, HDD Synth.kicad_sch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]
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2026-02-26 Working MKII implementation
    [HDD Synth prototype MK2.csv, HDD Synth prototype MK2.kicad_pcb, HDD Synth prototype MK2.kicad_sch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]
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2026-03-22 Add Prototype MKIII designs
    [HDD Synth prototype MK3.kicad_pcb, HDD Synth prototype MK3.kicad_sch, ISA_8bit.kicad_pcb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]
2026-03-24 MKIII design refinements
    [HDD Synth prototype MK3.kicad_pcb, HDD Synth prototype MK3.kicad_sch, amplifier.kicad_sch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]
2026-04-12 Add net classes for power
    [HDD Synth prototype MK3.kicad_pcb, HDD Synth prototype MK3.kicad_sch, amplifier.kicad_sch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]
2026-04-12 MKIII PCB components connected and passing DRC
    [HDD Synth prototype MK3.kicad_pcb, HDD Synth prototype MK3.kicad_sch, amplifier.kicad_sch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]
2026-04-13 Switch to GPLv3 licence
    [HDD Synth prototype MK3.kicad_sch]
2026-04-13 Finalise silk screen and tidy up files
    [HDD Synth prototype MK3.kicad_pcb, ISA_8bit.kicad_pcb, IsaTemplate.kicad_pcb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]
2026-04-13 Add manufacturer part nu bers
    [HDD Synth prototype MK3.kicad_sch, amplifier.kicad_sch, isa_ide_activity_detection.kicad_sch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]
2026-04-13 Switch SD card reader to better component
    [HDD Synth prototype MK3.kicad_pcb, HDD Synth prototype MK3.kicad_sch, isa_ide_activity_detection.kicad_sch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]
2026-04-13 Fix DRC issues and change SD card to injection model
    [HDD Synth prototype MK3.kicad_pcb, sdcard_reader.kicad_sch]
2026-04-13 Improve ground connections
    [HDD Synth prototype MK3.kicad_pcb, isa_ide_activity_detection.kicad_sch]
2026-04-13 Add LCSC component part numbers to BOM
    [HDD Synth prototype MK3.kicad_sch, isa_ide_activity_detection.kicad_sch, sdcard_reader.kicad_sch]
2026-04-13 Add LCSC components part numbers
    [HDD Synth prototype MK3.kicad_sch, amplifier.kicad_sch, isa_ide_activity_detection.kicad_sch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]
2026-04-13 Add LCSC component part numbers
    [sdcard_reader.kicad_sch, status_led.kicad_sch]
2026-04-21 Created FDD connections to Pico and other key components
    [HDD Synth prototype MK3-B_Cu.gbl, HDD Synth prototype MK3-B_Mask.gbs, HDD Synth prototype MK3-B_Paste.gbp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]
2026-05-05 MK4 prototype initial work
    [HDD Synth Prototype MK4.kicad_pcb, HDD Synth Prototype MK4.kicad_sch, IDE.kicad_sch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]
2026-05-06 Create initial MK4 PCB layout
    [HDD Synth Prototype MK4.kicad_pcb, HDD Synth Prototype MK4.kicad_sch, IDE.kicad_sch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]
2026-05-10 Placed all components on PCB
    [HDD Synth Prototype MK4.kicad_pcb, HDD Synth Prototype MK4.kicad_sch, oled.kicad_sch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]
2026-05-10 Fixed all Electrical Rule Check errors
    [HDD Synth Prototype MK4.kicad_pcb, HDD Synth Prototype MK4.kicad_sch, IDE.kicad_sch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]
2026-05-17 MK4 PCB layout complete
    [HDD Synth Prototype MK4.kicad_pcb, IDE.kicad_sch, oled.kicad_sch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]
2026-05-19 Final design to sent to PCBWay
    [HDD Synth Prototype MK4.kicad_pcb, IDE.kicad_sch]
2026-06-01 Update MKIV hardware & use MKIII software as basic for MKIV
    [HDD Synth Prototype MK4.kicad_pcb, HDD Synth Prototype MK4.kicad_sch, amplifier.kicad_sch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]
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2026-06-01 Large number of refactorings and minor bug fixes
    [action_button.py, activity.py, audio.py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]
2026-06-02 Gracefully handle missing jingle
    [hddsynth.py]
2026-06-09 Final MKIV tweaks before sending off to PCBWay
    [HDD Synth Prototype MK4.kicad_pcb, HDD Synth Prototype MK4.kicad_sch, HDDSynth_MKIV_BOM.csv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]
2026-06-09 Fix issues when loading SD card settings file
    [hddsynth.py, sd_settings.py]
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2026-06-09 Ensure NO_SD_CARD beep doesn't play when perform SD card init, as this is taken care of later
    [sdcard.py]
2026-06-09 Fix the activity GPIO pin setting
    [settings.py]
2026-06-15 MKIV add RGB LED, reset jumper and fixed reset circuit
    [ATF22V10C-10PU.step, HDD Synth MKIII ISA bracket - Keystone.step, HDD Synth Prototype MK4.kicad_pcb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]
2026-06-16 Make device select text consistent and correct
    [HDD Synth Prototype MK4.kicad_pcb]
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2026-06-16 MKIV tweaks
    [HDD Synth Prototype MK4.kicad_sch, power.kicad_sch]
2026-06-17 MKV design start
    [HDD Synth Prototype MK5.kicad_pcb, HDD Synth Prototype MK5.kicad_sch, IDE.kicad_sch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]
2026-06-18 MKV - SATA connector and wiring complete
    [HDD Synth Prototype MK5.kicad_pcb, HDD Synth Prototype MK5.kicad_sch, power.kicad_sch]
2026-06-18 Hide speaker mount refs + create 3D model
    [HDD Synth Prototype MK5.kicad_pcb]
2026-06-21 Major MKV redesign using embedded RP2350
    [HDD Synth Prototype MK5.kicad_pcb, HDD Synth Prototype MK5.kicad_sch, HDD Synth Prototype MK5b.kicad_pcb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]
2026-06-30 MKV: Add LCSC numbers and resolve DRC errors
    [HDD Synth Prototype MK5.kicad_pcb, HDD Synth Prototype MK5.kicad_sch, RP2350_60QFN_minimal.kicad_sch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]
2026-07-20 Successful MKV software test (after minor modification)
    [HDD Synth Prototype MK5-BOM.csv, HDD Synth Prototype MK5.csv, HDD Synth Prototype MK5.kicad_pcb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]
2026-07-20 Bug and performance fixes
    [activity.py, beep.py, hddsynth.py]
2026-08-03 MKV revision 1
    [HDD Synth Prototype MK5-BOM.csv, HDD Synth Prototype MK5.kicad_pcb, HDD Synth Prototype MK5.kicad_sch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]
2026-08-10 MKV revision 1 enhancements
    - RGB LED support
    - 3D printable 3.5/2.5" drive bay mounts
    [HDD Synth Prototype MK5.kicad_sch, hddsynth_25_sidemount.scad, hddsynth_25_sidemount.stl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]
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2026-08-22 Add buck boost to 5V and reset line stability
    [ATF22V10C-10PU.step, HDD Synth ISA adapter.kicad_pcb, HDD Synth ISA adapter.kicad_sch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]
2026-08-22 Cost reductions for JCLPCB
    [HDD Synth ISA adapter.kicad_pcb, HDD Synth Prototype MK5.kicad_pcb, HDD Synth Prototype MK5.kicad_sch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]
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2026-09-13 MK5 revision 2 hardware updates and ISA adapter revisions
    Ignore VSCode local-history artifacts going forward.
    [HDD Synth ISA adapter.kicad_pcb, HDD Synth ISA adapter.kicad_sch, HDD Synth Prototype MK5.kicad_pcb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]
2026-09-26 eFuse and regular
    [RP2350_60QFN_minimal.kicad_sch, power.kicad_sch]
2026-09-26 Plotted most of PCB layout for eFuse and related chagnes
    [HDD Synth Prototype MK5.kicad_pcb]
2026-09-27 Schematics and layout complete for 5.2.0
    [HDD Synth Prototype MK5.kicad_pcb, power.kicad_sch]
2026-09-29 5.3.0 sent to JCLPCB
    [HDD Synth Prototype MK5-BOM.csv, HDD Synth Prototype MK5.kicad_pcb, RP2350_60QFN_minimal.kicad_sch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]
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
